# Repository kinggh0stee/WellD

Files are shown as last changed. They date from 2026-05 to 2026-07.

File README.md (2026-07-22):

# WellD

Battery-powered well-level monitor for the ESP32-C6. Each wakeup it reads a 4–20 mA submersible pressure transducer, a DS18B20 temperature probe, and battery voltage; reports them over Zigbee to Zigbee2MQTT; then deep-sleeps until the next cycle.

- **Radio:** Zigbee 3.0 over the C6's built-in 802.15.4 — no extra modules
- **Battery life:** months on a single 18650 cell at the default 5-minute interval (deep sleep between readings)
- **Adaptive sleep:** sleep duration scales with how fast the level is changing — longer windows when stable, shorter during transients
- **Rate-of-change reporting:** `water_level_rate` in cm/h; distinguishes "well recovering" from "well being drawn down"
- **Self-healing:** wipes Zigbee NVS state and rejoins fresh after 5 consecutive send failures
- **OTA:** Zigbee OTA Upgrade client, dual 1.5 MB app slots
- **Sentinels:** open-loop (< 3.5 mA) and short-circuit (> 21 mA) transducer faults both report `null` water level so Home Assistant can alert on wiring faults

---

## Hardware — Custom PCB

The current design is a purpose-built custom PCB (outline set at layout — working target ≈100 × 60 mm, sized around the on-board 18650 carrier). Design files, BOM, and assembly guide live in [`hardware/`](hardware/).

### Key ICs

| IC | Role |
|----|---|
| ESP32-C6 module | MCU + Zigbee radio |
| ADS1115 (0x48) | 16-bit I²C ADC — shunt voltage (AIN0) + battery divider (AIN2) |
| HT7333-A | 3.3 V LDO (≈4 µA Iq, 250 mA, ~90 mV dropout). Replaced the AP63203WU buck in the 2026-07-19 1S conversion — the buck's 3.8 V minimum input fails at 1S empty (3.0 V). Below ≈3.4 V the output follows the battery minus dropout; the ESP32-C6 runs down to 3.0 V |
| MT3608B | 12 V **asynchronous** boost for the 4–20 mA loop supply (VLOOP, GPIO5-gated). D15 (SS34 Schottky) rectifies the switch node; a Q3/Q4 load-disconnect switch in series with L1 blocks the permanent VBAT leak to the loop terminals during deep sleep |
| CN3791 | 1S MPPT solar buck charge **controller** (external SI2319CDS P-FET stage; fixed 4.2 V CV, MPPT ≈5.0 V for 6 V-nominal panels; panel Voc limited to **10 V** by the SMAJ10CA input TVS). A solar-powered LM393 cold-charge cutoff clamps charging below ≈+2 °C — zero battery draw at night |
| TP4056 | USB-C 1 A linear charger (2026-07-19 1S conversion — replaced the IP2326 boost selection, which itself replaced the non-functional TP5100). Auto-charges whenever VBUS is present (CE strapped high); charge-temperature NTC window ≈ +5…+44 °C |
| DW01A + FS8205A | On-board 1S battery protection (supervisor + dual N-FET in the cell− path) — added 2026-07-19 with the generic-18650 carrier; a bare cell has no PCM |

### Test points (production / field debug)

All 15 test point pads are 1.0 mm SMD, **DNF** (do not fit) — bare copper pads suitable for ICT fixture probes or a hook wire. No component is installed in production. Test points are placed scattered near their associated circuits rather than grouped in a single row.

| Ref | Net | Ref | Net |
|-----|-----|-----|-----|
| TP1 | VBAT (3.0–4.2 V, 1S range) | TP9 | I2C SCL |
| TP2 | VLOOP (12 V boost) | TP10 | VSOLAR_IN |
| TP3 | +3V3 | TP11 | VBAT_RAW (before D5 reverse-polarity MOSFET) |
| TP4 | GND | TP12 | ADS1115 DRDY (GPIO22) |
| TP5 | LOOP+ (LOOP_TERM_CH1) | TP13 | FACTORY_RESET (GPIO23 — short to GND while powering on) |
| TP6 | LOOP- (LOOP_TERM_CH2) | TP14 | /CHRG_SOLAR (CN3791 charge status) |
| TP7 | 1WIRE | TP15 | /CHRG_USB (TP4056 charge status, with R38 pull-up) |
| TP8 | I2C SDA | | |

### Thermal improvements

The PCB includes a 10 × 10 mm solid GND copper pour on F.Cu and B.Cu centred on the CN3791 solar charger (U7), connected by four thermal vias (0.6 mm drill / 1.0 mm pad) — the CN3791's integrated switch dissipates in-package, so this pour matters more than it did for the CN3722 controller it replaced. A matching pour under the TP4056 EPAD carries the ≈1.3 W of linear charge dissipation at 1 A. A GND via-stitch ring around the MT3608B / L1 boost island provides a low-inductance return path for the switching node without adding a solid pour under L1.

### GPIO map

| GPIO | Direction | Function |
|---|---|---|
| 18 | SDA | I²C bus (ADS1115 only) — GPIO10/11 are not bonded out on the ESP32-C6-MINI-1 module, so I²C is on GPIO18/19 |
| 19 | SCL | I²C bus (ADS1115 only) |
| 12 | USB | Native USB D− → USB-C (console/programming); from U11 USBLC6 |
| 5  | Output | MT3608B EN + Q4 gate — 12 V loop supply (`VLOOP`), with Q3/Q4 load-disconnect; R27 pull-down holds it off during deep sleep |
| 4  | — | Spare — no schematic connection (the TP4056 USB charger is autonomous, CE strapped high in hardware) |
| 6  | Input  | Solar charger /CHRG (CN3791) — solar-charging-active detect (active-low: LOW = charging; R25 external pull-up) |
| 7  | 1-Wire | DS18B20 data |
| 13 | USB | Native USB D+ → USB-C (console/programming) |
| 22 | Input  | ADS1115 ALERT/DRDY (moved off GPIO12) |
| 23 | Input  | Factory reset (hold LOW at boot → NVS erase + rejoin; via TP13; moved off GPIO13) |
| 15 | Output | Battery-divider enable (`BATT_DIV_EN`) — drives the Q2 level-shifter that switches the Q5 high-side P-FET |
| 14 | — | Status LED (D4 via R14/SJ3 — moved off GPIO13, which is reserved for factory reset; no firmware support yet) |

### Connections (screw terminals)

| Terminal | Wire | ESD / surge protection |
|---|---|---|
| LOOP+ / LOOP− | 4–20 mA transducer, two-wire | D9 / D10 SMAJ3.3CA bidirectional TVS (200 W, DO-214AC); D11 SMAJ13A unidirectional TVS on VLOOP; D1 PRTR5V0U2X rail clamp at ADS1115 inputs |
| 1W DATA / GND | DS18B20 data + ground | D12 PRTR5V0U2X dual-channel rail clamp (SOT-363) — 0.5 pF added capacitance, well below the 800 pF 1-Wire add limit |
| Battery | Single generic 18650 (3.0–4.2 V) in the on-board THT carrier **BT1** — no cable, no connector (the XT30 was deleted 2026-07-19) | On-board 1S protection **DW01A + FS8205A** in the cell− path (generic bare cells have no PCM): over-discharge ≈2.4 V, over-charge ≈4.3 V, over-current. D13 SMAJ5.0A TVS at the cell+ tab; D5 AO3407 P-ch MOSFET in series on cell+ blocks a **reversed-inserted cell**; R31 10 kΩ gate pull-down holds D5 on |
| SOLAR+/− | Solar panel, ≤ **10 V Voc** (6 V-nominal panels — 1S conversion 2026-07-19; the 2S design accepted 12 V panels) | D14 SMAJ10CA bidirectional TVS (400 W, DO-214AC) at the terminal, plus second-stage D8 SMAJ10CA at the CN3791 VIN |

### RF / antenna

The ESP32-C6-MINI-1U-H4 module exposes a U.FL RF port. A ~50 mm internal pigtail — **Taoglas CAB.100.07.0050B** (U.FL female to SMA male, RG178 coax) — connects the module to **J3**, an **Amphenol 132289** SMD edge-launch SMA connector on the top board edge. PCBWay hand-attaches the pigtail after reflow. An external 2.4 GHz SMA antenna (e.g. Taoglas FXP73 rubber-duck, 2 dBi) screws directly onto J3.

### Assembly notes (PCBWay)

Connector placement:

- **Bottom edge (left to right):** J12 (solar, 2-pos), J4 (loop ch1, 3-pos), J5 (loop ch2, 3-pos), J6 (DS18B20, 3-pos), J7 (spare sensor, 3-pos), J10 (programming header, 6-pin 1.27 mm pitch)
- **Left edge:** J13 (USB-C — charging **and** console/programming, SMD; D± wired to the ESP32 native USB pins). The BT1 18650 carrier occupies its own top-side band along one long edge (board size is unconstrained, so the outline grows to fit)
- **Top edge:** J3 (Amphenol 132289 SMA edge-launch)

- **J4, J5, J6, J7, J12** — Phoenix Contact MC 1.5/x-G-3.5 THT terminal blocks, wave-soldered.
- **J10** — 1.27 mm pitch THT vertical programming header (6-pin), wave-soldered.
- **J8, J9** (expansion headers) — **DNF** (do not populate) on all production boards. Footprints are present on the PCB for future use; no components are installed.
- **J3** pigtail — hand-attached by PCBWay post-reflow; not wave-soldered.

### 4–20 mA loop

The MT3608B boost converter lifts VLOOP to 12 V to power the transducer loop. The boost is asynchronous: D15 (SS34 Schottky) carries the switch node to VLOOP, and a Q3 (P-FET) / Q4 (level-shifter) load-disconnect switch in series with the inductor prevents VBAT from leaking through L1 + D15 to the loop terminals during deep sleep. GPIO5 drives both the MT3608B EN and the Q4 gate; R27 pulls the net low while GPIO5 is isolated in deep sleep.

Firmware gates GPIO5 high for **10 ms** (MT3608B soft-start plus rail settling through the Q3 load-disconnect P-FET into C20/C22 — raised from 5 ms in the 2026-07 PCB review) before reading, then drives it low immediately after. Maximum ON time is 100 ms.

The ADS1115 measures the voltage across a shunt resistor on the loop return. PGA ±2.048 V, single-shot at 860 SPS, AIN0 vs GND.

10 nF X7R bypass capacitors (C_SH1 / C_SH2) are placed directly across each 100 Ω shunt resistor (R2 / R4) to suppress HF pickup from the loop cable. The RC corner is ~1.6 MHz, well above the measurement bandwidth.

LOOP+ and LOOP– screw terminals are protected by SMAJ3.3CA bidirectional TVS diodes (D9 / D10, 200 W, DO-214AC/SMA). The 3.3 V standoff is above the normal 2 V loop maximum so the TVS does not conduct in normal operation; the ~5.3 V clamp at 10 A provides tighter protection for the ADS1115 AIN absolute-maximum chain than the previous SMAJ5.0CA devices.

The 1W DATA terminal (J6) is protected by D12, a PRTR5V0U2X dual-channel rail clamp in SOT-363 (the same part as D1 at the ADS1115 inputs). D12 clamps the data line to 3V3 + ~0.5 V during an ESD transient in sub-nanosecond response time. The added capacitance per channel is 0.5 pF, which is negligible compared to the 800 pF DS18B20 bus limit and does not affect 1-Wire timing.

### Battery monitoring

Battery voltage is read via the gated resistor divider (R7 100 kΩ / R8 100 kΩ) on ADS1115 AIN2. The divider is disconnected on the **high side** by Q5 (AO3407 P-FET) between VBAT and R7; GPIO15 drives the Q2 level-shifter (AO3400A) that pulls Q5's gate low. GPIO15 is pulsed HIGH for 1 ms before reading, then LOW immediately after — C8 across R8 is 1 nF so the mid-node settles well inside that 1 ms window. With Q5 off the divider is completely dead: AIN2 rests at 0 V through R8, eliminating sleep leakage into the ADS1115 input ESD diodes. The divider ratio is 2.00 (200/100), mapping 4.2 V full charge to 2.1 V — the firmware reads AIN2 with the ADS1115 **±4.096 V** PGA (the ±2.048 V range used for the loop shunt would clip right at full charge).

The BAT+ rail protection chain: **J1 BAT+ → D13 (SMAJ10CA TVS, at terminal) → D5 S→D (AO3407 reverse-polarity MOSFET) → VBAT system rail.**

D13 is a SMAJ5.0A unidirectional TVS (400 W, DO-214AC/SMA). Its 5 V standoff is above the 4.2 V 1S full-charge voltage so it does not conduct in normal operation; its forward diode clamps negative transients. Cable-induction surges are absorbed before they reach D5 and downstream circuits.

D5 (AO3407, SOT-23) is a P-channel MOSFET placed in series on BAT+. Its body diode blocks reverse current when the battery is connected with reversed polarity; in normal operation the MOSFET is on (Vgs = −Vbat — still twice the −1.5 V Vgs(th) max even at the 3.0 V 1S cutoff, though RDS(on) rises somewhat below the −4.5 V datasheet test point; the drop stays in the tens of millivolts at ≤1 A).

R31 (10 kΩ, 0402) connects D5's gate to GND. R31 holds Vgs = −Vbat so the MOSFET is unconditionally on whenever a battery is present, regardless of firmware state.

### Enclosure

The enclosure is designed in [`hardware/case/welld_case.scad`](hardware/case/welld_case.scad). **No separate battery bay is needed any more** — the single 18650 lives in the top-side on-board carrier (BT1), so the case only has to clear ≈19–21 mm above the board. The external footprint follows the final board outline (unconstrained; working target ≈100 × 60 mm) and is sized at layout time. A USB-C slot on the left short wall accommodates the J13 connector (TP4056 charging **and** USB console/programming via the ESP32 native USB). The case dimensions consume the final board layout, so case work stays last.

For concrete underside mounting, the lid grows four corner wings with M6 anchor-bolt clearance holes. The bolt pattern centre-to-centre span is **127 × 82 mm** (X × Y). Use the `drill_template()` module to print a 1:1 paper/card drill guide before installing anchor bolts.

---

## Quickstart

### Prerequisites

- ESP-IDF **v6.0.1** installed and sourced — see the [Espressif getting-started guide](https://docs.espressif.com/projects/esp-idf/en/v6.0.1/esp32c6/get-started/)
- Custom PCB (or dev board — see legacy section below)

### Build and flash

```bash
git clone https://github.com/kinggh0stee/WellD.git
cd WellD

# one-time: select the target chip
idf.py set-target esp32c6

# local config — copy the template and edit it (gitignored)
cp sdkconfig.defaults.local.example sdkconfig.defaults.local
$EDITOR sdkconfig.defaults.local

# build and flash
idf.py build
idf.py -p /dev/ttyUSB0 flash monitor
```

Or use the interactive menu: `idf.py menuconfig` → **WellD Configuration**.

---

## Configuration

All options have sensible defaults. Only change what differs from your hardware.

### Sensor

| Option | Default | Description |
|---|---|---|
| `CONFIG_WELLD_SENSOR_SHUNT_MILLIOHMS` | `100000` | Loop shunt resistor value in milliohms (100 Ω = `100000`) |
| `CONFIG_WELLD_SENSOR_MAX_DEPTH_CM` | `600` | Full-scale depth at 20 mA, in cm |
| `CONFIG_WELLD_SENSOR_OFFSET_CM` | `0` | Level offset in cm applied after conversion (±600). Persisted in NVS; runtime-writable via `sensor_set_offset_cm()` |
| `CONFIG_WELLD_DS18B20_GPIO` | `7` | GPIO connected to DS18B20 data pin |

### Battery

| Option | Default | Description |
|---|---|---|
| `CONFIG_WELLD_BATT_REPORT_ENABLED` | `y` | Report battery voltage over Zigbee (EP2, Analog Input). The battery is always measured internally via ADS1115 AIN2 (R7/R8 divider) for the low-battery guard; disabling this only removes the Zigbee endpoint |
| `CONFIG_WELLD_BATT_DIVIDER_RATIO` | `200` | Divider ratio × 100 — matches the 100 kΩ / 100 kΩ divider (R7/R8): (100+100)/100 = 2.00 |
| `CONFIG_WELLD_BATT_FULL_MV` | `4200` | Voltage (mV) reported as 100 % by the Z2M converter (1S full charge) |
| `CONFIG_WELLD_BATT_EMPTY_MV` | `3000` | Voltage (mV) at or below which the device skips the Zigbee send and all NVS writes to protect flash (1S minimum safe discharge) |

### Sleep

| Option | Default | Description |
|---|---|---|
| `CONFIG_WELLD_SLEEP_DURATION_SEC` | `300` | Baseline sleep between readings (seconds). When adaptive sleep is enabled, this is the "normal rate" window; the heavy-pumping band targets default/2 (integer division), so very short base values fall below `WELLD_SLEEP_MIN_SEC` and are clamped, making that band unreachable |
| `CONFIG_WELLD_ADAPTIVE_SLEEP_ENABLED` | `y` | Scale sleep duration to the observed level rate-of-change |
| `CONFIG_WELLD_SLEEP_MIN_SEC` | `60` | Lower bound on adaptive sleep (seconds) |
| `CONFIG_WELLD_SLEEP_MAX_SEC` | `1800` | Upper bound on adaptive sleep (seconds) |

### Zigbee

| Option | Default | Description |
|---|---|---|
| `CONFIG_WELLD_ZIGBEE_CHANNEL_MASK` | `0x07FFF800` | Channels to scan; narrow to your coordinator's channel to speed up joins |
| `CONFIG_WELLD_ZIGBEE_SEND_DELAY_MS` | `2000` | Time the stack stays alive after sending, to allow coordinator ACK |

### Hardware I/O

| Option | Default | Description |
|---|---|---|
| `CONFIG_WELLD_I2C_SDA_GPIO` | `18` | I²C SDA pin (ADS1115). GPIO10/11 unavailable on the MINI-1 module |
| `CONFIG_WELLD_I2C_SCL_GPIO` | `19` | I²C SCL pin (ADS1115) |
| `CONFIG_WELLD_VLOOP_GPIO` | `5` | MT3608B EN + Q3/Q4 load-disconnect — 12 V loop supply enable. Held HIGH ≥ 10 ms before any 4–20 mA read (rail settles through the Q3 P-FET into C20/C22) |
| `CONFIG_WELLD_SOLAR_DETECT_GPIO` | `6` | Solar charger /CHRG (CN3791) — solar-charging-active detect (active-low) |
| `CONFIG_WELLD_BATT_DIV_EN_GPIO` | `15` | Battery-divider enable — Q2 level-shifter gate, switching the Q5 high-side P-FET |
| `CONFIG_WELLD_ADS1115_DRDY_GPIO` | `22` | ADS1115 ALERT/DRDY interrupt input (moved off GPIO12, now native USB D−) |

### Advanced / diagnostics

| Option | Default | Description |
|---|---|---|
| `CONFIG_WELLD_ADC_OVERSAMPLE_ENABLED` | `n` | Take 3 ADS1115 samples per measurement and report the median. Opt-in for electrically noisy installations (pump motor interference, long cable runs). Costs ~8 ms extra active time per wakeup; leave off for maximum battery life |
| `CONFIG_WELLD_TEMP_COMPENSATION_ENABLED` | `y` | Apply water-density correction to the level reading: `level / (1 + alpha * (temp - 20))`. Suppressed automatically when DS18B20 fails (temp ≤ −127 °C) |
| `CONFIG_WELLD_TEMP_COMPENSATION_PPM_PER_C` | `207` | Water density coefficient in ppm/°C. Depends on `WELLD_TEMP_COMPENSATION_ENABLED`. Typical value for fresh water is 207 ppm/°C; range 0–500 |
| `CONFIG_WELLD_DS18B20_RESOLUTION_BITS` | `11` | DS18B20 conversion resolution: 9 / 10 / 11 / 12 bit. Conversion time: 94 / 188 / 375 / 750 ms. 11-bit gives 0.0625 °C steps — adequate for well water monitoring and saves 375 ms per wakeup vs 12-bit |
| `CONFIG_WELLD_FACTORY_RESET_GPIO` | `23` | If this GPIO is held LOW at boot, NVS is erased and the device rejoins Zigbee fresh (moved off GPIO13, now native USB D+). Internal pull-up enabled; leave unconnected for normal operation |
| `CONFIG_WELLD_SELFTEST_ENABLED` | `n` | Exercise all peripherals on every boot and log PASS/FAIL. Adds ~200 ms to boot time; useful for factory QA and PCB bring-up |
| `CONFIG_WELLD_DIAGNOSTIC_MODE_ENABLED` | `n` | Stay awake for `WELLD_DIAGNOSTIC_STAY_AWAKE_SEC` after each sensor read, printing verbose logs. Deep sleep is still entered after the window expires |
| `CONFIG_WELLD_DIAGNOSTIC_STAY_AWAKE_SEC` | `60` | Stay-awake window when diagnostic mode is enabled (seconds, 10–300). Depends on `WELLD_DIAGNOSTIC_MODE_ENABLED` |
| `CONFIG_WELLD_ZIGBEE_BACKOFF_MAX_MS` | `500` | Random delay before Zigbee network steering on each wakeup (0–5000 ms). Jitters start time to avoid simultaneous steering from multiple devices after a power outage |
| `CONFIG_WELLD_OTA_STALL_TIMEOUT_SEC` | `240` | Maximum wall-clock time an OTA download may take before it is considered stalled and aborted (60–600 s) |
| `CONFIG_WELLD_RTC_LOG_PRINT_ENABLED` | `n` | Print RTC event log on wakeup — enable when diagnosing a retrieved device over USB; leave off in production |

---

## Zigbee2MQTT integration

### 1. Install the external converter (before pairing)

```bash
cp zigbee2mqtt/welld.js /opt/zigbee2mqtt/data/
```

Add it to `/opt/zigbee2mqtt/data/configuration.yaml`:

```yaml
external_converters:
  - welld.js
```

Restart Zigbee2MQTT:

```bash
sudo systemctl restart zigbee2mqtt
```

### 2. Pair the device

Enable permit-join in `configuration.yaml`, power up the board, and wait for the join. First pairing takes up to 25 s; subsequent wakeups rejoin in a few seconds using cached network state in NVS. Disable permit-join once paired.

### 3. MQTT payload

The device publishes to `zigbee2mqtt/<friendly_name>` on each wakeup:

```json
{
  "water_level": 3.42,
  "water_level_rate": 12.5,
  "temperature": 12.3,
  "battery_voltage": 7.41,
  "battery": 59,
  "zb_fails": 0,
  "device_lqi": 156,
  "solar_charging": false
}
```

- `water_level` is `null` when the pressure loop reads below 3.5 mA (open circuit / broken wire) or above 21 mA (short circuit / shorted transducer). Trigger a Home Assistant alert on `water_level is null` to catch both fault conditions.
- `water_level_rate` is signed cm/h. Positive = recovering, negative = drawing down. Omitted on the first valid wakeup after a cold boot and during open-loop cycles.
- `temperature` is omitted when the DS18B20 is not detected.
- `battery_voltage` comes from the ADS1115 AIN2 voltage divider (R7/R8 100 kΩ / 100 kΩ, switched high-side by Q5 under GPIO15 control).
- `battery` is a percentage derived from `battery_voltage` using the device options `battery_full_mv` / `battery_empty_mv`. Options are coerced to numbers (YAML strings like `"4200"` are accepted) and fall back to the defaults 4200 / 3000 mV for anything missing or non-numeric. If the thresholds are misconfigured (`battery_full_mv <= battery_empty_mv`), the voltage is still published but the percentage is omitted.
- `zb_fails` counts consecutive Zigbee send failures since the last success (0 = healthy; the device auto-rejoins at 5).
- `device_lqi` is the link quality measured on the device side (EP6, 1–255) — the LQI of the device's parent entry in its own neighbor table. It is distinct from Zigbee2MQTT's own `linkquality` field, which comes from the coordinator side of the link. A value of 0 means "unknown" (no parent entry found) and is not published. Firmware ≤ 1.0.2 always sent 0, so the key only appears from firmware 1.0.3 onwards.
- `solar_charging` is a **boolean** (binary expose): `true` = the solar MPPT charger (CN3791) is actively charging, `false` = not charging.
- When previous sends failed, the buffered readings (up to 8, RTC store-and-forward) are burst-reported oldest-first before the current reading, so the coordinator receives the full history in order.
- The converter rejects malformed reports: any non-numeric or non-finite `presentValue` is dropped instead of being published.

### 4. Home Assistant

The Z2M–Home Assistant integration auto-creates these entities:

| Entity | Unit / values |
|---|---|
| `sensor.<name>_water_level` | m |
| `sensor.<name>_water_level_rate` | cm/h |
| `sensor.<name>_temperature` | °C |
| `sensor.<name>_battery_voltage` | V |
| `sensor.<name>_battery` | % (omitted when `battery_full_mv <= battery_empty_mv`) |
| `sensor.<name>_zb_fails` | count, 0–255 |
| `sensor.<name>_device_lqi` | device-side LQI, 1–255 (needs firmware ≥ 1.0.3; 0 = unknown is never published) |
| `binary_sensor.<name>_solar_charging` | on / off |

---

## OTA firmware updates

The device runs a Zigbee OTA Upgrade client. Zigbee2MQTT (`ota: true` in the converter) distributes images automatically once placed in its OTA folder.

### 1. Bump the version

Edit `PROJECT_VER` in the root `CMakeLists.txt`:

```cmake
set(PROJECT_VER "1.0.2")   # MAJOR.MINOR.PATCH
```

The OTA file-version `0xMMmmPP00` (major << 24 | minor << 16 | patch << 8; e.g. `1.0.2` → `0x01000200`) is derived from `PROJECT_VER` at build time — **don't edit `OTA_FW_VERSION` directly.** The build fails loudly on a malformed `PROJECT_VER`.

### 2. Build the OTA image

After `idf.py build`, wrap the binary using `ota_image_create.py` from the esp-zigbee-sdk:

```bash
python path/to/ota_image_create.py \
    --manufacturer-code 0x1234 \
    --image-type 0x0001 \
    --file-version 0x01000200 \
    --output welld-v1.0.2.zigbee \
    build/welld.bin
```

`--manufacturer-code` and `--image-type` **must** match the constants in `components/zigbee/zigbee.c` (`0x1234` / `0x0001`). The device rejects mismatched headers — don't wildcard them to `0xFFFF`.

`--file-version` must increase monotonically and match the `0xMMmmPP00` encoding of `PROJECT_VER`; the device only installs images with a higher version than the running one. (CI derives it automatically and uploads the packed `.zigbee` file as a build artifact.)

### 3. Deploy

```bash
cp welld-v1.0.2.zigbee /opt/zigbee2mqtt/data/ota/
```

Zigbee2MQTT picks the file up automatically. On the next wakeup the device queries for an update, downloads it in 128-byte blocks over Zigbee, and reboots into the new firmware.

> **Upgrading from ≤ 1.0.2:** firmware 1.0.3 adds the battery endpoint (EP2) to the device descriptor. Zigbee2MQTT caches the endpoint list from the original interview, so after the OTA completes, re-interview the device (Z2M frontend → device → *Reconfigure/Interview*, or re-pair) to surface the new `battery_voltage` / `battery` entities. Also note the Kconfig option rename below — a stale `CONFIG_WELLD_BATT_ADC_CHANNEL=-1` line in `sdkconfig.defaults.local` is silently ignored; set `CONFIG_WELLD_BATT_REPORT_ENABLED=n` if you want battery reporting to stay off.

### OTA rollback guard

The firmware tracks consecutive boot failures in RTC memory. If 3 consecutive boots complete without a successful Zigbee send, the device automatically rolls back to the previous image in the **inactive OTA slot** (`esp_ota_get_next_update_partition()` — nothing in this app-level scheme ever marks the old slot invalid, so `esp_ota_get_last_invalid_partition()` would never fire). The rollback is skipped when the inactive slot holds no valid image (first flash), and the boot-attempt counter is cleared before the restart so the rolled-back image doesn't immediately bounce back to the broken slot. This prevents a bad OTA image from permanently bricking the device in the field.

---

## Operations

### Level offset calibration

Use `CONFIG_WELLD_SENSOR_OFFSET_CM` (or `sensor_set_offset_cm()` at runtime) to shift the reported level without moving the transducer. For example, if the transducer hangs 15 cm above the well bottom, set the offset to `-15` to report depth from the bottom of the well.

The offset is persisted in NVS (key `offset_cm` in namespace `welld`) and clamped to ±600 cm.

### Adaptive sleep & rate of change

The device remembers its last valid reading and elapsed time in RTC slow memory (preserved across deep sleep, zeroed on cold boot). At each wakeup it computes a signed rate of change in cm/h and uses it to:

1. **Report `water_level_rate`** to Zigbee2MQTT.
2. **Adjust the next sleep duration** when `CONFIG_WELLD_ADAPTIVE_SLEEP_ENABLED=y`:

   | Rate (cm/h) | Sleep target | Interval at defaults | Condition |
   |-------------|--------------|----------------------|-----------|
   | 0 – 2       | max          | 1800 s | well at rest |
   | 2 – 5       | default × 2  | 600 s  | slow drawdown |
   | 5 – 10      | default      | 300 s  | active pumping |
   | 10 – 20     | default / 2  | 150 s  | heavy pumping |
   | ≥ 20        | min          | 60 s   | rapid event |

   The middle bands scale from `WELLD_SLEEP_DURATION_SEC` (integer division for the /2 band); the result is always clamped to `[WELLD_SLEEP_MIN_SEC, WELLD_SLEEP_MAX_SEC]`, so a very short base value makes the heavy-pumping band collapse into the minimum.

Set `CONFIG_WELLD_ADAPTIVE_SLEEP_ENABLED=n` for a fixed reporting cadence.

### Factory reset

Hold `CONFIG_WELLD_FACTORY_RESET_GPIO` (default GPIO23) LOW during boot to erase NVS and force a clean Zigbee rejoin. On the custom PCB, short the TP13 pad to GND (TP4) while powering on. The internal pull-up is enabled; leaving the pin unconnected causes normal operation. This is the same NVS erase that occurs automatically after 5 consecutive Zigbee send failures.

### I2C bus recovery

On every boot, `sensor_i2c_init()` checks whether SDA is stuck LOW (a common symptom of a previous aborted transaction). If SDA is LOW, it clocks 9 SCL pulses to force any stuck I2C slave to release the bus before initialising the I2C master. This is a no-op under normal conditions.

### Pre-sleep GPIO and I2C cleanup

Before every `esp_deep_sleep()` call, `sensor_pre_sleep_cleanup()` is invoked automatically. It removes the ADS1115 DRDY ISR (GPIO22), deletes the I2C semaphore, and releases the I2C bus handles for GPIO18 (SDA) and GPIO19 (SCL). Without this step the I2C driver retains ownership of those GPIOs across the sleep boundary; the driver context is invalid after wakeup and the bus can be left in a partially-driven state. Combined with `esp_sleep_gpio_isolate()`, all GPIOs are in a defined low-leakage state before the core powers down.

### Low-battery protection

When battery voltage drops **to or below** `CONFIG_WELLD_BATT_EMPTY_MV`, the device skips the Zigbee send and all NVS writes, and sleeps for the maximum interval to conserve charge. The rate history is invalidated entirely on this path — the level can drift arbitrarily far across a low-battery blackout, so the first valid reading after recovery re-seeds the history and reports no rate once (the EP4 report is skipped) instead of producing a false rate spike.

### Expected serial output

Normal cycle:

```
I (sensor): voltage=1485 mV  current=14850 µA  level=3.42 m
I (sensor): temperature=12.3 °C
I (sensor): battery=7.41 V (ADS1115 AIN2)
I (zigbee): joined; reporting level=3.42 m battery=7.41 V temp=12.3 °C rate=12.5 cm/h
I (main):   sleeping 300 s
```

Solar charging active:

```
I (main): solar charging active (solar /CHRG asserted)
```

No coordinator in range:

```
E (zigbee): timeout — no coordinator found
W (main):   Zigbee send failed (1/5)
I (main):   sleeping 300 s
```

After 5 consecutive failures the NVS partition is erased on the next boot, forcing a clean Zigbee rejoin.

Pressure transducer disconnected (open loop, < 3.5 mA):

```
E (sensor): transducer open loop (voltage=12 mV, 120 µA < 3.5 mA)
```

Pressure transducer short circuit (> 21 mA):

```
E (sensor): transducer short-circuit (voltage=2400 mV, 24000 µA > 21 mA)
```

DS18B20 ROM change (sensor replaced):

```
W (sensor): DS18B20 ROM changed: stored=28ff1234ab000002 active=28ff5678cd000003
```

---

## Power

The device spends nearly all of its time in deep sleep. Each wakeup is typically 6–12 seconds of active current (I²C reads, Zigbee send, 1-Wire conversion), followed by a sleep window of 1–30 minutes depending on rate-of-change. At the default 5-minute interval, average current is well under 1 mA — months of runtime on a single 18650 (3.6 V nominal, ≈3–3.4 Ah for a quality generic cell). The HT7333-A LDO's ≈4 µA quiescent current keeps the standby draw negligible, and the Q3/Q5 high-side disconnect switches leave no DC path from VBAT during sleep except the LDO and IC quiescents. Charging is dual-path: solar via the CN3791 MPPT charger and USB-C via the TP4056 (both autonomous — they charge whenever their input is present).

Both power-control GPIOs (VLOOP, BATT_DIV_EN) are driven low and the GPIO matrix is isolated (`esp_sleep_gpio_isolate()`) before every `esp_deep_sleep()` call to eliminate leakage through partially-driven outputs during sleep.

---

## Development

### Project layout

```
main/                    wakeup orchestration, NVS fail counter, RTC history
components/sensor/       I²C (ADS1115), DS18B20, GPIO power control
components/zigbee/       esp-zigbee-lib wrapper, OTA client, BDB commissioning task
components/welld_core/   pure helpers (rate-of-change, adaptive sleep, ZCL encoding)
zigbee2mqtt/welld.js     external converter for Zigbee2MQTT
hardware/pcb/            PCB design reference, BOM, Gerber generation script
hardware/case/           OpenSCAD parametric enclosure (cell lives on the PCB — no battery bay)
test/sensor/             on-device Unity tests (1-Wire, NVS round-trips)
test/welld_core/         on-device Unity tests (rate, sleep, ZCL helpers)
test/host/               host CMake test project — no ESP-IDF required
```

### Host tests

Pure helpers (`sensor_level_from_mv`, `sensor_battery_from_mv`, `sensor_temp_in_range`, `welld_*`) are exercised by a plain CMake project under `test/host/`:

```bash
cmake -S test/host -B test/host/build
cmake --build test/host/build
ctest --test-dir test/host/build --output-on-failure
```

CI runs these on every push. No ESP-IDF or hardware required.

### On-device tests

For NVS round-trips and 1-Wire / ADC paths the host runner can't cover:

```bash
idf.py -C test/sensor build flash monitor
idf.py -C test/welld_core build flash monitor
```

CI builds these to catch compile breaks but cannot execute them (real hardware needed).

### CI

`.github/workflows/build.yml` runs six jobs:

- **ESP-IDF build** — v6.0.1, `esp32c6`, builds firmware and OTA image, uploads `*.bin`, `*.elf`, `*.map`, `*.zigbee`, `dependencies.lock`
- **C static analysis** — cppcheck over all `main/` and `components/` C sources; fails the build on any finding
- **Version bump check** — PR-only gate; fails if firmware sources changed without bumping `PROJECT_VER` in `CMakeLists.txt`
- **Host unit tests** — plain `ubuntu-latest`, ctest, fetches Unity v2.6.0
- **On-device test build** — compile-only check for `test/sensor` and `test/welld_core`
- **Z2M converter tests** — Node 20, `npm test` in `zigbee2mqtt/`

---

## Legacy: dev board wiring

If building from an off-the-shelf ESP32-C6 dev board instead of the custom PCB, wire the pressure transducer shunt directly to an ADC1 pin and power the loop externally. The ADS1115 and MT3608B boost are not available on a bare dev board — configure `CONFIG_WELLD_SENSOR_ADC_CHANNEL` to the ESP ADC channel used and set `CONFIG_WELLD_BATT_REPORT_ENABLED=n` (no battery divider on a bare dev board, so EP2 would only report read errors). The power-control GPIO options (`VLOOP`, `BATT_DIV_EN`) are still compiled in but can be left disconnected if the solar charger is absent.

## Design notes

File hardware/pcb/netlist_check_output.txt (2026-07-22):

pins checked      : 393
intended nets     : 75
extracted nets ok : 75
no-connect pins   : 10

RESULT: zero mismatches — schematic connectivity matches schematic_connections.md table.

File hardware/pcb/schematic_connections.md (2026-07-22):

# WellD Schematic — Net Connectivity Reference

**Wiring status (2026-07-19): the schematic sheets are fully wired — now as a 1S power architecture with an on-board battery carrier.** Every symbol pin carries its connectivity in `power/mcu/sensors/interfaces.kicad_sch` (generated by `kicad_wire_script.py`, machine-verified by `netlist_check.py` — see `netlist_check_output.txt`: **391 pins / 75 nets / 12 no-connects / 0 mismatches** after the 1S conversion + battery carrier + CN3791 correction + solar cold-charge cutoff). This document is a **descriptive reference**; if the sheets and this document ever disagree, treat it as a bug and reconcile (the netlist-vs-doc diff script will flag it).

**Battery architecture (changed 2026-07-19, design changes #18 + #19):** the design is now **1S Li-ion** — a **single generic 18650 cell in an on-board carrier (BT1)**, **VBAT 3.0–4.2 V**. The XT30 pack connector (J1) is deleted, and because a generic bare cell has no PCM, discrete 1S protection (**U13 DW01A + Q6 FS8205A**, the standard TP4056-ecosystem pair) sits between cell− and system GND. The 2S1P architecture (6.0–8.4 V) and its charger chain (IP2326 5 V→2S boost, CN3722 2S MPPT controller + external buck stage, AP63203WU buck) are deleted. **Decision context, for the record:** a runtime analysis slightly favored 2S (≈320 vs ≈300 days per charge); the user explicitly chose 1S anyway ("lets switch this to a 1s design then") for simplicity and parts-ecosystem reasons. 1S is a deliberate product decision — do not re-litigate it in later reviews.

**Connectivity style:** the sheets use *stub + label* connectivity, not point-to-point routed wires — each pin has a short grid-aligned wire stub with a net label (electrically identical for netlisting/ERC):

- **power rails** (`GND`, `+3V3`, `+3V3_ADS`, `VBAT`, `VBAT_RAW`, `VLOOP`, `VUSB`, `VUSB_IN`, `VSOLAR`, `VSOLAR_IN`) → **global labels** (the decorative corner power symbols were removed; `PWR_FLAG` symbols drive ERC on GND / +3V3 / +3V3_ADS / VUSB / VSOLAR);
- **cross-sheet signals** → **hierarchical labels** + matching sheet pins on `welld.kicad_sch`, joined at the root by stubs + local labels;
- **sheet-local nets** → local labels;
- **unused pins** → explicit `(no_connect)` markers. Currently 11: **DW01A TD**, **CN3791 /DONE** (no spare GPIO; pad available for a future TP), **TP4056 /STDBY** (only /CHRG is monitored), ESP32 **GPIO4** (spare) and the phantom **GPIO10 / GPIO11** custom-symbol pins (**not bonded on the MINI-1 module** — they vanish at the official-symbol swap; I²C moved to GPIO18/19), ADS1115 AIN3, D12 IO2, J3 RF pin.

**Convention:** connections below are given by **pin name** (as printed on the symbol), not pin number. Several custom symbols have unverified pin *numbers* — see [Symbol pin-number verification](#symbol-pin-number-verification) before assigning footprints.

---

## Design changes — 2026-07-05 electrical review

| # | Change | Reason |
|---|---|---|
| 1 | **U1 changed AP63205WU → AP63203WU** (fixed 3.3 V); R_FBH/R_FBL marked **DNP** | AP63205 is the **5 V fixed** variant of the Diodes AP6320x family; AP63203 is the 3.3 V fixed variant. The previously specified divider math (0.6 V ref) matches no part in this family (adjustable AP63200 uses a 0.8 V reference). Any of the previous combinations would have put 4.4–8 V on the 3V3 rail and destroyed the ESP32. **Verify against the Diodes datasheet before ordering** (see verification blockers). |
| 2 | **MT3608B topology corrected** (boost: VBAT→L1→SW, not SW→L1→VOUT) and **D15 rectifier + Q3/Q4 load-disconnect added** | The MT3608 family is an async boost: the inductor goes from VIN to SW and an external Schottky (D15) carries SW→VLOOP. Without a disconnect switch, VBAT−0.4 V leaks through L1+D15 to the loop terminals permanently, powering the transmitter during deep sleep and killing the battery. |
| 3 | **Status LED moved GPIO13 → GPIO14** (net renamed `GPIO14_LED`) | At the time, firmware used GPIO13 as the factory-reset strap (a green LED + 1 kΩ to GND would hold it below V_IH → factory reset on every boot). GPIO14 was spare. TP13 added as the factory-reset pad. *(Factory reset later moved to GPIO23 with the 2026-07-22 USB-C change; the LED stays on GPIO14.)* |
| 4 | **Battery divider switched to high-side disconnect** (Q5 P-FET added, Q2 becomes its gate driver); **C8 100 nF → 1 nF** | With the old low-side Q2, the mid node was pulled to VBAT through R7 when disabled, biasing ADS1115 AIN2 above VDD via its ESD diode (~14 µA continuous sleep drain — defeating the purpose of the switch). C8 at 100 nF gave τ ≈ 7.7 ms, far too slow for the firmware's ≥1 ms enable window; 1 nF settles in <1 ms. |
| 5 | **R25 pull-up added on /CHRG_SOLAR** | Gate rule: open-drain outputs need external pull-ups; GPIO6 previously relied on the ESP32 internal ~45 kΩ pull-up only. |
| 6 | **R27 pull-down added on VBOOST_EN** | GPIO5 is isolated (floats) in deep sleep; a floating MT3608B EN (and Q4 gate) could randomly enable the 12 V boost while asleep. |
| 7 | **R15 + C36 added on ESP32 EN** | ESP32-C6-MINI-1U requires an external RC on EN (10 kΩ to 3V3, 1 µF to GND) for a clean power-on reset; only SW1 was present. |
| 8 | **D8/D14 changed SMAJ28CA → SMAJ24CA; C17 uprated to 35 V** | SMAJ28CA standoff equals the CN3722 28 V abs max — zero clamp margin (senior review warning #5). Consequence: max permitted panel Voc is now **24 V** (12 V-nominal panels, Voc ≈ 21–22 V, still fine). C17 at 25 V had no margin over a 24 V standoff rail. |
| 9 | **C25 deleted from power.kicad_sch** (duplicate of C_BST); **C16 assigned as U1 VIN bulk 10 µF** | Resolves senior review warnings #8 and #9; the AP6320x datasheet input cap is 10 µF, previously only 100 nF + 1 µF were fitted. |
| 10 | Refdes reconciliation: `R_CC1/R_CC2` → **R50/R51**, `C14a–C14d` → **C13, C30–C33**, `C_SH1/C_SH2` → **C34/C35**; **R38 is the TP5100 /CHRG pull-up** (the solar /CHRG pull-up is new R25); TP1=VBAT, TP3=+3V3, TP4=GND | Docs referred to symbols that do not exist in the schematics under those names. |
| 11 | **TP5100 USB charge path flagged NON-FUNCTIONAL as designed** | TP5100 is a switching **step-down** (buck) 2S/1S charger. It cannot charge an 8.4 V pack from 5 V USB — VIN must exceed the pack voltage. Superseded by change #12. |
| 12 | **U12 replaced TP5100 → Injoinic IP2326** (5 V→2S synchronous **boost** charger, ESOP-8); **L3 boost inductor added**; R35 repurposed as ISET (value TBD); **R36/R37 deleted — GPIO4/USB_CE freed**; R38 reassigned to the IP2326 status pin; NTC strap placeholder added; **F2 uprated 1.1 A → 2 A hold** (boost input ≈1.9 A at 1 A charge) | Component-selection review 2026-07-05 (`component_selection_review.md` §1). Resolves change #11. IP2326 auto-runs on VBUS — no charge-enable GPIO (⚠️ verify EN absence, plus full pinout/CV/ISET/mid-cell-balance behaviour: blocker #2). Firmware must be told GPIO4 is no longer USB_CE. |
| 13 | **CN3722 CV divider corrected — R33 590 kΩ → 243 kΩ** (CRITICAL, 2026-07-13) | The CV math assumed a 1.205 V FB reference — that is the **CN3791's** reference. The CN3722's **V_FB = 2.416 V** (2.392–2.44, datasheet Rev 1.1). As previously documented, the divider would have regulated the pack at 2.416 × (1 + 5.9) ≈ **16.7 V — destructive for a 2S pack**. Formula: **V_REG = 2.416 × (1 + R_FBH/R_FBL)**. New values: R33 = 243 kΩ (E96) / R34 = 100 kΩ → **8.287 V** (safe margin under 8.40 V). |
| 14 | **CN3722 symbol redrawn as TSSOP-16 + external buck stage added** (M_SOLAR P-FET, D16 series Schottky, D_SOLAR catch Schottky, L_SOLAR, R19 repurposed as R_CS 0.4 Ω, C_VG + COM1/2/3 compensation network, RT_SOLAR NTC on TEMP) | Datasheet Rev 1.1: the CN3722 is a **controller, not an integrated switcher** — DRV (16) drives an external P-FET; charge current is set by a CSP/BAT sense resistor (I_CH = 0.2 V / R_CS → 0.4 Ω = 500 mA), **not** by a "VPROG" resistor (no such pin exists — the old 8-pin symbol was fiction). TEMP (6) gets a real 10 k NTC → cold-charge cutoff (review O-1). Sleep current into BAT pin: 10 µA typ at V_BAT = 12 V (blocker #4a answered — power budget). |
| 15 | **MPPT divider corrected — R20 36 kΩ → 158 kΩ** | Same root cause as #13: the MPPT pin regulates the panel to **1.04 V** at the divider mid-point (not 1.205 V), so the old values would have set V_MP ≈ 4.8 V — below the CN3722's own UVLO (7.5 V min VCC) and useless for charging an 8.4 V pack through a buck. New: V_MP = 1.04 × (1 + 158/10) ≈ **17.5 V**, matching a 12 V-nominal (36-cell) panel, Voc ≤ 24 V. ⚠️ Adjust R20 to the actual panel's V_MP before ordering. |
| 16 | **Symbol reconciliation pass (2026-07-13)** — all BOM-only components now placed as schematic symbols; MT3608B symbol pin numbering fixed (was IN=1/SW=5; now **SW=1, GND=2, FB=3, EN=4, IN=5, NC=6**); IP2326 drawn as the verified 24-pin+EPAD part | Clears senior review 2026-07-06 CRITICAL 1–3 (the layout/ordering gate). Wiring is still doc-driven — this pass places symbols with correct pin definitions and values only. |
| 17 | **Wiring pass (2026-07-13)** — all four sheets fully wired via stub+label connectivity; top sheet rebuilt (rails moved off sheet pins onto global labels; 55 signal sheet pins regenerated); 21 explicit no-connects; PWR_FLAGs added; MT3608B **pin 6 etype changed no_connect → passive** so C_BST can legally attach (doc: "harmless if fitted to an NC pin"); netlist machine-verified against this document (395 pins / 77 nets / 0 mismatches) | Clears senior review 2026-07-06 open item #3 (wire the sheets + netlist-vs-doc diff). New net names minted where the doc had none: `LED_K` (D4 cathode → SJ3), `VLOOP_CH2` (SJ2 → J5 LOOP+), `1WIRE_TERM` (terminal side of R32), `UART_TX_HDR`/`UART_RX_HDR` (SJ4/SJ5 → J10), `J6_VCC`, `D7_A`, `D5_GATE`, `U1_EN`, `AP_SW`, `MT_BST`, `Q3_GATE`, `CC1`/`CC2`, `USB_DP`/`USB_DM`, `USB_BST`, `USB_VSET`, `USB_NTC`, `USB_ISET`, `CN_COM1/2/3`, `COM2_RC`, `LED_A`, `GPIO8`, `GPIO0–3/20/21`. `AP_FB` exists only as the floating DNP divider mid-point (R_FBH.2/R_FBL.1); U1 FB is tied **directly** to +3V3 — fitting the adjustable AP63200 option requires attaching AP_FB to FB and breaking the direct tie. |
| 18 | **1S CONVERSION (2026-07-19)** — pack 2S1P → 1S (VBAT 3.0–4.2 V; battery mechanics finalised in #19). **U12 IP2326 boost-charger subsystem deleted** (U12, L3, R_VSET, C_BST2, C_SYS1/C_SYS2, R35) → **TP4056 1 A linear 1S charger** (SOP-8+EPAD; R_PROG 1.2 kΩ → 1 A; RT1 NTC kept on TEMP with new R_NTC 5.6 kΩ top resistor; CE strapped high; /CHRG → existing /CHRG_USB net). **U7 CN3722 controller + external buck stage deleted** (M_SOLAR, D16, C_COM1/2/3, R_COM2, R33/R34 CV divider) → **CN3791 1S MPPT buck charger** (integrated switch, fixed 4.2 V CV at BAT; D_SOLAR/L_SOLAR/C_VG/RT_SOLAR/R19/R20/R21 kept & repurposed; MPPT set ≈5.0 V for a 6 V panel via R20/R21 = 316k/100k, 1.205 V MPPT reference). **U1 AP63203WU buck deleted** (VIN min 3.8 V fails at 1S empty; L2, C_BST_AP, R_FBH/R_FBL, R11 removed) → **HT7333-A 250 mA LDO** (30 nA-class EN-less part; 3.3 V out, ~90 mV dropout, 4 µA Iq). TVS re-rates: D13 → SMAJ5.0A (VBAT max 4.2 V), D8/D14 → SMAJ10CA (panel ≤6 V nominal). Battery divider R7 330k → **100k** (divide-by-2, firmware ratio 430 → 200). MT3608B VLOOP stage unchanged. GPIO map unchanged (GPIO6 still reads active-low /CHRG_SOLAR; GPIO4 now genuinely spare in hardware). | User decision: 1S chosen deliberately for simplicity/ecosystem after an analysis that slightly favored 2S (≈320 vs ≈300 days runtime). All power-rail ICs reviewed for the 3.0–4.2 V range in the same pass. |
| 19 | **BATTERY CARRIER (2026-07-19)** — the Sinowatt 1S2P pack is dropped for a **single generic 18650 in an on-board THT carrier (BT1**, replaces J1 XT30**)**. Generic bare cells have no PCM → discrete 1S protection added: **U13 DW01A** supervisor + **Q6 FS8205A** dual N-FET in the cell− → GND path (new nets BATT_N / DW_VCC / DW_OD / DW_OC / DW_CS / DW_D; R_DW1 100 Ω + C_DW 100 nF VCC filter, R_CS_DW 1 kΩ on CS — the exact TP4056-module reference topology). D5 reverse-polarity P-FET stays (reverse *insertion* is now a real user risk); D13 SMAJ5.0A stays on VBAT_RAW. RT1/RT_SOLAR thermal coupling target is now the carrier/cell. Capacity ≈3–3.4 Ah (single cell, was ≈6.7 Ah 2P). | Pinouts drawn from the ubiquitous community maps — **verify against the Fortune DW01A-G and FS8205A datasheets before ordering (blocker #11)**. |

---

## Net Inventory

| Net name | Voltage | Description |
|---|---|---|
| GND | 0V | Ground plane |
| +3V3 | 3.3V | Main logic rail (U1 HT7333-A LDO output) |
| VBAT | 3.0–4.2V | 1S2P Li-ion battery (raw, after D5 load-switch) |
| VBAT_RAW | 3.0–4.2V | Cell positive before D5 (BT1 +, D13, D5 drain, R_DW1 feed) |
| BATT_N | ≈0V | Cell negative (BT1 −) — **not** system GND: joined to GND through the Q6 protection FETs |
| DW_VCC | 3.0–4.2V | DW01A supply (R_DW1/C_DW filtered from cell+) |
| DW_OD / DW_OC | gate drive | DW01A discharge/charge FET gate outputs → Q6 G1/G2 |
| DW_CS | ≈0V | DW01A current-sense input (R_CS_DW to system GND) |
| DW_D | ≈0V | Q6 common-drain node (D1+D2 tied) |
| VUSB | 5V | USB-C VBUS after F2 polyfuse |
| VUSB_IN | 5V | USB-C VBUS raw (J13 VBUS pins, before F2) |
| VSOLAR | ≤10V (Voc) | Solar input after D6 diode = CN3791 VCC node (6 V-nominal panel) |
| VSOLAR_IN | ≤10V (Voc) | Solar panel raw (J12 terminal, before D6) |
| VLOOP | 12V ±5% | Boost output (MT3608B + D15), loop power |
| VLOOP_SW | switching | MT3608B SW node (L1 / D15 anode / C_BST) |
| VLOOP_L | 3.0–4.2V gated | Q3 drain → L1 input (boost disconnect branch) |
| +3V3_ADS | 3.3V filtered | ADS1115 VDD (after FB1 ferrite bead) |
| MT_FB | 0.6V | MT3608B feedback divider mid-point (R23/R24) |
| MPPT_REF | 1.205V | CN3791 MPPT (6) divider mid-point (R20/R21 = 316k/100k → V_MP ≈ 5.0 V; ✅ 1.205 V ref datasheet-verified) |
| SOLAR_SW | switching | M_SOLAR drain → D16 anode (external P-FET buck — the CN3791 is a **controller**, verified 2026-07-19) |
| SOLAR_FW | switching | Freewheel node: D16 cathode / D_SOLAR cathode / L_SOLAR in |
| CN_DRV | gate drive | U7 DRV (10) → M_SOLAR gate; R_DRV 300 k gate–source pull-off |
| CN_CS | 3.0–4.2V | Current-sense node: L_SOLAR out / R19 (R_CS 0.1 Ω) / U7 CSP (8); ✅ I_CH = 120 mV/R_CS verified → 1.2 A |
| CN_VG | analog | U7 VG (1) gate-driver regulator — C_VG 100 nF to **VCC** (✅ datasheet-verified) |
| CN_COM / COM_RC | analog | U7 COM (5) loop compensation: 220 nF + 120 Ω series to GND (✅ datasheet values) |
| NTC_T | 0–0.5·VSOLAR | Cold-cutoff temperature node: R_NT1 (30 k) / RT_SOLAR (10 k B3950) divider → U14 IN1+ (ratiometric — threshold independent of panel voltage) |
| NTC_REF | 0.5·VSOLAR | Cold-cutoff reference node: R_NT2/R_NT3 (100 k/100 k) → U14 IN1− (also parks unused IN2−) |
| NTC_OUT | 0/VSOLAR | U14 OUT1 (o.c., R_PU 100 k) → Q7 gate; R_HYS 330 k back to NTC_T gives ≈2 °C hysteresis |
| ADS_DRDY | signal | ADS1115 ALERT/RDY open-drain → GPIO22 (R_DRDY pull-up); moved off GPIO12 = USB D− |
| I2C_SDA | signal | I²C SDA → **GPIO18** (R9 pull-up) — moved off GPIO10 (not bonded on MINI-1, 2026-07-21) |
| I2C_SCL | signal | I²C SCL → **GPIO19** (R10 pull-up) — moved off GPIO11 |
| ADC_CH0 | 0–2.0V | ADS1115 AIN0 (CH1 4-20mA after protection chain) |
| ADC_CH1 | 0–2.0V | ADS1115 AIN1 (CH2 4-20mA after protection chain) |
| ADC_CH2 | 0–2.1V | ADS1115 AIN2 (battery divider mid-point, ÷2) — firmware must use the ±4.096 V PGA range |
| VBAT_SW | 3.0–4.2V gated | Q5 drain → R7 top (battery divider, gated) |
| Q3_GATE / Q5_GATE | analog | P-FET gate nodes (level-shifted from GPIO5 / GPIO15) |
| 1WIRE | signal | DS18B20 data → GPIO7 (R6 pull-up) |
| LOOP_TERM_CH1/2 | signal | 4-20mA SIG inputs from J4/J5 |
| SHUNT_IN_1/2, SHUNT_OUT_1/2 | analog | Shunt chain intermediate nets (see ADC_CH0/1) |
| /CHRG_SOLAR | signal | CN3791 /CHRG (open-drain, active-low) → GPIO6, R25 pull-up |
| /CHRG_USB | signal | TP4056 /CHRG (open-drain, LOW = charging) → R38 pull-up → TP15 only |
| ~~USB_CE~~ | — | **DELETED 2026-07-05** — and finally moot 2026-07-19: TP4056 CE is strapped high in hardware; **GPIO4 is spare, no schematic connection** |
| USB_PROG | analog | TP4056 PROG pin → R_PROG 1.2 kΩ → GND (I_CH = 1200 V·Ω⁻¹… per DS: 1 A at 1.2 kΩ) |
| USB_NTC | analog | TP4056 TEMP pin: R_NTC 5.6k from VUSB, RT1 10k NTC to GND (✅ computed window **+8…+44 °C**) |
| BATT_DIV_EN | signal | GPIO15 → Q2 gate (HIGH enables battery divider via Q5) |
| VBOOST_EN | signal | GPIO5 → MT3608B EN + Q4 gate (HIGH = 12V loop on); R27 pull-down |
| GPIO14_LED | signal | Status LED (GPIO14 → R14 → D4 → SJ3 → GND) |
| FACTORY_RESET | signal | GPIO23 → TP13 pad (hold LOW at boot = NVS erase); moved off GPIO13 = USB D+ |
| UART_TX / UART_RX | signal | Debug UART GPIO16/GPIO17 → SJ4/SJ5 → J10 |
| EN | signal | ESP32-C6 EN (R15 pull-up, C36, SW1, J10) |
| BOOT | signal | ESP32-C6 GPIO9 (R12 pull-up, SW2, J10) |

---

## Net-by-Net Pin Connections

### GND

| Component | Pin | Note |
|---|-----|---|
| U1 HT7333-A | GND (1) | LDO GND |
| U7 CN3791 | GND (2) | Solar charger GND |
| U8 MT3608B | GND | Boost GND |
| U9 ADS1115 | GND **and ADDR** | ADDR→GND sets I²C address 0x48 |
| U6 ESP32-C6-MINI-1U | GND (all) | Module GND + thermal pad |
| U11 USBLC6-2SC6 | GND | USB ESD clamp |
| U12 TP4056 | GND (3) + EPAD | Charger GND + thermal pad (needs copper pour — 1 A linear charge dissipates ≈1.3 W peak; thermal regulation folds back) |
| R_PROG | pin 2 | TP4056 PROG resistor low side (1.2 kΩ → 1 A) |
| RT1 | pin 2 | TP4056 TEMP (pin 1) NTC low side |
| D_SOLAR | anode | CN3791 catch Schottky (cathode → SOLAR_SW) |
| D1, D12 PRTR5V0U2X | GND | Rail clamps |
| R24 | pin 2 | MT3608B FB divider low side |
| R21 | pin 2 | MPPT divider low side |
| R26 | pin 2 | Q2 gate pull-down |
| R27 | pin 2 | VBOOST_EN pull-down |
| R31 | pin 2 | D5 gate pull-down (turns load switch ON) |
| R8 | pin 2 | Battery divider low side (direct to GND — Q2 no longer in this leg) |
| R50, R51 | pin 2 | USB-C CC pull-downs |
| C8 | pin 2 | 1 nF across R8 |
| C9, C10, C16 | pin 2 | U1 VIN decoupling |
| C11, C12, C_BUCK | pin 2 | +3V3 output decoupling |
| C17, C21 | pin 2 | CN3791 VIN filters |
| C18 | pin 2 | CN3791 BAT cap |
| C19 | pin 2 | MT3608B VIN bypass |
| C20, C22 | pin 2 | VLOOP output caps |
| C23, C24 | pin 2 | ADS1115 VDD decoupling (+3V3_ADS side) |
| C13, C30–C33 | pin 2 | ESP32-C6 VCC3V3 decoupling (5 × 100 nF) |
| C15 | pin 2 | ESP32-C6 bulk |
| C36 | pin 2 | ESP32 EN reset-delay cap |
| C27, C28 | pin 2 | VUSB filters |
| C29 | pin 2 | TP4056 BAT-side bypass |
| C3–C6, C34, C35 | pin 2 | 4-20mA filter/bypass caps |
| C7 | pin 2 | J6 VCC bypass |
| R2, R4 | pin 2 (shunt low side) | 4-20mA shunt return |
| D9, D10, D11, D13, D14, D8 | one terminal | TVS clamps (bidirectional except D11 = unidirectional, cathode to VLOOP) |
| Q2 | S | AO3400A source |
| Q6 FS8205A | S2 (6,7) | Protection pair system-GND (P−) side |
| R_CS_DW | pin 2 | DW01A CS sense return |
| R_COM | pin 2 | CN3791 COM compensation network low side |
| RT_SOLAR | pin 2 | Cold-cutoff NTC low side (revived 2026-07-19 for the LM393 cutoff — no longer on a charger TEMP pin) |
| R_NT3 | pin 2 | Cold-cutoff reference divider low side |
| U14 LM393 | GND (4) + IN2+ (5) | Comparator ground; unused IN2+ parked at GND |
| C_NTC | pin 2 | U14 supply bypass |
| Q7 | S | MPPT clamp N-FET source |
| GDT1, GDT2 | pin 2 | GDT coarse surge stage returns (DNF footprints) |
| SW1 | pin 2 | Reset to GND |
| SW2 | pin 2 | Boot to GND |
| D4 | cathode via SJ3 | Status LED return |
| J4, J5 | pin 3 | Loop GND return |
| J6 | pin 3 | DS18B20 GND |
| J7 | pin 3 | Spare GND |
| J8 | GND pin | I²C header |
| J9 | GND pin | GPIO header |
| J10 | GND pin | Programming header |
| J12 | SOLAR− | Solar return |
| J13 | GND (A1/B1 etc.) | USB-C shield/GND |
| J3 | ground ring | SMA GND |
| TP4 | pad | GND test point |

### +3V3

| Component | Pin | Note |
|---|-----|---|
| U1 HT7333-A | VOUT (2) | LDO output — no inductor, no FB divider, no EN pin (always on) |
| C_BUCK, C11, C12 | pin 1 | Output caps at U1 VOUT |
| FB1 | pin 1 | Ferrite feed to +3V3_ADS |
| R9, R10 | pin 1 | I²C pull-ups |
| R_DRDY | pin 1 | ADS_DRDY pull-up |
| R25 | pin 1 | /CHRG_SOLAR pull-up |
| R38 | pin 1 | /CHRG_USB pull-up (to TP15) |
| R6 | pin 1 | 1-Wire pull-up |
| R28 | pin 1 | Feed to J6 VCC (100 Ω series) |
| R12, R13 | pin 1 | BOOT / GPIO8 strapping pull-ups |
| R15 | pin 1 | ESP32 EN pull-up |
| R22 | pin 1 | Solar-charge LED feed (DNF) |
| U6 ESP32-C6-MINI-1U | 3V3 (all) | Module supply |
| C13, C30–C33, C15 | pin 1 | Module decoupling/bulk |
| J7 | pin 1 | Spare sensor supply |
| J8, J9, J10 | 3V3 pin | Headers |
| D1 PRTR5V0U2X | VCC | ADC clamp rail |
| D12 PRTR5V0U2X | VCC | 1-Wire clamp rail |
| TP3 | pad | +3V3 test point |

> **CE network removed (2026-07-05, finally moot 2026-07-19):** R36/R37 belonged to the TP5100 CE pin. The TP4056 (1S conversion) has its CE (pin 8) strapped high to VUSB in hardware — it charges whenever VBUS is present. **GPIO4 is spare with no schematic connection**; the firmware's charger-CE drive was removed with the 1S conversion (no charger GPIO exists).

### +3V3_ADS

| Component | Pin | Note |
|---|-----|---|
| FB1 | pin 2 | Ferrite output |
| U9 ADS1115 | VDD | |
| C23 (100nF), C24 (1µF) | pin 1 | On U9 side of FB1, within 1 mm of VDD |

### VBAT

| Component | Pin | Note |
|---|-----|---|
| D5 AO3407 | S (source) | Load-switch output |
| U1 HT7333-A | VIN (3) | LDO input |
| U7 CN3791 | BAT (10) | Charge-current sense negative input + 4.2 V CV regulation point (pack side of R19/R_CS) |
| R19 (R_CS, 0.1 Ω) | pin 2 | Sense resistor output → VBAT (pin 1 → CN_CS node / U7 CSP) |
| U8 MT3608B | IN | Boost controller supply (stays connected; <1 µA when EN low) |
| Q3 AO3407 | S (source) | Boost inductor disconnect switch input |
| Q5 AO3407 | S (source) | Battery divider disconnect switch input |
| R29 | pin 1 | Q3 gate pull-up |
| R16 | pin 1 | Q5 gate pull-up |
| C9, C10, C16 | pin 1 | U1 VIN decoupling (100n / 1µ / 10µ) |
| C18 | pin 1 | CN3791 BAT cap |
| C19 | pin 1 | MT3608B VIN bypass |
| U12 TP4056 | BAT (5) | Charger output; C29 pin 1 here. ⚠️ Verify BAT-pin dark quiescent with USB absent (datasheet: <2 µA typ) |
| TP1 | pad | VBAT test point (after D5) |
| J9 | VBAT pin (optional) | — only if the header carries VBAT; otherwise omit |

### VBAT_RAW

| Component | Pin | Note |
|---|-----|---|
| BT1 18650 carrier | + (pin 1) | Cell positive (J1 XT30 deleted 2026-07-19 — the carrier is the battery connection) |
| R_DW1 (100Ω) | pin 1 | DW01A VCC filter feed (pin 2 → DW_VCC) |
| D13 SMAJ5.0A | terminal 1 | Battery TVS (other terminal GND) |
| D5 AO3407 | D (drain) | Load-switch input (body diode conducts drain→source at first connect, then channel enhances: gate held at GND by R31, Vgs = −VBAT) |
| D5 AO3407 | G (gate) | → R31 pin 1 (R31 pin 2 → GND) |
| TP11 | pad | Before D5 |

### Battery carrier + 1S protection (BT1 / U13 DW01A / Q6 FS8205A — new 2026-07-19)

A generic bare 18650 has no PCM, so the standard TP4056-ecosystem protection pair sits in the cell− path: `BT1 − (BATT_N) → Q6 S1 → [FET1] → DW_D (D1+D2 tied) → [FET2] → Q6 S2 → GND (P−)`. The DW01A is referenced to the cell (GND pin on BATT_N) and cuts the appropriate FET on over-discharge (≈2.40 V), over-charge (≈4.30 V), or over-current (CS threshold across the FET pair).

| Component | Pin | Connection |
|---|-----|---|
| BT1 | + (1) / − (2) | VBAT_RAW / BATT_N. 18650 carrier, footprint **`Battery:BatteryHolder_Keystone_1042_1x18650`** (KiCad standard, ✅ confirmed 2026-07-21 — no custom draw) |
| U13 DW01A | OD (1) | DW_OD → Q6 G1 (discharge-blocking FET, source at cell−) |
| U13 DW01A | CS (2) | DW_CS → R_CS_DW (1 kΩ) → GND — senses P− relative to cell− across the FET pair |
| U13 DW01A | OC (3) | DW_OC → Q6 G2 (charge-blocking FET, source at P−) |
| U13 DW01A | TD (4) | **NC** (test/delay pin — floats in every reference design) |
| U13 DW01A | VCC (5) | DW_VCC ← R_DW1 (100 Ω) ← VBAT_RAW; C_DW (100 nF) to BATT_N |
| U13 DW01A | GND (6) | BATT_N (cell−) |
| Q6 FS8205A | S1 (2,3) / G1 (4) | BATT_N / DW_OD |
| Q6 FS8205A | S2 (6,7) / G2 (5) | GND / DW_OC |
| Q6 FS8205A | D (1,8) | DW_D — drains are **internally common** (✅ verified); both pins tied on the PCB too |

✅ **Verified 2026-07-19 (blocker #11a/b)**: DW01A pin map (OD=1, CS=2, OC=3, TD=4, VCC=5, GND=6) and thresholds (over-discharge 2.40 V / release 3.0 V; over-charge 4.30 V / release 4.1 V) confirmed against datasheet sources; the 100 Ω/100 nF/1 kΩ network is the documented typical application. FS8205A pin map **corrected** to the real TSSOP-8 layout (D=1&8 internally common, S1=2&3, G1=4, G2=5, S2=6&7; 20 V, ±12 V VGS, ~6 A). The chargers and load all sit on the **system** side (VBAT/GND), so protection trips isolate the cell, exactly as on the pack PCM this replaces.

### VLOOP (12 V boost — corrected topology)

Current path: `VBAT → Q3 (P-FET switch) → L1 → SW node → D15 (Schottky) → VLOOP`

| Component | Pin | Net segment | Note |
|---|-----|---|---|
| Q3 AO3407 | S | VBAT | Disconnect switch |
| Q3 AO3407 | D | VLOOP_L | To inductor |
| Q3 AO3407 | G | Q3_GATE | R29 (100k) to VBAT; Q4 drain pulls low to turn on |
| Q4 AO3400A | D | Q3_GATE | Level shifter |
| Q4 AO3400A | G | VBOOST_EN | With R27 pull-down |
| Q4 AO3400A | S | GND | |
| L1 | pin 1 | VLOOP_L | Inductor input |
| L1 | pin 2 | VLOOP_SW | Switch node |
| U8 MT3608B | SW | VLOOP_SW | Internal low-side switch |
| C_BST | pin 1 / pin 2 | BST ↔ VLOOP_SW | 100 nF; **verify BST pin exists** — classic MT3608 pin 6 is NC (harmless if fitted to an NC pin) |
| D15 SS34 | anode | VLOOP_SW | Boost rectifier |
| D15 SS34 | cathode | VLOOP | |
| C20 (22µF 25V), C22 (10µF 25V) | pin 1 | VLOOP | Output filter |
| R23 (1.91M) | pin 1 | VLOOP | FB divider high side; pin 2 → MT_FB |
| R24 (100k) | pin 1 | MT_FB | pin 2 → GND. VOUT = 0.6 × (1 + 1910/100) = 12.06 V |
| U8 MT3608B | FB | MT_FB | |
| D11 SMAJ13A | cathode | VLOOP | Unidirectional TVS, anode → GND |
| J4 | LOOP+ (pin 1) | VLOOP | CH1 loop power |
| SJ2 | A/B | VLOOP ↔ J5 LOOP+ | Bridged by default; open to isolate CH2 |
| J5 | LOOP+ (pin 1) | via SJ2 | CH2 loop power |
| TP2 | pad | VLOOP | Test point |

### VBOOST_EN

| Component | Pin | Note |
|---|-----|---|
| U6 ESP32-C6 | GPIO5 | Drives HIGH ≥5 ms before a loop read (recommend 10 ms now that C20/C22 charge through Q3) |
| U8 MT3608B | EN | HIGH = boost active |
| Q4 AO3400A | G | Enables Q3 simultaneously |
| R27 (100k) | pin 1 | Pull-down to GND — holds boost + Q3 off while GPIO5 is isolated in deep sleep |
| SJ1 | A/B | Open by default; bridging ties EN permanently to VBAT for bench debug (jumper from EN to VBAT side) |

### VSOLAR / VSOLAR_IN

| Component | Pin | Note |
|---|-----|---|
| J12 | SOLAR+ | Panel input (max Voc **10 V** with SMAJ10CA — 6 V-nominal panels) |
| D14 SMAJ10CA | terminal 1 | First TVS at terminal (other terminal GND) |
| D6 MBRS140 | anode | VSOLAR_IN — backfeed block |
| D6 MBRS140 | cathode | VSOLAR (CN3791 VIN node) |
| D8 SMAJ10CA | terminal 1 | Second-stage TVS at CN3791 VIN (other terminal GND) |
| U7 CN3791 | VCC (9) | Supply input (✅ 4.5–28 V verified; abs max 30 V) |
| M_SOLAR SI2319CDS | S (source) | Buck high-side P-FET input (external stage back — CN3791 is a controller) |
| R_DRV (300k) | pin 1 | Gate–source pull-off (pin 2 → CN_DRV / M_SOLAR gate) |
| C_VG (100nF) | pin 2 | VG bypass returns to **VCC**, not GND (pin 1 → U7 VG (1)) — ✅ verified: "connect 100 nF between VG and VCC" |
| U14 LM393 | VCC (8) | Cold-cutoff comparator supply — **solar-powered: zero draw at night** (C_NTC 100 nF at pin) |
| R_NT1, R_NT2, R_PU | pin 1 | Cold-cutoff divider tops / OUT1 pull-up |
| C17 (10µF **35V**), C21 (100nF 50V) | pin 1 | VIN filters |
| R20 | pin 1 | MPPT divider high side (senses CN3791 VIN node) |
| TP10 | pad | VSOLAR_IN test point at J12 |

### MPPT_REF

| Component | Pin | Note |
|---|-----|---|
| U7 CN3791 | MPPT (1) | Regulates panel to V_MP when divider mid = **1.205 V** (CN3791 reference) |
| R20 (**316k**) | pin 2 | High side from VSOLAR; V_MP = 1.205 × (1 + 316/100) ≈ **5.01 V** (6 V-nominal panel) |
| R21 (100k) | pin 1 | Low side to GND |

> **Re-set 2026-07-19** (1S conversion, design change #18): the CN3791's MPPT reference genuinely is **1.205 V** (unlike the CN3722's 1.04 V — see design change #15 history). ⚠️ Recompute R20 for the actual panel's V_MP before ordering.

### CN3791 — pin map and power stage (SSOP-10; ✅ DATASHEET-VERIFIED + CORRECTED 2026-07-19)

**Correction (datasheet verification pass, 2026-07-19):** the CN3791 is **not** an integrated-switch part — like its CN3722 sibling it is a **controller** whose DRV pin drives an **external P-FET buck stage** (DS: "gate driver … drives the external pass transistor", 40 ns into 2000 pF, gate clamp 8 V). The external stage is restored: `VSOLAR → M_SOLAR (SI2319CDS) → SOLAR_SW → D16 (series Schottky, blocks night back-feed through the FET body diode into the MPPT divider and VCC) → SOLAR_FW → L_SOLAR (47 µH) → CN_CS → R19 (R_CS 0.1 Ω) → VBAT`, `D_SOLAR` freewheeling GND → SOLAR_FW. What it does NOT need vs the CN3722: no CV divider (fixed 4.2 V ±1 % at BAT) and one COM pin instead of three. **It also has NO TEMP pin — see the temperature-cutoff warning below.** Pin map verified against the Consonance datasheet extractions and the Soldered Electronics open-hardware KiCad design:

| U7 pin | Name | Connection |
|---|---|---|
| 1 | VG | C_VG (100 nF) → **VCC** (gate-driver regulator; VG ≈ VCC − 6.3 V, clamped (VCC−VG) ≤ 8 V) |
| 2 | GND | GND |
| 3 | /CHRG | /CHRG_SOLAR net (open-drain, LOW = charging) — R25 pull-up, GPIO6, D7/R22, TP14 |
| 4 | /DONE | Open-drain, LOW = charge done. **NC** (no spare GPIO); pad available for future TP |
| 5 | COM | Loop compensation: C_COM 220 nF in series with R_COM 120 Ω → GND (datasheet-required values) |
| 6 | MPPT | MPPT_REF divider mid (R20/R21 = 316k/100k → V_MP = 1.205 × (1+316/100) ≈ 5.01 V; 1.205 V ref ✅) |
| 7 | BAT | VBAT (pack side of R19) — current-sense negative **and 4.2 V CV point**. Sleep current BAT+CSP ≈ **9 µA at 4.2 V** (power budget) |
| 8 | CSP | CN_CS node (inductor side of R19) — current-sense positive |
| 9 | VCC | VSOLAR (C17/C21/D8 at pin); 4.5–28 V operating, 30 V abs max |
| 10 | DRV | CN_DRV → M_SOLAR gate; R_DRV 300 k gate–source pull-off (per the Soldered reference design) |

**Charge current** (✅ verified): I_CH = 120 mV / R_CS = 120 mV / 0.1 Ω = **1.2 A**. R19: 0.1 Ω 1 % 1206 (P ≈ 0.14 W). Switching frequency 300 kHz.

> ⚠️ **SOLAR-PATH TEMPERATURE CUTOFF REMOVED (design consequence, 2026-07-19):** the CN3791 has no TEMP/NTC pin, so RT_SOLAR is deleted and **solar charging has no cold-charge protection** — on a sub-zero morning with sun, the CN3791 will push up to 1.2 A into a frozen cell (harmful to Li-ion). The TP4056's RT1 window protects only the USB path. Mitigations to weigh before winter deployment: accept the risk (many hobby CN3791 boards do), derate R_CS, or add a discrete NTC-driven cutoff (e.g. an NTC comparator holding /CHRG-side FET off). Recorded as blocker **#10f**.

### Solar cold-charge cutoff (U14 LM393 — NEW 2026-07-19, resolves #10f)

The CN3791 has no TEMP pin, so cold-charge protection is discrete. **Powered from VSOLAR**: at night the whole circuit is dead (D6 blocks the battery; D16 blocks the FET-body back-feed), so it costs **zero** sleep current; in daylight its ~1 mA is free panel power. Both dividers are ratiometric to VSOLAR, so the temperature threshold is independent of panel voltage (valid for VSOLAR ≳ 3 V — below the CN3791's own 4.5 V UVLO anyway).

Operation: cold → RT_SOLAR resistance rises → NTC_T > NTC_REF → OUT1 releases (pulled up by R_PU) → **Q7 clamps the MPPT pin low** → the CN3791 sees a "collapsed panel" and backs the duty cycle to zero — charging stops. Warm → OUT1 sinks low → Q7 off → normal MPPT operation. R_HYS gives ≈2 °C of hysteresis (trip ≈ +2 °C falling, release ≈ +4 °C).

| Component | Pin | Connection |
|---|-----|---|
| U14 LM393 | VCC (8) / GND (4) | VSOLAR / GND; C_NTC 100 nF at VCC. Industry-universal dual-comparator pinout (OUT1=1, IN1−=2, IN1+=3, GND=4, IN2+=5, IN2−=6, OUT2=7, VCC=8) — confirm on the vendor DS at order time |
| U14 | IN1+ (3) | NTC_T: VSOLAR → R_NT1 (30 k) → node → RT_SOLAR (10 k B3950, thermally coupled to the **cell**) → GND. 30 k ≈ NTC at +2 °C |
| U14 | IN1− (2) | NTC_REF: VSOLAR → R_NT2 (100 k) → node → R_NT3 (100 k) → GND (0.5·VSOLAR) |
| U14 | OUT1 (1) | NTC_OUT: R_PU (100 k → VSOLAR) pull-up; → Q7 gate; R_HYS (330 k) positive feedback to NTC_T |
| U14 | IN2+ (5) / IN2− (6) / OUT2 (7) | Unused half: IN2+ → GND, IN2− → NTC_REF (defined state, in common-mode range), OUT2 **NC** |
| Q7 AO3400A | G / D / S | NTC_OUT / **MPPT_REF** / GND — clamps the MPPT divider mid-point below the 1.205 V reference when cold. Note: Vgs ≈ VSOLAR (≤10 V worst case) vs the AO3400A ±12 V abs max — acceptable; revisit if a >6 V-nominal panel is ever specified |

Design notes: the clamp is small-signal (through R20 316 k from VSOLAR) — no power-path contention with the DRV driver; the comparator common-mode (≈0.5·VSOLAR) stays inside the LM393 range (V+ − 1.5 V) for VSOLAR ≥ 3 V. Bench-verify trip/release and zero charge current while clamped (fab checklist row 6).

### /CHRG_SOLAR

| Component | Pin | Note |
|---|-----|---|
| U7 CN3791 | /CHRG (3) | Open-drain, LOW = charging |
| R25 (4.7k) | pin 2 | Pull-up to +3V3 (**new** — was internal-pull-up only) |
| U6 ESP32-C6 | GPIO6 | Input; firmware reads LOW = charging |
| D7 LED | cathode | Solar-charge indicator (green): +3V3 → R22 (1k, **DNF**) → D7 anode; D7 cathode → /CHRG_SOLAR. Lights while charging. DNF by default to save power. |
| TP14 | pad | CHRG_SOL test point |

### VUSB / VUSB_IN / USB-C

| Component | Pin | Note |
|---|-----|---|
| J13 USB-C | VBUS (A4/B4/A9/B9) | VUSB_IN |
| U11 USBLC6-2SC6 | VBUS | ESD clamp on VUSB_IN |
| U11 | IO1 (1/6) / IO2 (3/4) | J13 D− → IO1 (pin 1); IO1' (pin 6) → **ESP32 GPIO12 (USB D−)**. J13 D+ → IO2 (pin 3); IO2' (pin 4) → **ESP32 GPIO13 (USB D+)**. USB-C now carries data (console/programming), not just power |
| F2 polyfuse (2A hold) | pin 1 / pin 2 | VUSB_IN → VUSB (TP4056 draws ≈1 A charge + margin; linear, no boost input multiplication) |
| C27 (4.7µF) | pin 1 | VUSB after F2 |
| U12 TP4056 | VCC (4) | VUSB; C28 (10µF) pin 1 at pin |
| U12 TP4056 | CE (8) | Strapped to VUSB — charge enabled whenever VBUS is present (no GPIO) |
| R_NTC (5.6k) | pin 1 | VUSB → TEMP-node divider top (see TP4056 PROG / TEMP below) |
| J13 | CC1 → R50 (5.1k) → GND; CC2 → R51 (5.1k) → GND | Sink advertising 5 V |

#### TP4056 (U12) — full pin map (SOP-8 + EPAD, 1S conversion 2026-07-19)

The IP2326 boost charger (and its L3 / C_BST2 / C_SYS1 / C_SYS2 / R_VSET / R35 support parts) is **deleted** — a 1S pack charges directly from 5 V USB with a linear charger.

| U12 pin | Name | Connection |
|---|---|---|
| 1 | TEMP | USB_NTC node: R_NTC (5.6 k) from VUSB, RT1 (10 k NTC B3950, thermally coupled to cell) to GND — ✅ **computed** window **+8…+44 °C** (cold trip +7.9 °C at V_TEMP=80 %·VIN → RT1=22.4 k; hot trip +43.7 °C at 45 %·VIN → RT1=4.58 k) (**USB-path charge-temperature cutoff**, review O-1) |
| 2 | PROG | R_PROG 1.2 kΩ → GND. I_CH = 1200 V / R_PROG = **1 A** |
| 3 | GND | GND |
| 4 | VCC | VUSB (C28 10 µF at pin) |
| 5 | BAT | VBAT (C29 10 µF at pin) |
| 6 | /STDBY | **NC** — only /CHRG is monitored |
| 7 | /CHRG | /CHRG_USB net → R38 pull-up → TP15 (open-drain, LOW = charging) |
| 8 | CE | Strapped to VUSB (charge whenever VBUS present — no GPIO, no R36/R37) |
| 9 | EPAD | GND (thermal pour per Group G — 1 A linear charge dissipates ≈1.3 W at mid-charge; the TP4056 thermally regulates ≈120 °C die) |

### ~~USB_CE~~ — deleted 2026-07-05, moot 2026-07-19

R36/R37 were removed with the TP5100; the TP4056's CE is strapped high in hardware. **GPIO4 is spare** with no schematic connection and no firmware driver — free for future use.

### /CHRG_USB

| Component | Pin | Note |
|---|-----|---|
| U12 TP4056 | /CHRG (7) | Charge-status output (open-drain per datasheet, LOW = charging) |
| R38 (4.7k) | pin 2 | Pull-up to +3V3 |
| TP15 | pad | Hardware-only test point (no GPIO) |

### TP4056 PROG / TEMP

| Component | Pin | Note |
|---|-----|---|
| U12 TP4056 | PROG (2) | R_PROG (1.2 kΩ) → GND → **1 A** charge current (I_CH = 1200 V / R_PROG per datasheet; drop R_PROG to 2.4 kΩ → 0.5 A if the enclosure runs hot) |
| U12 TP4056 | TEMP (1) | R_NTC 5.6 k from VUSB + RT1 10 k NTC (B3950, thermally coupled to cell) to GND. Charging suspends when V_TEMP < 45 % or > 80 % of VCC → ✅ **computed window +8…+44 °C** (**charge-temperature cutoff**, `component_selection_review.md` O-1) — **do not strap fixed**. Cold end +8 °C is conservative-safe for Li-ion (below ~+5 °C risks plating); to lower it to ≈+4 °C use R_NTC 6.8 k, but that pulls the hot end to +39 °C |

> **2026-07-19 (1S conversion):** U12 is now the ubiquitous NanJing/TPower TP4056 in SOP-8 with exposed pad (footprint `Package_SO:SOIC-8-1EP_3.9x4.9mm_P1.27mm_EP2.29x2.29mm`). The load-during-charge caveat applies (no power-path): the device's wake cycle draws from BAT while charging, which can marginally extend the CV tail — acceptable at a ~seconds-per-hour duty cycle.

### HT7333-A LDO (U1) — 1S conversion 2026-07-19

The AP63203WU buck (VIN min 3.8 V — fails at 1S empty) is **deleted** along with L2, C_BST_AP (net AP_BST), R_FBH/R_FBL, and R11. The 3.3 V rail is now a Holtek HT7333-A LDO (SOT-23: GND=1, VOUT=2, VIN=3): ~4 µA Iq, ~90 mV dropout, **250 mA max** — sufficient for Zigbee-only operation (802.15.4 TX ≈ 80 mA); Wi-Fi must stay disabled (it already is). Below ≈3.4 V input the output follows VBAT minus dropout; the ESP32-C6 operates down to 3.0 V.

| Component | Pin | Note |
|---|-----|---|
| U1 | VIN (3) | VBAT; C9/C10/C16 at pin |
| U1 | VOUT (2) | +3V3 rail (C_BUCK/C11/C12 here) |
| U1 | GND (1) | GND |

### ADS_DRDY

| Component | Pin | Note |
|---|-----|---|
| U9 ADS1115 | ALERT (pin 2) | Open-drain conversion-ready |
| R_DRDY (4.7k) | pin 2 | Pull-up to +3V3 |
| U6 ESP32-C6 | **GPIO22** | Falling-edge interrupt (moved off GPIO12 = native USB D−, 2026-07-22) |
| TP12 | pad | Test point |

### I2C_SDA / I2C_SCL

| Component | Pin | Note |
|---|-----|---|
| U9 ADS1115 | SDA (pin 9) / SCL (pin 10) | True TI MSOP-10 numbering: ADDR=1, ALERT=2, GND=3, AIN0=4, AIN1=5, AIN2=6, AIN3=7, VDD=8, SDA=9, SCL=10 |
| U6 ESP32-C6 | **GPIO18** (SDA) / **GPIO19** (SCL) | Moved off GPIO10/11 — **not available on the ESP32-C6-MINI-1 module** (verified against the official Espressif KiCad symbol, 2026-07-21) |
| R9 / R10 (4.7k) | pin 2 | Pull-ups to +3V3 |
| J8 | SDA/SCL pins | I²C header (DNF): 3V3 / GND / SDA / SCL |
| TP8 / TP9 | pads | Test points |

### ADC_CH0 / ADC_CH1 (4-20 mA inputs)

CH1 path: `J4 SIG → D9 clamp → R2 shunt (‖ C34) → R3 → ADC_CH0 (C3, C4, D1 ch.1) → U9 AIN0`

| Component | Pin | Net segment | Note |
|---|-----|---|---|
| J4 | SIG (pin 2) | LOOP_TERM_CH1 | Loop return from transmitter |
| D9 SMAJ3.3CA | terminal 1 | LOOP_TERM_CH1 | Clamp to GND |
| R2 (100Ω 0.1%) | pin 1 | LOOP_TERM_CH1 | Shunt top; **pin 2 → GND** (loop current returns through R2) |
| C34 (10nF) | pins 1–2 | across R2 | HF bypass, within 1 mm |
| R3 (100Ω) | pin 1 | LOOP_TERM_CH1 (shunt top) | Series limiter |
| R3 | pin 2 | ADC_CH0 | |
| C3 (1µF), C4 (10µF) | pin 1 | ADC_CH0 | RC filter / bulk |
| D1 PRTR5V0U2X | IO1 | ADC_CH0 | Clamp to +3V3/GND |
| U9 ADS1115 | AIN0 | ADC_CH0 | 20 mA × 100 Ω = 2.0 V max, PGA ±2.048 V |
| TP5 | pad | LOOP_TERM_CH1 | At shunt top |
| GDT1 (DNF) | pin 1 | LOOP_TERM_CH1 | 2-pole 90 V gas discharge tube to GND (pin 2) — coarse stage of the industrial GDT → series-R → TVS coordination; footprint only, populate per site for long/buried cable runs |

CH2 identical: `J5 SIG → D10 → R4 (‖ C35) → R5 → ADC_CH1 (C5, C6, D1 IO2) → U9 AIN1`, TP6 at shunt top, GDT2 (DNF) from LOOP_TERM_CH2 to GND.

### ADC_CH2 (battery divider — corrected high-side gating)

Path: `VBAT → Q5 (P-FET) → R7 (100k) → mid (ADC_CH2) → R8 (100k) → GND` (÷2 for 1S, changed 2026-07-19 — was 330k/100k ÷4.3 for 2S)

| Component | Pin | Note |
|---|-----|---|
| Q5 AO3407 | S | VBAT |
| Q5 AO3407 | D | VBAT_SW → R7 pin 1 |
| Q5 AO3407 | G | Q5_GATE: R16 (100k) to VBAT; Q2 drain pulls low to enable |
| Q2 AO3400A | D | Q5_GATE |
| Q2 AO3400A | G | BATT_DIV_EN (GPIO15), R26 (4.7k) pull-down |
| Q2 AO3400A | S | GND |
| R7 | pin 2 | ADC_CH2 (mid) |
| R8 | pin 1 / pin 2 | mid / GND |
| C8 (**1 nF**) | pins 1–2 | across R8 — τ ≈ 50 µs (R7‖R8 = 50 k), settles well inside the 1 ms firmware enable window |
| U9 ADS1115 | AIN2 | 4.2 V × 100/200 = **2.1 V max — exceeds the ±2.048 V PGA range**; ❗ firmware must select the **±4.096 V PGA** for the AIN2 read (1S firmware-handoff item, with `CONFIG_WELLD_BATT_DIVIDER_RATIO` 430 → 200) |

> With Q5 off, the divider is fully dead: AIN2 rests at 0 V through R8 and there is no sneak path into the ADS1115 ESD diodes (the old low-side switch leaked ~14 µA into AIN2 during sleep).

### 1WIRE

| Component | Pin | Note |
|---|-----|---|
| J6 | DATA (pin 2) | DS18B20 data |
| D12 PRTR5V0U2X | IO1 | Clamp at terminal (IO2 = NC) |
| R6 (4.7k) | pin 2 | Pull-up to +3V3 |
| R32 (33Ω, **populate**) | pin 1 / pin 2 | Terminal side / GPIO side series resistor |
| U6 ESP32-C6 | GPIO7 | 1-Wire master |
| TP7 | pad | GPIO7 side of R32 |
| J6 VCC (pin 1) | ← R28 (100Ω) ← +3V3 | C7 (100nF) at J6 pin 1. External power mode only |

### EN (ESP32 reset)

| Component | Pin | Note |
|---|-----|---|
| U6 ESP32-C6 | EN | |
| R15 (10k, **new**) | pin 2 | Pull-up to +3V3 |
| C36 (1µF, **new**) | pin 1 | To GND — 10 ms power-on delay |
| SW1 | pin 1 | Push to GND = reset |
| J10 | EN pin | Programming header |

### BOOT

| Component | Pin | Note |
|---|-----|---|
| U6 ESP32-C6 | GPIO9 | Strapping (LOW = download mode) |
| R12 (10k) | pin 2 | Pull-up to +3V3 |
| SW2 | pin 1 | Push to GND |
| J10 | GPIO9 pin | |

GPIO8 strapping: R13 (10k) pull-up to +3V3, no other connection.

### GPIO14_LED (status LED — moved off GPIO13)

| Component | Pin | Note |
|---|-----|---|
| U6 ESP32-C6 | **GPIO14** | LED drive (was GPIO13 — conflicted with factory-reset strap) |
| R14 (1k) | pin 1 / pin 2 | GPIO14 / D4 anode |
| D4 green | cathode | → SJ3 → GND (SJ3 bridged; open to save current) |

### FACTORY_RESET

| Component | Pin | Note |
|---|-----|---|
| U6 ESP32-C6 | **GPIO23** | Internal pull-up at boot; hold LOW ≥ boot = NVS erase + rejoin (moved off GPIO13 = native USB D+, 2026-07-22) |
| TP13 (**new**) | pad | Field-accessible pad — short to TP4/GND while powering on |

### UART_TX / UART_RX

| Component | Pin | Note |
|---|-----|---|
| U6 ESP32-C6 | GPIO16 (TX) / GPIO17 (RX) | UART0 default pins |
| SJ4 / SJ5 | A→B | In series to J10 (bridged by default — see resolution table on jumper variant) |
| J10 | TX/RX pins | Programming header: TX / RX / GND / 3V3 / GPIO9 / EN |

### J7 spare sensor / J9 GPIO header

- J7: pin 1 = +3V3, pin 2 = GPIO3 (spare ADC), pin 3 = GND.
- J9 (8-pin, DNF): +3V3, GND, GPIO0, GPIO1, GPIO2, GPIO3, GPIO20, GPIO21.

### RF

`U6 U.FL pad → W1 pigtail (hand-fitted) → J3 SMA`. J3 RF pin has no PCB trace; GND ring to plane.

---

## Power-On Sequence Reference

1. Cell inserted into BT1 → DW01A powers from cell+ (R_DW1/C_DW) and enables both Q6 FETs (BATT_N ≈ GND) → VBAT_RAW → D5 body diode conducts, then channel enhances (gate at GND via R31) → VBAT. A reversed cell is blocked by D5; a deeply-discharged cell is isolated by the DW01A until a charger raises it.
2. U1 HT7333-A LDO regulates (no EN pin — always on) → +3V3 → C36/R15 delay → ESP32 boots.
3. Boost idles: R27 holds MT3608B EN + Q4 low. Both chargers are autonomous — CN3791 charges whenever panel power is present, TP4056 whenever VBUS is present (CE strapped high; no enable GPIOs).
4. Firmware: GPIO5 HIGH → U8 EN + Q4 → Q3 closes → VLOOP = 12 V (allow ≥5 ms, recommend 10 ms for C20/C22 charge through Q3) → loop read → GPIO5 LOW.
5. Firmware: GPIO15 HIGH → Q2 → Q5 closes → divider live (settles < 1 ms with C8 = 1 nF) → AIN2 read → GPIO15 LOW.
6. Deep sleep: all control GPIOs driven LOW then isolated; R27/R26/R31 define every switch state passively. No DC path from VBAT except U1 (4 µA Iq) and IC quiescents.

---

## Symbol pin-number verification

Wiring above uses **pin names**. Before assigning footprints / generating a netlist, verify these symbol pin **numbers** against datasheets — several are known or suspected wrong:

| Symbol | Status |
|---|---|
| welld:ADS1115 | ✅ matches TI MSOP-10 (ADDR=1 … SCL=10) |
| welld:AO3407 | ✅ G=1, S=2, D=3 (SOT-23) |
| welld:HT7333A (U1) | ✅ **verified 2026-07-19** (blocker #10d): SOT-23, GND=1, VOUT=2, VIN=3 confirmed (multiple datasheet sources; same pinout as XC6206). 3.5–4 µA Iq, VIN ≤ 12 V, dropout ≈60 mV @ 100 mA, ±2–3 % |
| welld:MT3608B | ✅ **datasheet-confirmed 2026-07-14**: SW=1, GND=2, FB=3, EN=4, IN=5, NC=6 — third independent source (KiCad official `MT3608` symbol, librarian-reviewed against the Aerosemi PDF) agrees with both prior reviews. Bench caveat downgraded to routine first-article check |
| welld:USBLC6_2SC6 | ✅ **fixed 2026-07-14 follow-up**: renumbered to the ST map (1=I/O1, 2=GND, 3=I/O2, 4=I/O2', 5=VBUS, 6=I/O1') |
| welld:DW01A (U13) | ✅ **verified 2026-07-19** (web datasheet sources, blocker #11a): SOT-23-6, OD=1, CS=2, OC=3, TD=4 (NC), VCC=5, GND=6; trip 2.40/4.30 V, release 3.0/4.1 V |
| welld:FS8205A (Q6) | ✅ **verified + REDRAWN 2026-07-19** (blocker #11b — first draw was wrong): TSSOP-8, **D=1, S1=2, S1=3, G1=4, G2=5, S2=6, S2=7, D=8**, drains internally common. Two independent sources agree |
| welld:LM393 (U14) | ⚠️ **drawn 2026-07-19** (solar cold-cutoff): SOIC-8, OUT1=1, IN1−=2, IN1+=3, GND=4, IN2+=5, IN2−=6, OUT2=7, VCC=8 — the industry-universal dual-comparator map (same as LM358); confirm on the chosen vendor's datasheet at order time |
| welld:TP4056 (U12) | ✅ **verified 2026-07-19** (blocker #10a): SOP-8+EPAD, TEMP=1, PROG=2, GND=3, VCC=4, BAT=5, /STDBY=6, /CHRG=7, CE=8, EPAD=9 confirmed (datasheet sources). TEMP window 45–80 % of VIN (>0.15 s); LCSC **C16581** (TP4056-42-ESOP8, TopPower/NanJing) |
| welld:CN3791 (U7) | ✅ **verified + REDRAWN 2026-07-19** (blocker #10b — first draw was wrong in numbering AND function set): SSOP-10, **VG=1, GND=2, /CHRG=3, /DONE=4, COM=5, MPPT=6, BAT=7, CSP=8, VCC=9, DRV=10** (datasheet extractions + the Soldered Electronics open-hardware KiCad design). It is a **controller** (external P-FET on DRV) with **no TEMP pin** |
| welld:PRTR5V0U2X | ❌ **verified WRONG 2026-07-14** — real part is SOT-143B, 4 pins: **1=GND, 2=I/O1, 3=I/O2, 4=VCC** (Nexperia DS + KiCad official lib; footprint `Package_TO_SOT_SMD:SOT-143`). ✅ **redrawn 2026-07-14 follow-up** as 4-pin SOT-143B (phantom VCC2/GND2 pins + stubs removed), footprint `Package_TO_SOT_SMD:SOT-143`. LCSC is **C12333** (PRTR5V0U2X,215) — the BOM's old C2687116 was a UMW USBLC6-2SC6 clone |
| welld:ESP32_C6_MINI_1U | ⚠️ **custom pin numbering is WRONG throughout** (verified 2026-07-21 against the official Espressif `ESP32-C6-MINI-1/U` KiCad symbol) — replace with the official symbol/footprint before layout. **Critical finding**: the module does **not bond out GPIO10 or GPIO11** (present on the bare chip only); the design's I²C bus was on those pins and has been **moved to GPIO18/GPIO19** (firmware + schematic + docs updated). Full net→pin map for the swap is in the table below. |

### ESP32-C6-MINI-1 net → official pin map (for the symbol swap)

When replacing `welld:ESP32_C6_MINI_1U` with Espressif's official `ESP32-C6-MINI-1` symbol, attach each net to the pin below (sorted by official module pin number). Verified 2026-07-21 against Espressif's KiCad symbol; nets read from `kicad_wire_script.py`.

| Official pin | Net | GPIO | Note |
|---|-----|---|---|
| 1 (+ 2, 4, 7, 11, 14, 21, EPAD) | `GND` | — | all module GND pads + thermal pad |
| 3 | `+3V3` | — | module supply |
| 5 | `GPIO2` (header J7/J9) | 2 | ADC1_CH2 |
| 6 | `GPIO3` (header, spare ADC) | 3 | ADC1_CH3 |
| 8 | `EN` | — | CHIP_PU; R15 pull-up + C36 |
| 9 | *(unconnected — spare)* | 4 | — |
| 10 | `VBOOST_EN` | 5 | MT3608B EN + Q4 |
| 12 | `GPIO0` (header) | 0 | strapping / XTAL_32K_P |
| 13 | `GPIO1` (header) | 1 | XTAL_32K_N |
| 15 | `/CHRG_SOLAR` | 6 | solar-charge detect input |
| 16 | `1WIRE` | 7 | DS18B20 |
| 17 | `USB_DM` | 12 | **native USB D−** ← U11.6 (USB-C console/programming) |
| 18 | `USB_DP` | 13 | **native USB D+** ← U11.4 (USB-C console/programming) |
| 19 | `GPIO14_LED` | 14 | status LED |
| 20 | `BATT_DIV_EN` | 15 | JTAG-source strap, held low by R26 — harmless (output; no JTAG used) |
| 22 | `GPIO8` | 8 | boot strapping pin, R13 pull-up |
| 23 | `BOOT` | 9 | boot strapping pin, R12 pull-up + SW2 |
| 24 | `I2C_SDA` | 18 | moved off GPIO10 (not bonded on MINI-1) |
| 25 | `I2C_SCL` | 19 | moved off GPIO11 (not bonded on MINI-1) |
| 26 | `GPIO20` (header) | 20 | — |
| 27 | `GPIO21` (header) | 21 | — |
| 28 | `ADS_DRDY` | 22 | **moved off GPIO12** (now USB D−) — DRDY interrupt input |
| 29 | `FACTORY_RESET` | 23 | **moved off GPIO13** (now USB D+) — hold LOW at boot |
| 30 | `UART_RX` | 17 | U0RXD |
| 31 | `UART_TX` | 16 | U0TXD |

**USB-C console/programming — APPLIED 2026-07-22 (user decision):** the USB-C data lines (D±), previously dead-ended at U11 USBLC6, are now routed through to the module's native USB pins — U11.6 → GPIO12 (D−), U11.4 → GPIO13 (D+). This gives programming + serial console + USB-DFU over the same USB-C used for charging. To free the USB pins, `ADS_DRDY` moved GPIO12→**GPIO22** and `FACTORY_RESET` moved GPIO13→**GPIO23** (both clean pins: no strap, no USB, no JTAG). Firmware defaults updated (`WELLD_ADS1115_DRDY_GPIO`=22, `WELLD_FACTORY_RESET_GPIO`=23). No spare GPIOs remain unused except pin 9 (GPIO4).

---

## Datasheet verification blockers (resolve before tape-out)

1. **U1 identity — ✅ RESOLVED 2026-07-14, then OBSOLETE 2026-07-19**: the AP63203WU (VIN min 3.8 V) cannot serve a 1S pack that discharges to 3.0 V — deleted in the 1S conversion together with L2 / C_BST_AP / R_FBH / R_FBL / R11. U1 is now the HT7333-A LDO (see 1S blocker #10d for its verify items). Historical AP63203 findings preserved in `component_verification_2026-07-14.md`.
2. **U12 IP2326 — OBSOLETE 2026-07-19**: deleted in the 1S conversion (a 1S pack charges from 5 V USB with a linear TP4056 — no boost topology). Historical resolution trail kept below for the record; none of it applies to the TP4056 (see 1S blocker #10a):
   - **2a. Mid-cell/balance pin — ✅ RESOLVED 2026-07-06**: VBATM (pin 23) and VBAT_GND (pin 24) "should be left floating when doesn't use" per the IP2326 V1.2 datasheet. The 2-pin XT30 pack works unchanged with balancing disabled. Charger choice stands.
   - 2b. **✅ RESOLVED 2026-07-14**: package is **QFN24, 4×4 mm, 0.5 mm pitch, EPAD 2.5×2.5 mm nom (2.4–2.6), height 0.75 mm** — datasheet V1.2 §11 package drawing, confirmed by the LCSC C2832094 listing ("4×4mm QFN24"). Draw `welld:IP2326_TBD` from KiCad standard `Package_DFN_QFN:QFN-24-1EP_4x4mm_P0.5mm_EP2.6x2.6mm`. Hand-rework = hot-air only (leadless + EPAD). Do not order the similarly-listed IP2326-NPD (C5441281).
   - 2c. ✅ RESOLVED 2026-07-06/13: CV set by VSET strap; **R_VSET = 120 kΩ → 8.3 V typ / 8.4 V max** (symbol placed). NC strap is unsafe (8.5 V max).
   - 2d. ✅ RESOLVED 2026-07-06/13: I_CH = 90000/R_ISET; **R35 = 90 kΩ → 1 A** (symbol value updated).
   - 2e. EN/CE pin — ✅ RESOLVED 2026-07-06: **EN exists (pin 12)**, pull-low-to-disable, float = enabled. Decision: leave floating (auto-charge on VBUS), GPIO4 stays freed. Polarity matches the old TP5100 CE drive, so GPIO4→EN is a zero-firmware-change option later. Package is **24-pin + EPAD, not ESOP-8** — see component_selection_review.md 2026-07-06 addendum for the full verified pin map, RVSET=120k CV correction (NC strap maxes at 8.5 V — unsafe for 2S), RISET=90k (1 A), and the NTC pin path to the sub-zero cutoff.
   - 2f. ✅ RESOLVED 2026-07-13: NTC = pin 4 (20 µA source); **RT1 placed as a real 10 k NTC** to be thermally coupled to the pack (blocker #7 / review O-1).
   - 2g. VOUT-pin quiescent with USB absent — must be < 10 µA (nightly battery drain). Bench item.
   - 2h. Input-adaptive current limiting behaviour on weak 5 V sources (we advertise only default USB via 5.1 k CC sinks) — bench item. DM/DP wiring **decided 2026-07-13: float** (no-connects; reversible, see IP2326 pin map).
   - 2i. **✅ RESOLVED 2026-07-14** (datasheet §10 reference BOM): C28 = 10 µF at VIN, C29 = 10 µF at VOUT (ref design adds 22 µF in parallel — C29 + battery suffices at 1 A), values confirmed — **but all VIN/VSYS/VOUT caps must be ≥25 V rated** ("capacitor's voltage higher than 16 V is required") → uprate C28 (was 10 V), C29 and C_SYS1/C_SYS2 (were 16 V) to 25 V. L3 note: the ref BOM asks **Isat/Idc > 5 A, DCR < 20 mΩ** (sized for 2 A charge); at our 1 A setpoint the chosen SWPA5040S2R2NT (3.8 A / 25 mΩ) has ≈1.6× peak margin — do not raise RISET above 90 k without resizing L3. Status-pin type for R38 remains a bench item (2g/2h/BAT_STAT polarity).
   - 2j. **✅ RESOLVED 2026-07-14**: LCSC **C2832094**, in stock, ~$0.30 @ 1.
3. **U8 MT3608B — pin map ✅ RESOLVED 2026-07-14**: SW=1, GND=2, FB=3, EN=4, IN=5, NC=6 confirmed by a third independent source — the KiCad official `MT3608` symbol (librarian-reviewed against the Aerosemi datasheet; FB 0.6 V ref matches R23/R24). Bench caveat downgraded to a routine first-article continuity check; C_BST on the confirmed-NC pin 6 can go DNF. Still bench items: EN-low shutdown current (<1 µA assumed in the sleep budget) and switch-limit details. D15 + Q3/Q4 disconnect remain required.
4. **U7 CN3722 — ✅ RESOLVED 2026-07-13, then OBSOLETE 2026-07-19**: deleted in the 1S conversion along with its entire external buck stage (M_SOLAR, D16, L-C compensation, CV divider). U7 is now the CN3791 integrated-switch 1S MPPT charger — its open verifications are 1S blocker #10b. One CN3722 lesson carries over: **check the CN3791 BAT-pin dark quiescent on the bench** (the CN3722 drew 10 µA typ; the nightly budget assumes the CN3791 is similar or better, and D6 still blocks the battery→VIN back-feed path).
5. **ESP32-C6-MINI-1U**: replace custom symbol with the Espressif library part. (LCSC number corrected 2026-07-14: **C20627095**, not C2913202. PRTR5V0U2X half of the old blocker resolved — see the symbol table: SOT-143B, 1=GND/2=I/O1/3=I/O2/4=VCC, LCSC C12333. USBLC6-2SC6 pinout also resolved — see symbol table.)
6. **D9/D10 SMAJ3.3CA leakage — ❌ FAILED / ✅ RESOLVED BY SUBSTITUTION 2026-07-14**: the SMAJ datasheet specs IR = **800 µA max at VRWM 3.3 V** with VBR min only 3.67 V — ≤1 µA at the 2.0 V node / 60 °C is not guaranteeable (soft knee, leakage ~doubles per 10 °C). **REQUIRED value edit: D9/D10 → SMAJ5.0A** (VBR min 6.4 V puts the 2.0 V working point 4.4 V below the knee; Vc 9.2 V — R3/R5 + D1 still protect the ADS1115 pins; the forward diode clamps negative transients). ST SMAJ5.0A-TR, LCSC **C98802**.
7. **Charge-temperature and cell-current limits**: (a) **OBSOLETE 2026-07-19 (battery-carrier change)** — there is no pack and no vendor PCM to ask about; protection is the on-board DW01A/FS8205A (blocker #11) and the current question becomes cell-level: co-charge worst case TP4056 1 A + CN3791 ≈1.2 A ≈ 2.2 A into a **single ≈3.4 Ah cell is ≈0.65C** — at the top of standard-charge range for generic 18650s. **Prefer a quality high-rate cell, or drop R_PROG to 2.4 kΩ (0.5 A USB) if the cell runs warm under co-charge**; (b) ✅ resolved via RT1/RT_SOLAR NTCs (MPN picked 2026-07-14: Sunlord **SDNT1608X103F3950FTF**, 10 k 1 % B3950 0603) — thermally couple both to the carrier/cell.
8. **F2 replacement PTC — ✅ RESOLVED 2026-07-14**: **Bourns MF-MSMF250/16X-2** — 2.5 A hold / 5.0 A trip / 16 V / 100 A max / 15 mΩ, **1812** (4.83×3.41 mm), −40…+85 °C, LCSC **C210838** (in stock). Footprint `Fuse:Fuse_1812_4532Metric`. Hold derates to ≈1.75–2 A at 60 °C vs ≈1.9 A boost input — the RISET=120 k (0.75 A) fallback stays available if hot-enclosure nuisance trips appear.
11. **BATTERY-CARRIER VERIFICATIONS (NEW 2026-07-19 — resolve before ordering)**:
   - **11a. DW01A-G (U13) — ✅ RESOLVED 2026-07-19**: SOT-23-6 pinout confirmed (OD=1, CS=2, OC=3, TD=4 NC, VCC=5, GND=6); over-discharge 2.40 V (release 3.0 V), over-charge 4.30 V (release 4.1 V); 100 Ω/100 nF/1 kΩ = documented typical application. LCSC candidates: **C351410** (PUOLOP) among many second sources — pick at order time (ubiquitous part).
   - **11b. FS8205A (Q6) — ✅ RESOLVED WITH CORRECTION 2026-07-19**: real TSSOP-8 pinout is **D=1&8 (internally common), S1=2&3, G1=4, G2=5, S2=6&7** — the first-drawn map was wrong; symbol redrawn and rewired (netlist re-verified). 20 V VDSS, ±12 V VGS, ~6 A; series-pair RDS(on) ≈60 mΩ is negligible at wake-cycle currents. LCSC candidates: **C14212** (Fortune, via JLCPCB) / C908265 (FUXINSEMI clone).
   - **11c. BT1 carrier — MPN candidates picked 2026-07-19**: (1) **MYOUNG BH-18650-B1BA002, LCSC C2988620** — full plastic holder, SMD tabs, in stock, ~$0.6 class; (2) **Keystone 1042/1042P** — the western-brand SMD equivalent (Digi-Key); (3) **MYOUNG MY-18650-02, LCSC C2979182** — a pair of THT spring-steel clips (~$0.17 each), mechanically the strongest option for a field device with cell swaps. **✅ FOOTPRINT RESOLVED 2026-07-21**: the KiCad-standard `Battery:BatteryHolder_Keystone_1042_1x18650` is an exact dimensional match (SMD, pad 1 = + at −39.33 mm, pad 2 = − at +39.33 mm, ~78 mm span + 2 alignment posts) — **no custom draw needed**. Populate with the Keystone 1042 (off-LCSC: Digi-Key/Mouser or PCBWay global-source) or, for LCSC single-sourcing, the MYOUNG **BH-18650-B1BA002 (C2988620)** — same ~78 mm SMD form; verify its terminals land on the Keystone pads (a quick check against the LCSC drawing on a desktop) before committing. The MY-18650-02 THT clip pair (C2979182) remains an option but needs its own footprint. Bench: protection trip + recovery test, and a reversed-cell insertion test (D5 must block).
   - **10f. SOLAR COLD-CHARGE CUTOFF — ✅ RESOLVED 2026-07-19 (user decision: add it)**: discrete LM393 comparator cutoff added (U14 + revived RT_SOLAR + R_NT1/2/3, R_PU, R_HYS, C_NTC, Q7) — see the "Solar cold-charge cutoff" section. Powered from VSOLAR → **zero battery draw at night**; trips ≈ +2 °C falling / releases ≈ +4 °C; clamps the CN3791 MPPT pin via Q7 (charging backs off to zero exactly as with a collapsed panel). Bench items: verify trip/release temperatures and that the MPPT clamp fully stops charge current; LM393 pinout is the industry-universal dual-comparator map — confirm on the chosen vendor's datasheet at order time.
10. **1S-CONVERSION VERIFICATIONS (2026-07-19 — resolve before ordering)**:
   - **10a. TP4056 (U12) — ✅ RESOLVED 2026-07-19** (web datasheet sources): pinout confirmed (TEMP=1, PROG=2, GND=3, VCC=4, BAT=5, /STDBY=6, /CHRG=7, CE=8, EPAD). TEMP window confirmed: charging suspends when V_TEMP < 45 % or > 80 % of VIN for > 0.15 s (TEMP to GND disables detection — do NOT do that). PROG formula varies by datasheet revision: classic I_CH = 1200 V/R_PROG (1.2 k → 1.0 A); REV 2.3 gives R_PROG(kΩ) = 1100/I(mA) (1.2 k → ≈0.9 A) — **R_PROG 1.2 k lands at 0.9–1.0 A either way, fine**. LCSC **C16581** (TP4056-42-ESOP8). ✅ **TEMP-window math computed 2026-07-19**: R_NTC 5.6 k / RT1 10 k B3950 → **+8…+44 °C** (cold trip RT1=22.4 k @ 80 %·VIN, hot trip RT1=4.58 k @ 45 %·VIN). Conservative-safe for Li-ion; keep 5.6 k. Still open (bench): the ≈1.3 W thermal check under the EPAD pour (drop R_PROG to 2.4 k if hot).
   - **10b. CN3791 (U7) — ✅ RESOLVED WITH MAJOR CORRECTIONS 2026-07-19** (datasheet extractions + Soldered Electronics open-hardware KiCad design): the first-drawn symbol was wrong in numbering AND function set. Real part: **controller with external P-FET** (DRV=10 drives M_SOLAR; 8 V gate clamp), pin map VG=1/GND=2//CHRG=3//DONE=4/COM=5/MPPT=6/BAT=7/CSP=8/VCC=9/DRV=10, **no TEMP pin** (→ #10f), COM needs 220 nF+120 Ω to GND, VG needs 100 nF to VCC, I_CH = **120 mV/R_CS ✅** (0.1 Ω → 1.2 A), VCC 4.5–28 V (abs 30 V), 4.2 V ±1 % CV, 300 kHz, BAT+CSP sleep ≈ **9 µA @ 4.2 V** (nightly-budget entry). Schematic corrected: M_SOLAR (SI2319CDS) + D16 + R_DRV 300 k restored, C_COM/R_COM added, RT_SOLAR deleted. ✅ **L_SOLAR resized 2026-07-19**: computed peak inductor current ≈1.24 A (Ich 1.2 A + ½·85 mA ripple at 47 µH); the old SRN6045TA-470M (Isat ≈1.3 A) gave only ~5 % margin. Changed to **SRN6045TA-220M (22 µH, Isat 3.3 A, Irms 2.3 A, DCR 96 mΩ, same 6045 footprint)** — 1.7× margin over the 1.9 A target; ripple rises to 182 mApp, still trivial. CN3791 LCSC confirmed 2026-07-21: **C154992** (Consonance, in stock).
   - **10c. ADS1115 battery range (firmware)**: AIN2 now sees up to 2.1 V (÷2 divider) — the AIN2 read **must move to the ±4.096 V PGA** (the ±2.048 V range clips at 4.1 V pack voltage, exactly the full-charge region). Firmware handoff together with `CONFIG_WELLD_BATT_DIVIDER_RATIO` 430 → 200, `BATT_FULL_MV` 8400 → 4200, `BATT_EMPTY_MV` 6000 → 3000.
   - **10d. HT7333-A (U1) — ✅ RESOLVED 2026-07-19**: SOT-23 pinout confirmed GND=1, VOUT=2, VIN=3 (multiple sources; identical to XC6206). 3.5–4 µA Iq, VIN 2–12 V, dropout ≈60 mV @ 100 mA. LCSC **C21583** confirmed (Holtek HT7333-A). Still open: bench-verify worst-case 3.3 V rail current < 250 mA during 802.15.4 TX + sensor reads (Wi-Fi must remain disabled — it already is).
   - **10e. Sleep budget re-check (bench)**: 1S sleep floor should now be U1 4 µA Iq + TP4056 BAT leak (<2 µA typ) + CN3791 BAT dark current + TVS leakage at 4.2 V — target < 15 µA total; measure at first article.
9. **✅ APPLIED 2026-07-14 (same-day follow-up pass)** — all eight edits are now in the sheets: U1 renumbered (FB=1/EN=2/VIN=3/GND=4) + renamed welld:AP63203WU + TSOT-23-6 + **C_BST_AP 100 nF placed on new net AP_BST (U1 BST ↔ SW)**; USBLC6 renumbered; PRTR5V0U2X redrawn 4-pin SOT-143B (VCC2/GND2 stubs removed); D9/D10 = SMAJ5.0A; U12 footprint = QFN-24-1EP_4x4mm_P0.5mm_EP2.6x2.6mm; FB1 = 0603; C28/C29/C_SYS1/C_SYS2 = 25 V. netlist_check: 393 pins / 78 nets / 0 mismatches. Original findings (details in `component_verification_2026-07-14.md`): (a) U1 symbol renumber + **C_BST_AP 100 nF BST–SW cap** (blocker #1 — rail cannot start without it); (b) USBLC6/PRTR5V0U2X symbol renumbering; (c) D9/D10 → SMAJ5.0A; (d) IP2326 footprint = QFN-24 4×4 P0.5 EP2.5; (e) FB1 footprint 0402 → **0603** (BLM18KG601SN1D is a 1608-metric part); (f) C28/C29/C_SYS1/C_SYS2 → 25 V rating.

---

## Components Still Needing Resolution in KiCad

| Symbol | Issue | Action in KiCad |
|---|---|---|
| R_FBH / R_FBL | ~~AP63203 DNP divider~~ | ✅ **Deleted 2026-07-19** with the AP63203WU (1S conversion — HT7333-A has no FB pin) |
| Q3, Q4, R29, D15 | ~~VLOOP disconnect + rectifier~~ | ✅ **Placed 2026-07-13** (power sheet: Q3=AO3407, Q4=BSS123 → AO3400A per 2026-07-15 alternatives review P-1 (applied 2026-07-19), R29=100k, D15=SS34); ✅ wired per the VLOOP section |
| R25, R27 | ~~Pull-up/pull-down~~ | ✅ **Placed 2026-07-13** (power sheet: R25 4.7k, R27 100k) |
| Q5, R16 | ~~Battery divider high-side switch~~ | ✅ **Placed 2026-07-13** (power sheet: Q5=AO3407, R16=100k); ✅ Q2 (sensors sheet) wired as its gate driver per ADC_CH2 section — nets `Q5_GATE`/`VBAT_SW` cross the power↔sensors boundary as hierarchical nets |
| R15, C36 | ~~ESP32 EN RC~~ | ✅ **Placed 2026-07-13** (mcu sheet: 10k 0402, 1µF 0402) |
| TP13 | ~~Factory-reset pad~~ | ✅ **Placed 2026-07-13** (mcu sheet, TestPoint_Pad, net FACTORY_RESET — GPIO23 since 2026-07-22) |
| C8 | ~~Value change 100nF → 1nF~~ | ✅ **Edited 2026-07-13** (sensors sheet) |
| D8, D14 | ~~SMAJ28CA → SMAJ24CA~~ | ✅ **Edited 2026-07-13** (power sheet) |
| C17 | ~~25 V → 35 V rating (footprint 0805 → 1206)~~ | ✅ **Edited 2026-07-13** (power sheet: "10uF 35V", C_1206) |
| SJ2/SJ3 (and new SJ4/SJ5) | All five SJ symbols use the *Open* variant; SJ2/SJ3/SJ4/SJ5 should default **bridged** | Swap symbol/footprint variant — **still open** |
| U12 | ~~TP5100 → IP2326 → TP4056~~ | ✅ **Replaced again 2026-07-19** (1S conversion): `welld:TP4056` SOP-8+EPAD drawn and wired (VUSB / /CHRG_USB / PROG-TEMP tables); standard footprint `Package_SO:SOIC-8-1EP_3.9x4.9mm_P1.27mm_EP2.29x2.29mm` — no custom footprint needed. Pinout verify = 1S blocker #10a |
| U1 BST + symbols | ~~2026-07-14 component-sweep edits~~ | ✅ **ALL APPLIED 2026-07-14 follow-up**; AP63203-specific items (renumber, C_BST_AP) made moot 2026-07-19 when the part was deleted in the 1S conversion (U1 = HT7333-A) |
| L3, RT1 | ~~IP2326 support parts~~ | L3 ✅ **deleted 2026-07-19** with the IP2326; RT1 kept — re-wired to TP4056 TEMP (with new R_NTC 5.6 k divider top) |
| R36, R37 | ~~Deleted with TP5100 CE network~~ | ✅ **Removed 2026-07-13** from power sheet; GPIO4 net is spare (firmware already annotated) |
| F2 | ~~1.1 A → 2 A hold PTC~~ | ✅ **Edited 2026-07-13** (value "PTC 2A hold"); MPN resolved (blocker #8: Bourns MF-MSMF250/16X-2, **1812**) — footprint field updated 1206 → `Fuse:Fuse_1812_4532Metric` 2026-07-19 |
| U7 externals | ~~CN3722 buck stage~~ | ✅ Placed 2026-07-13; **mostly deleted 2026-07-19** (1S conversion): M_SOLAR/D16/C_COM1-3/R_COM2 removed — the CN3791 keeps only D_SOLAR, L_SOLAR, C_VG, RT_SOLAR, R19 (R_CS now 0.1 Ω); ✅ wired per the CN3791 pin map |
| U6 | Custom symbol | Replace with Espressif official symbol + footprint — **still open** |
| C25 | ~~Duplicate of C_BST~~ | ✅ Deleted 2026-07-05 |
| C16 | ~~Unidentified~~ | ✅ Assigned: U1 VIN bulk 10 µF 16 V 0805 |

> **2026-07-13 (wiring pass) note:** all placed symbols are now **fully wired** (stub + label connectivity, design change #17). `netlist_check.py` re-extracts pin→net connectivity from the sheets geometrically and diffs it against the table in `kicad_wire_script.py` (derived from this document): 395 pins, 77 nets, 21 no-connects, **zero mismatches** (`netlist_check_output.txt`). KiCad-native ERC could not be run in the work environment (only KiCad 7 available vs the KiCad 10 file format) — run ERC on first open in KiCad 10; expect only style-grade items (off-1.27-grid stubs on the handful of off-grid symbol placements, "input pin not driven" on passive-driven analog inputs).

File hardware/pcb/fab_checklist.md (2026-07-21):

# Path to fabrication — ordered checklist (updated 2026-07-19 for the 1S conversion + battery carrier)

Consolidates the remaining work from `senior_review_2026-07-06.md`, `component_verification_2026-07-14.md`, and the blocker list in `schematic_connections.md`. The schematic is fully wired (stub+label) and machine-verified (**391 pins / 75 nets / 0 mismatches** after the 1S conversion + battery carrier + CN3791 correction + solar cold-charge cutoff, `netlist_check_output.txt`), but the 1S conversion introduced three new parts whose datasheets were not fetchable at conversion time — **blockers #10 (a–e) and #11 (a–c) in `schematic_connections.md` are now the top of this list**. Everything below is what still stands between this repo and ordering boards.

## 0. Datasheet checks — ✅ DONE 2026-07-19 (web-verification pass; see blockers #10–#11 for details)

- **CN3791** (#10b): ✅ verified **with major corrections applied** — it is a *controller* (external P-FET restored: M_SOLAR/D16/R_DRV; COM network added; **no TEMP pin → RT_SOLAR deleted, see #10f**); pin map + 120 mV/R_CS formula + VG cap confirmed; symbol redrawn, netlist re-verified.
- **TP4056** (#10a): ✅ pinout + TEMP window (45–80 % VIN) confirmed; R_PROG 1.2 k → 0.9–1.0 A depending on DS revision; LCSC **C16581** (ESOP-8).
- **HT7333-A** (#10d): ✅ pinout confirmed (GND=1/VOUT=2/VIN=3); LCSC **C21583**.
- **DW01A** (#11a): ✅ pinout + thresholds + app values confirmed (LCSC candidate C351410).
- **FS8205A** (#11b): ✅ verified **with correction** — real map D=1&8/S1=2&3/G1=4/G2=5/S2=6&7; symbol redrawn (LCSC candidates C14212/C908265).
- **BT1 carrier** (#11c): ✅ **footprint resolved 2026-07-21** — use the KiCad-standard `Battery:BatteryHolder_Keystone_1042_1x18650` (exact match, no draw). Populate with the Keystone 1042 (off-LCSC) or MYOUNG BH-18650-B1BA002 (C2988620, LCSC) if its terminals match the Keystone pads. Placement: top-side along a long edge, board ≈100 × 60 mm.
- **#10f — ✅ RESOLVED (user decision)**: discrete **LM393 cold-charge cutoff added** — solar-powered (zero night draw), ratiometric NTC threshold, clamps the CN3791 MPPT pin below ≈+2 °C (release ≈+4 °C). Bench-verify trip/release and zero charge current while clamped.
- ✅ **Bench-math done 2026-07-19**: TP4056 TEMP window computed **+8…+44 °C** (R_NTC 5.6 k / RT1 10 k B3950 — conservative-safe, kept). L_SOLAR resized to **SRN6045TA-220M** (22 µH, Isat 3.3 A) — peak ≈1.24 A gives 1.7× margin, same footprint.

## 1. First interactive KiCad 10 session (~1 hour, needs a desktop)

1. Open `welld.kicad_pro`, let KiCad migrate/resave all sheets (normalises the generated formatting).
2. Run **ERC**. Expected waivable items (from the wiring-pass notes — anything *else* is a real finding):
   - off-1.27-grid stub endpoints on the handful of off-grid symbol placements;
   - "input pin not driven" on passive-driven analog inputs (ADS1115 AINx, FB pins);
   - style-grade label/wire overlaps from generated placement.
3. Re-run `python3 hardware/pcb/netlist_check.py` after the resave — it must still report zero mismatches (guards against the migration moving anything).
4. Replace the custom `welld:ESP32_C6_MINI_1U` symbol with the official Espressif library part and re-run ERC + `netlist_check.py`. **The custom pin numbering was verified WRONG (2026-07-21)** — the official signal-pin map is recorded in the symbol-verification table in `schematic_connections.md`; map the existing nets to it. The one behavioural consequence is already applied: **GPIO10/GPIO11 are not bonded out on the MINI-1**, so I²C was moved to **GPIO18/GPIO19** across firmware + schematic + docs.
5. Swap SJ2–SJ5 to the *Bridged* solder-jumper variants (currently Open).

## 2. Cell choice (no vendor question any more)

- The pack (and its unanswerable PCM question, old blocker #7a) is gone — protection is the on-board DW01A/FS8205A. What remains is a **cell choice**: worst-case co-charge is TP4056 1 A + CN3791 ≈1.2 A ≈ 2.2 A into a single ≈3.4 Ah cell (**≈0.65C**). Use a quality high-rate 18650, or drop R_PROG to 2.4 kΩ (0.5 A USB) if the cell runs warm under co-charge.

## 3. Layout (in KiCad, using the written constraints)

- `placement_constraints.md` is current (rewritten 2026-07-19): Group G = TP4056 **thermal** cluster (no switching loop — EPAD pour is the constraint, ≈1.3 W at 1 A), Group L = CN3791 integrated buck (C17→VIN→SW→D_SOLAR hot loop; **CSP/BAT Kelvin pair routed together to R19**), Group B = HT7333-A LDO (trivially quiet now).
- `kicad_place_script.py` (PCB-editor scripting console) gives starting placements.
- Board outline: **unconstrained** (user, 2026-07-19) — draw it around the finished placement; working target ≈100 × 60 mm with the BT1 carrier top-side along a long edge (Group H). All 1S replacement parts are iron-friendly except the two EPADs (TP4056 SOP-8-EP, and the ESP32 module) — hot air preferred; the carrier is an SMD holder (Keystone 1042 footprint: SMD terminals + 2 alignment posts).

## 4. Order (all LCSC numbers verified 2026-07-14)

- BOM: `bom_footprints.md` — updated 2026-07-19 for the 1S conversion. Verified numbers carried over: PRTR5V0U2X **C12333**, SMAJ5.0A **C98802** (now also D13), PTC C210838, AO3400A C20917, HRO USB-C C165948.
- **LCSC numbers — ✅ locked 2026-07-21**: LM393 **C7955** (onsemi, JLCPCB Basic), CN3791 **C154992** (Consonance), TP4056 **C16581** (ESOP-8), HT7333-A **C21583**, DW01A **C351410** (PUOLOP, JLCPCB), FS8205A **C14212** (Fortune, JLCPCB), SMAJ10CA D8/D14 **C320526** (LGE), SMAJ13A D11 **C110519** (Diodes Inc), BT1 **C2979182** (MY-18650-02 clip ×2). ✅ **Footprints resolved 2026-07-21**: BT1 → `Battery:BatteryHolder_Keystone_1042_1x18650` (KiCad standard, no draw); HRO USB-C → `Connector_USB:USB_C_Receptacle_HRO_TYPE-C-31-M-12` (confirmed present in KiCad standard lib). **Only the GDT land pattern remains** — and it is gated: GDT1/GDT2 are DNF with no chosen MPN (site-dependent populate), so the pattern is drawn only if/when a specific 2-electrode GDT is selected.

## 5. First-article bench-verify list (before enclosure sealing)

| # | Check | Why |
|---|---|-----|
| 1 | MT3608B pin continuity (SW↔L1 node, IN↔VBAT) before first power-on | pin map confirmed from library sources, never from the raw Aerosemi PDF |
| 2 | +3V3 rail regulates 3.3 V; worst-case rail current < 250 mA during 802.15.4 TX + sensor reads | U1 is now a 250 mA HT7333-A LDO (1S blocker #10d) |
| 3 | TP4056 1 A charge without thermal fold-back in the enclosure (or accept fold-back / drop R_PROG to 2.4 k) | ≈1.3 W linear dissipation at mid-charge; pour sizing is a guess until measured |
| 4 | Sleep floor < 15 µA total: HT7333 Iq + TP4056 BAT leak + CN3791 BAT dark current + TVS at 4.2 V | nightly battery budget (1S blocker #10e) |
| 5 | Charger CV agreement: CN3791 vs TP4056, both nominally 4.2 V, under co-charge | verify no oscillation / one-charger-hogging at the overlap |
| 6 | NTC cutoffs: TP4056 stops outside RT1's **computed +8…+44 °C** window; **LM393 cutoff clamps solar charge below ≈+2 °C (release ≈+4 °C), zero charge current while clamped** | outdoor Li-ion; thresholds computed — confirm on bench |
| 7 | MT3608B EN-low shutdown current < 1 µA; boost still makes 12 V from VBAT = 3.0 V (ratio 4×, higher input current) | sleep-budget + low-battery loop-read assumptions |
| 8 | CN3791 charge current ≈ 1.2 A at R_CS 0.1 Ω (sense-formula assumption); L_SOLAR stays out of saturation | 1S blocker #10b — formula and Isat margin both assumed |
| 9 | Loop reading sanity vs known pressure; SMAJ5.0A leakage invisible on the shunt | D9/D10 substitution validation |
| 10 | ADS1115 AIN2 reads correctly up to 4.2 V cell (±4.096 V PGA, ratio 200) | shipped in fw 1.1.0 — clipping at full charge was the failure mode |
| 11 | Protection trip + recovery: cell isolated below ≈2.4 V, recovers on charger; over-current trip; reversed-cell insertion blocked (D5) | new DW01A/FS8205A path + carrier (#11a–c); values assumed from the module ecosystem |

## 6. Enclosure (after layout freezes connector positions)

- `hardware/case/` does not exist yet. Case work is deliberately last — the board outline is now free (set at layout, working target ≈100 × 60 mm), and the case consumes the final outline plus connector/TP positions (TP13 factory-reset pad must stay reachable with the lid off; ~19–21 mm clearance over the top-side 18650 carrier).

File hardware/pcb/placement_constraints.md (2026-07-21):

# WellD PCB — Placement Constraints

These are **rules and groupings only** — no positions dictated. Place components wherever you want in KiCad, but respect these constraints.

---

## Board Edge Requirements

These components must land on a specific board edge:

| Component | Edge | Why |
|---|---|-----|
| J13 (USB-C) | Any short edge (55mm side) | Connector body extends off-board; case cutout is on this wall |
| J3 (SMA edge-mount) | Any short or long edge | Antenna port must clear the board outline; RF port protrudes ~3mm past Edge.Cuts |
| J4, J5, J6, J7, J12 (screw terminals) | One long edge (80mm side) | Field wiring exits through cable glands on this face of the enclosure |
| BT1 (18650 carrier) | Body parallel to a long edge | ≈78×21 mm SMD holder (`Battery:BatteryHolder_Keystone_1042_1x18650`, terminal span 78.66 mm) — dominates the board; see Group H. No case battery bay needed (cell lives on the PCB) |
| J10 (programming header) | Any edge or interior — but keep accessible | Pogo-pin fixture needs vertical clearance; keep clear of large caps |

> **J3 and J13 must be on different edges** — they cannot share the same short edge (connector bodies will clash).

---

## Must-Be-Near Groups (hard rules from datasheets)

### Group A — MT3608B boost hot loop
`Q3 → L1 → U8 SW → D15 → C20/C22` — the SW→D15→C20/C22 loop must be tight.
- L1 within **3mm** of U8 SW pin
- D15 (SS34 rectifier) within **3mm** of U8 SW pin; C20/C22 within **3mm** of D15 cathode
- C_BST (100nF) within **1mm** of U8 BST pin to SW node (fit even if pin 6 proves to be NC)
- C19 within **2mm** of U8 IN pin
- Q3/Q4/R29 (VLOOP disconnect) upstream of L1 — not timing-critical, keep within ~10mm
- R27 (VBOOST_EN pull-down) anywhere on the GPIO5 net
- **No copper pour under L1 on either layer** — switching node EMI
- Keep the SW→L1→VOUT hot trace under **10mm**, min **0.5mm wide**
- Surround this island with a GND via-stitch perimeter

### Group B — HT7333-A LDO (1S conversion 2026-07-19 — was the AP63203 buck; L2/C_BUCK-at-L2/R_FBH/R_FBL rules obsolete)
`U1, C9/C10/C16 (VIN), C_BUCK/C11/C12 (VOUT)`
- C9/C10/C16 on U1 VIN (3) side, within **2mm** (C16 = 10µF bulk)
- C_BUCK (10µF 0805) + C11/C12 on U1 VOUT (2), within **3mm** — LDO stability wants the output cap close
- No switching node, no inductor, no pour restrictions — this group is now trivially quiet; placement is only about lead length

### Group C — ADS1115 analog island
`U9, FB1, C23, C24, R9, R10, R_DRDY`
- FB1 in series with +3V3 feed to U9 VDD
- C23 (100nF) and C24 (1µF) on the **U9 side** of FB1, within **1mm** of U9 VDD pin
- Keep U9 **≥20mm from U8** (MT3608B switching noise)
- Keep U9 away from L1 and L2 (inductor EMI)
- R_DRDY (4.7kΩ pull-up for ADS_DRDY) can be anywhere near U9 or near GPIO12 trace

### Group D — CN3791 solar charger thermal (corrected 2026-07-19 — controller, external FET carries the heat)
`U7, C17, C18, R19, R20, R21`
- A modest GND pour under U7 suffices (the controller itself dissipates little); the real heat is in M_SOLAR / D16 / D_SOLAR (Group L) — spread copper there
- Mirror the pour on B.Cu and stitch with the same vias
- U7 must be **≥15mm from U6** (ESP32 module)
- U7 and U8 must be **≥8mm apart**

### Group E — 4-20mA shunt and protection chain (CH1)
`J4 → D9 → R2 → C34 → R3 → D1 → C3/C4 → U9 AIN0`
- D9 within **3mm** of J4 SIG terminal
- C34 within **1mm** of R2 pads (across the shunt)
- TP5 (test point) at the R2/R3 shunt-top node
- Same grouping for CH2: `J5 → D10 → R4 → C35 → R5 → D1 CH2 → C5/C6 → U9 AIN1`

### Group F — ESP32-C6 module decoupling
`U6, C13, C30–C33, C15, R15, C36`
- All five 100nF caps (C13, C30–C33) within **2mm** of the module VCC3V3 pads
- C15 (10µF bulk) within **5mm** of module
- R15/C36 (EN reset RC) within **5mm** of the module EN pad, C36 ground via short
- Keep a **15mm no-copper keep-out** zone around the module's on-chip antenna area (the far end from the U.FL pad) on both layers

### Group G — TP4056 USB linear-charger cluster (rewritten 2026-07-19 for the 1S conversion — no switching loop anymore)
`J13, U11, F2, U12, C27, C28, C29, R_PROG, R_NTC, R38, R50, R51, RT1`

**No hot loop** — the TP4056 is linear. The dominant constraint is **thermal**, not di/dt:
- **EPAD thermal**: solder the exposed pad to a GND pour; **10×10mm solid GND copper on F.Cu** under U12, ≥6 thermal vias (0.5–0.6mm drill) through to a matching B.Cu pour — **1 A charge from 5 V dissipates ≈1.3 W at mid-charge** (worse than the old boost's ~1 W; the TP4056 thermally regulates at ≈120 °C die, so an undersized pour silently slows charging rather than failing)
- U12 must be **≥10mm from U6** (ESP32) and away from RT1's pack-coupling path — a hot charger next to the pack NTC would false-trip the charge-temperature window
- C28 (10µF) within **2mm** of U12 VCC (4); C27 (4.7µF) just behind it on VUSB
- C29 (10µF) within **3mm** of BAT (5) — output (VBAT) side
- R_PROG within **3mm** of PROG (2), GND end to quiet ground (it is the current-set sense — keep it off the EPAD pour's high-ripple return)
- R_NTC + RT1: divider junction at TEMP (1); route the NTC pair away from the hot U12 area; thermistor body thermally coupled to the **pack**, so expect a wired stub or pack-adjacent placement
- R50/R51 within **3mm** of J13 CC1/CC2 pins; U11 and F2 between J13 VBUS and U12 VCC — total VUSB trace under **15mm**

### Group L — CN3791 external buck stage (re-corrected 2026-07-19 — the CN3791 is a controller; FET stage restored)
`U7, M_SOLAR, D16, D_SOLAR, L_SOLAR, R19 (R_CS), R_DRV, C17, C21, C_VG, C_COM, R_COM`

**Hot loop (buck, external P-FET):** `C17/C21 (VIN caps) → M_SOLAR S→D → SOLAR_SW → D16 → SOLAR_FW ← D_SOLAR (catch, GND→FW)`; L_SOLAR carries SOLAR_FW to CN_CS.
- C17 (10µF 35V) + C21 (100nF) within **3mm** of M_SOLAR source / U7 VCC (9); the C17-ground → D_SOLAR-anode-ground path must be short — this is the fast di/dt loop
- M_SOLAR, D16, D_SOLAR within **5mm** of each other; SOLAR_SW / SOLAR_FW copper small
- D_SOLAR anode ground and C17 ground tied at one point into the pour (loop closure)
- L_SOLAR after the FW node; no pour under it
- **Kelvin current sense:** R19 (R_CS 0.1Ω 1206) in the L_SOLAR→VBAT path; route **CSP (8) and BAT (7) as a paired sense track directly to the two R19 pads** — no shared copper with the power path, ≥0.2mm gap from the switching nodes
- C_VG (100nF) within **2mm** of VG (1), returned to **VCC** (✅ datasheet-verified)
- Gate drive DRV (10) → M_SOLAR gate: short, ≤10mm; R_DRV (300k) gate–source at the FET
- C_COM (220nF) + R_COM (120Ω) within **5mm** of COM (5), ground end to quiet analog ground
- RT_SOLAR (revived for the LM393 cutoff): thermistor body thermally coupled to the **cell/carrier**, wired stub or cell-adjacent placement — same rule as RT1; keep the NTC pair away from switching nodes
- The heat now lives in M_SOLAR/D16/D_SOLAR, not U7 — the Group D pour under U7 shrinks in importance; give M_SOLAR a modest copper spread instead

### Group N — Solar cold-charge cutoff (NEW 2026-07-19)
`U14 (LM393), RT_SOLAR, R_NT1, R_NT2, R_NT3, R_PU, R_HYS, C_NTC, Q7`
- Small-signal analog: place near U7's MPPT corner (Q7 drain lands on the MPPT_REF node — keep that trace short)
- C_NTC within **2mm** of U14 VCC (8)
- Divider nodes NTC_T / NTC_REF away from SOLAR_SW/SOLAR_FW switching copper (≥2 mm)
- RT_SOLAR body couples to the cell, not to this cluster — expect a routed pair out to the carrier area

### Group H — Battery carrier + input protection (rewritten 2026-07-19)
`BT1, U13, Q6, R_DW1, C_DW, R_CS_DW, D13, D5, R31`
- **BT1 placement (resolved 2026-07-19 — board size is unconstrained per user)**: put the carrier on the **top side, its own band along one long edge**, and grow the outline to fit — working target ≈**100 × 60 mm** (final dims set at layout; the case consumes them afterwards). Single-sided assembly, no back-side reflow. Keep the carrier band away from the antenna edge and off the MT3608B/CN3791 switching islands.
- Protection cluster (U13/Q6/R_DW1/C_DW/R_CS_DW) tight at BT1's **negative** terminal: the BATT_N → Q6 S1 → drains → S2 → GND path carries every load and charge ampere — short, wide copper (≥1 mm), no via detours if possible
- R_CS_DW's GND end on the **system** side (P−), R_DW1/C_DW referenced to BATT_N — do not mix the two grounds around U13; the DW01A senses the FET-pair drop between them
- D13 (SMAJ5.0A) within **5mm** of BT1 cell+ tab
- D5 and R31 between D13 and VBAT rail — R31 within **2mm** of D5 gate
- RT1 thermally coupled to the carrier/cell body (it is the **only** charge-temperature cutoff — the solar path has none, blocker #10f)

### Group K — Battery divider (gated)
`Q5, R16, Q2, R26, R7, R8, C8`
- Whole group near U9's analog island; the ADC_CH2 trace (R7/R8 mid → U9 AIN2) short and away from L1/L2
- C8 (1nF) directly across R8

### Group I — DS18B20 interface
`J6, D12, R6, R28, R32`
- D12 within **3mm** of J6 DATA terminal (pin 2)
- R6 (pull-up) can be anywhere between +3V3 and the 1WIRE net
- R28 in the VCC line between +3V3 and J6 pin 1

### Group J — Solar input protection
`J12, D14, D6, D8, C17, C21`
- D14 (SMAJ10CA) within **3mm** of J12 SOLAR+ pin (first TVS at the terminal)
- D6 between D14 and U7 VIN (Schottky backfeed block)
- D8 (SMAJ10CA) within **5mm** of C17 (second-stage TVS at CN3791 VIN)
- C21 within **3mm** of D8

---

## Must-Be-Apart Rules

| Components | Minimum gap | Reason |
|---|---|---|
| U7 (CN3791) and U6 (ESP32) | 15mm | Switching-stage noise (M_SOLAR/D16) and RF isolation |
| U8 (MT3608B) and U9 (ADS1115) | 20mm | 1.2MHz switching noise corrupts ADC readings |
| U8 (MT3608B) and U7 (CN3791) | 8mm | Thermal — both dissipate power simultaneously |
| L1/L2 (inductors) and U9 (ADS1115) | 15mm | Inductor EMI fields |
| J3 (SMA) and U6 (module) | Route W1 pigtail — keep coax away from other signals |

---

## RF Layout Rules (J3, W1, U6)

The RF path is: **U6 U.FL pad → W1 pigtail cable → J3 SMA edge-mount**

W1 is a hand-attached cable — it is NOT pick-and-place. PCBWay installs it manually after reflow.

- J3 must be near the edge so the pigtail (~50mm) can reach U6's U.FL port without strain
- No PCB trace is needed for RF — W1 handles it
- Keep a **15mm no-copper keep-out** around the module's chip antenna area (opposite end from U.FL)
- Keep high-current power traces (VLOOP, VBAT) away from the U.FL pad area

---

## Thermal Copper Pours Required

| Component | Pour size | Layer | Via stitching |
|---|---|---|---|
| M_SOLAR / D16 / D_SOLAR (solar buck) | copper spread at each part | F.Cu, GND/net pours as routing allows | the CN3791 controller itself needs no special pour |
| U12 TP4056 | 10×10mm | F.Cu + B.Cu, GND net (EPAD soldered) | ≥6 vias, 0.5–0.6mm drill (≈1.3W at 1A linear charge — thermal regulation folds back if undersized) |

---

## Test Point Placement Notes

- TP1/TP3/TP4: near U1 buck (TP1=VBAT at U1 VIN side, TP3=+3V3 at output, TP4=GND)
- TP2: near C20/C22 on VLOOP rail
- TP5/TP6: within 3mm of R2/R4 (on the R3/R5 side of the shunt)
- TP7: near J6 DATA, on the GPIO7 side of D12
- TP8/TP9: near J8 I²C header
- TP10: near J12 solar input terminal
- TP11: near J1 BAT+ terminal (before D5)
- TP12: near U6 GPIO12 area
- TP13 (FACTORY_RESET): board edge or otherwise reachable with the lid off — field-recovery pad, pair visually with TP4 (GND)
- TP14: near U7 /CHRG pin
- TP15: near U12 /CHRG pin

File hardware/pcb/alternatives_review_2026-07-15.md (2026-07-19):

# WellD PCB — "Better Options" Alternatives Review — 2026-07-15

**Scope:** every active position in `bom_footprints.md`, reviewed through a different
lens than `component_verification_2026-07-14.md` (which established that every part is
*correct*). This pass asks, position by position: **is there a better and more commonly
used alternative?** Judged on: community track record / design-in volume (appearance in
shipped open-hardware and commercial designs), LCSC/JLCPCB availability and
multi-sourcing, simplicity (fewer externals, fewer failure modes), documentation
quality, and price — against the WellD profile: outdoor solar+USB 2S Li-ion,
deep-sleep-dominated (nightly µA budget dominates over efficiency at load), hobby-scale
assembly (hot-air OK, no stencil oven guaranteed), 80×55 mm board.

**Update 2026-07-19: all four proposals below were USER-APPROVED and applied** to the
schematic (`power.kicad_sch` / `sensors.kicad_sch`), the intent net table
(`kicad_wire_script.py`), `schematic_connections.md` and `bom_footprints.md`;
`netlist_check.py` passes with zero mismatches.

---

## Proposed changes (✅ applied 2026-07-19)

| # | Position | Proposal | Effort | Status |
|---|---|---|---|---|
| P-1 | Q2/Q4 (BSS123) | **SWAP → AO3400A** (LCSC C20917). Settles review finding O-3: Vgs(th) max 1.45 V vs BSS123's 1.7 V at 3.3 V drive, ~10× cheaper, 1M+ LCSC stock, consolidates on the AOS reel family already used for Q3/Q5/D5. Same SOT-23 footprint — value-field edit only. | Trivial | ✅ applied (value edits, Q2 in sensors / Q4 in power; 2N7002 second-sourced in BOM) |
| P-2 | J13 (USB4135-GF-A) | **SWAP → HRO TYPE-C-31-M-12** (LCSC C165948) as *primary*, GCT demoted to approved alternate. Removes the last global-sourcing connector; ~$0.10 vs ~$1+; the de-facto standard USB-C receptacle of hobby/low-volume boards; 4 THT shell legs give better field retention than the GCT's SMT shell. Requires a footprint swap (not pin-compatible with the USB4135 land pattern). | Footprint change | ✅ applied (footprint → `Connector_USB:USB_C_Receptacle_HRO_TYPE-C-31-M-12`; ⚠️ verify exact name vs installed lib before layout) |
| P-3 | J4/J5 field lines | **OPTIONAL: add 2-electrode GDT footprints (DNF)** between each loop terminal and chassis/GND (90 V class, SMD, e.g. Littelfuse GTCS23-900M-R05 / BOURNS 2038-09-SM class). Completes the industrial 3-stage GDT → series-R → TVS norm for buried outdoor cable runs; DNF by default, populate only for long exposed runs. | 2 footprints | ✅ applied (GDT1: LOOP_TERM_CH1→GND, GDT2: LOOP_TERM_CH2→GND, dnp; `WellD:GDT_BOURNS_2038_SM` footprint still to draw) |
| P-4 | M_SOLAR (AO3407) | **OPTIONAL: SI2319CDS** (−40 V, Vishay LCSC C146287, in stock ~$0.16) for the solar buck high-side only. Restores >60 % Vds margin over the 24 V-clamped panel + switch-node ringing (currently ~23 %). Endorses verification-sweep recommendation R-1. Same SOT-23 pinout. | Value-field edit | ✅ applied (new `welld:SI2319CDS` lib symbol, identical pin map; VBsemi C558254 alternate) |

Everything else: **KEEP** — details below.

---

## Position-by-position verdicts

### 1. U12 — IP2326 (USB 5 V → 2S boost charger, QFN-24) — **KEEP**

| | |
|---|---|
| Current | Injoinic IP2326, QFN-24 4×4 mm, LCSC C2832094, ~$0.30 |
| Verdict | **KEEP** |
| Best common alternative | none better; CS5095E is the runner-up on paper only |

**Design-in commonality — confirmed strong.** The IP2326 is not an obscure pick: it is
*the* module-market standard for USB→2S/3S boost charging. Evidence: a whole ecosystem
of off-the-shelf IP2326 charge boards (Aaenics, Hailue on Amazon, GooGadget,
Masterlexon, Micro Ohm, ICStation clones), a dedicated done.land documentation page and
mirrored datasheet, and healthy LCSC stock at C2832094. That is exactly the "appears in
shipped designs" track record we want, and Injoinic is an LCSC-native brand
(IP5306/IP2312 family ubiquity).

**Alternatives weighed:**
- **CS5095/CS5095E** — SOP-8 (hand-iron-friendly, a real advantage vs our QFN
  constraint), cheaper. But documentation is thin (Chinese-only, sparse distributor
  data — a 2026-07 search surfaces almost nothing beyond a bare "three-section boost
  charging chip" description), weaker/absent input-adaptive current limiting (which is
  what makes the IP2326 safe on uncharacterised 5 V adapters), and far fewer shipped
  boards. The package win does not outweigh the documentation and behaviour gap.
- **SC8815** — Southchip buck-boost with I²C control. More capable, but QFN-32, needs a
  firmware driver, and is capability overkill; commonality is in DIY bench-supply
  projects, not set-and-forget chargers.
- **IP2312-class** — 1S buck chargers; wrong topology for 2S from 5 V.
- **Architecture alternative (5 V→2S via a dedicated module soldered on)** — common in
  one-offs but indefensible for a fabbed PCBA (uncontrolled module BOM churn).

**QFN caveat, honestly:** QFN-24 + EPAD means hot-air only — already accepted in
`fab_checklist.md` §3. No SOP-packaged part matches the IP2326's commonality +
documentation; if a future rev insists on an iron-solderable charger, CS5095E is the
candidate to re-evaluate *after* obtaining and reading its full datasheet.

### 2. U7 — CN3722 (solar MPPT buck controller, TSSOP-16) — **KEEP**

| | |
|---|---|
| Current | Consonance CN3722, TSSOP-16, LCSC C77905, ~$0.50, external P-FET buck stage |
| Verdict | **KEEP** |
| Best common alternative | TI BQ24650 (the commercial standard) — for a future rev only |

- **CN3791 (the hugely common hobby solar part) cannot do 2S.** Community sources are
  unambiguous: CN3791 boards are 1S Li-ion/LiPo (4.2 V CV) and "you cannot use two
  cells in series without a different charger" (jrattechworks). There is no multi-cell
  CN3791 variant — **the CN3722 *is* Consonance's multi-cell sibling**, sold on the same
  hobby-module channels (ICStation "CN3722 MPPT controller 18 V panel" boards). Within
  the CN-family ecosystem we are already on the correct, commonly-used part for 2S.
- **BQ24650** is the commercial standard (Voltaic Systems chargers, the Hackaday "Open
  MPPT" project, CircuitMaker open designs, countless AliExpress/Amazon boards — mostly
  3S/4S builds). It offers true synchronous rectification and ±0.5 % CV. But it is a
  VQFN-16 external-dual-N-FET controller: *more* externals than the CN3722's ~10 (two
  FETs + bootstrap + sense + dividers), harder rework than TSSOP, ~6× the price, and a
  TI-at-LCSC stock gamble. At our 500 mA charge rate the efficiency and regulation
  deltas buy nothing measurable. The right choice *if* a future rev raises solar charge
  current ≥2 A.
- **LT3652** — excellent, monolithic (fewer externals than CN3722), well documented,
  and genuinely common in Western open hardware. Disqualified on price (~$6–8) and
  ADI single-sourcing; ~10× the CN3722 for the same function at our power level.
- The CN3722's external count is already placed and netlist-verified (2026-07-14);
  swapping now would re-open the solar sheet for zero field benefit.

### 3. U1 — AP63203WU (6–30 V → 3.3 V buck) — **KEEP**

| | |
|---|---|
| Current | Diodes AP63203WU-7, TSOT-26, LCSC C780769, 22 µA Iq, VIN 3.8–32 V |
| Verdict | **KEEP — already the sweet spot** |
| Best common alternative | TPS62902 (lower Iq) — bench-data-contingent only |

The field of "truly common 6–30 V-in, 3.3 V-out, low-Iq, hand-solderable bucks" is
smaller than it looks, and the AP63203 sits at its centre:

| Candidate | Iq | Why not |
|---|----|---|
| **AP63203WU (current)** | **22 µA** | SparkFun sells a dedicated AP63203 breakout — real hobby design-in volume; LCSC-native Diodes stock; TSOT-26 iron-solderable; EMI-optimised (FSS) |
| TPS54202 (the JLCPCB-era favourite) | ~35–50 µA Eco-mode class | More common in cheap boards, but *higher* Iq — wrong direction for a nightly-µA budget; no advantage elsewhere |
| MP2315S | ~66 µA AAM | Common, good part, higher Iq, costs more |
| TPS62841 / TLV62569 / SY8089 / ST1PS03 / XC9265 | sub-µA–µA | All VIN ≤ 5.5–6.5 V — disqualified by the 2S 8.4 V input |
| XL1509 / MC34063 class | mA | Iq disqualifies instantly |
| ME3116 (Microne 30 V) | ~100 µA class | Less documented, higher Iq |
| TPS62902 | ~4 µA | The only genuinely *better* electrical option (saves ~18 µA ≈ 0.4 mAh/day) — at the cost of a 0.5 mm-pitch leadless SOT-583 (rework pain) and TI stock risk. Already logged in `component_selection_review.md` §3 as revisit-if-sleep-floor-disappoints. Stands. |

The 2026-07-05 Iq analysis (~40 µA total sleep floor, buck not the dominant term)
remains valid; nothing found in this pass displaces it.

### 4. U8 — MT3608B (12 V VLOOP boost) — **KEEP**

| | |
|---|---|
| Current | MT3608B SOT-23-6, LCSC C84005, + SS34 + Q3/Q4 external load disconnect |
| Verdict | **KEEP** |
| Best common alternative | none — the disconnect architecture is the differentiator |

The MT3608 is arguably the most-cloned boost converter on earth (module volume rivals
the TP4056); commonality is beyond question. Re-checked the two conceivable "better"
shapes:
- **Fixed-output boosts / boosts with true output disconnect** (TPS61230A, TPS610995,
  MAX17222…): all top out at ~5.5 V VIN — none accept 6.0–8.4 V. Unchanged from the
  2026-07-05 search; no new part class found.
- **Charge pump** for 12 V @ 45 mA from 6–8.4 V: an unregulated doubler lands at
  12–16.8 V (needs a post-regulator) and no common charge pump delivers 45 mA at this
  ratio. Worse in every dimension.

At a 5×10⁻⁵ duty cycle, efficiency is irrelevant and leakage is everything — and
leakage is solved *structurally* by the Q3 input-side P-FET disconnect, which no
integrated alternative at this VIN provides. The L1 Isat upgrade note (NR4018/XAL40xx
class if respun) and the MT3608B EN-low quiescent bench check stand.

### 5. U9 — ADS1115 (16-bit I²C ADC) — **KEEP**

| | |
|---|---|
| Current | ADS1115IDGST MSOP-10, LCSC C37593 (TI-genuine), 100 Ω shunt front-ends |
| Verdict | **KEEP** |
| Best common alternative | INA226 (seriously evaluated below) — elegant but not better *here* |

- **Community-standard check:** the ADS1115 + precision shunt is literally the
  productised norm for hobby/industrial-lite 4–20 mA receivers — NCD.io sells 1/2/3/4
  channel "4-20 mA Current Loop Receiver 16-Bit ADS1115" modules as a product line.
  Our topology (100 Ω 0.1 % shunt, RC filter, ADS1115 AIN) *is* the reference
  architecture. Driver written, DRDY interrupt flow tested, host-test coverage exists.
- **INA226 — the serious alternative.** Purpose-built current monitor: 16-bit, I²C,
  ALERT pin, ±81.92 mV shunt range (2.5 µV/LSB), 0–36 V bus measurement. Genuinely
  attractive properties for this design: at ~4 Ω shunt, 20 mA → 80 mV FS with ~0.6 µA
  loop resolution (ample); burden voltage drops from 2 V to 80 mV (more transducer
  compliance headroom); and its 36 V bus input could read VBAT *directly* — deleting
  the whole gated battery divider (Q2, Q5, R7, R8, R16, R26, C8). Why it still loses:
  1. **Channel count** — INA226 is one current channel. WellD has two loop channels
     (J4/J5) plus battery → two INA226s + rework, vs one ADS1115 doing all of it on
     four muxed inputs.
  2. **Signal robustness at the terminals** — an 80 mV full-scale node behind outdoor
     surge clamps is far less forgiving of TVS/GDT leakage and offset than our 2 V
     node; the SMAJ5.0A leakage analysis (blocker #6) would have to be redone ~25×
     tighter. 4 Ω 0.1 % low-TCR shunts are also a less standard value than 100 Ω.
  3. **Continuous-monitor DNA** — INA226's strength is always-on power telemetry with
     averaging; our profile is one single-shot conversion per wake. ADS1115 powers
     down to <2 µA automatically after single-shot; INA226 needs explicit mode
     management (its power-down is fine, but nothing is gained).
  4. Firmware rewrite of a working, host-tested driver for zero field-visible benefit.
- **ADS1015**: 12 bit meets the cm-level need, saves pennies — not worth touching a
  written driver (unchanged from O-6).
- **ESP32-C6 internal ADC**: 12-bit SAR with well-documented INL/offset problems,
  needs per-unit calibration, and shares the die with the 802.15.4 radio whose
  interference is exactly why the wake-cycle orders ADC-before-radio. Eliminating the
  ADS1115 would save ~$1 and cost the design its measurement integrity. Rejected.
- Sourcing note from O-6 stands: buy the TI-genuine C37593 reel — ADS1115 clones are
  endemic.
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

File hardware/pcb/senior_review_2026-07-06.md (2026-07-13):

# Senior Hardware Review — 2026-07-06

Reviewer: Claude Fable 5 (direct review, per project owner's request).
Scope: full `hardware/pcb/` state after the 2026-07-05/06 cycle — electrical review pass (`bd3c3f0`), component selection review (`2e48249`), IP2326 datasheet verification (`a758a26`) — plus the firmware↔hardware contract changes on this branch.

## VERDICT: APPROVED for continued schematic work — **BLOCKED for layout/ordering** (unchanged from 2026-07-05; the gating item is symbol/BOM reconciliation, not a design flaw)

## CRITICAL (must fix before any layout or ordering)

1. **Schematic symbols still lag the BOM.** Verified by grep of `power.kicad_sch`: D15 (boost rectifier), Q3/Q4/Q5 (disconnect/driver/divider FETs), R15/R16/R25/R27/R29, C36, TP13, L3, RT1, R_VSET, and the IP2326 (U12) itself have BOM rows and net documentation but **no schematic symbols**; D8/D14 still carry `SMAJ28CA` values and C8 still 100 nF in the sheets vs SMAJ24CA / 1 nF in the BOM. Anyone generating a netlist or BOM from the schematic today builds the *old* design. This was warning #3 on 2026-07-05 and remains the tape-out gate.
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

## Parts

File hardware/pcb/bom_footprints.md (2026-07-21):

# WellD PCB — BOM with KiCad 10 Footprints

**Board:** size unconstrained — drawn around the finished placement (working target ≈100 × 60 mm with the top-side 18650 carrier); 2-layer, 1.6 mm FR4, 1 oz Cu  
**Assembler:** PCBWay PCBA  
**Sourcing key:** ✅ LCSC (direct PCBWay) · ⚠️ PCBWay global sourcing · 📦 Customer-supply to PCBWay

> **2026-07-05 electrical review:** several parts changed (U1, D8/D14, C8, C17, LED GPIO) and new components were added (D15, Q3–Q5, R15/R16/R25/R27/R29, C36, TP13). See `schematic_connections.md` → "Design changes" and "Datasheet verification blockers" before ordering.
>
> **2026-07-05 component-selection review** *(superseded by the 1S conversion — see the 2026-07-19 note below)* (`component_selection_review.md`): the non-functional TP5100 USB charge path is **replaced by an Injoinic IP2326 5 V→2S synchronous boost charger** (U12; +L3, R35 repurposed as ISET, R36/R37 deleted, F2 uprated to 2 A hold). Do not order the USB-charger section until verification blocker #2 (IP2326 datasheet items) is resolved — the mid-cell/balance-pin question could still reopen the choice.
>
> **2026-07-13 reconciliation pass:** all rows below now have matching schematic symbols (senior review 2026-07-06 CRITICAL 1–3 cleared). **CN3722 CRITICAL CV fix**: R33 590k→243k, R20 36k→158k, R19 repurposed as R_CS 0.4 Ω, U7 redrawn TSSOP-16 with its external buck stage (see the solar section). The IP2326 mid-cell question is resolved (VBATM/VBAT_GND float).
>
> **2026-07-19 — 1S CONVERSION (design change #18):** the pack is now **1S2P** (VBAT 3.0–4.2 V). U12 IP2326 → **TP4056** (L3/R_VSET/C_BST2/C_SYS1/C_SYS2/R35 deleted; R_PROG/R_NTC added); U7 CN3722 + external buck → **CN3791** (M_SOLAR/D16/C_COM1-3/R_COM2/R33/R34 deleted; D_SOLAR/L_SOLAR/C_VG/RT_SOLAR/R19 kept); U1 AP63203WU → **HT7333-A** (L2/C_BST_AP/R_FBH/R_FBL/R11 deleted); D13 → SMAJ5.0A, D8/D14 → SMAJ10CA; R7 → 100 k (÷2 divider). Verification status: see 1S blocker #10 in `schematic_connections.md`. Historical 2S rows below are marked rather than erased.

> **2026-07-14 full component verification sweep** (`component_verification_2026-07-14.md`): IP2326 package = **QFN24 4×4 mm** ✅, F2 = **MF-MSMF250/16X-2** ✅, NTCs = **SDNT1608X103F3950FTF** ✅, L_SOLAR **verified** ✅, L3 MPN picked ✅. Wrong LCSC numbers fixed (D1/D12, U6, U7); **D9/D10 changed SMAJ3.3CA → SMAJ5.0A** (leakage fail); **U1 needs a BST–SW 100 nF cap (C_BST_AP, new row) and its symbol renumbered** — see blocker #9 in `schematic_connections.md` for the required schematic edits. Remaining order blocker: pack PCM charge rating (#7a).

---

## Power — Battery Input

| Ref | Value | Package | KiCad 10 Footprint | MPN | LCSC | Notes |
|-----|---|---|---|-----|---|---|
| BT1 | **18650 battery carrier** (replaced J1 XT30, 2026-07-19) | SMD holder, ~78 mm terminal span + 2 alignment posts | **`Battery:BatteryHolder_Keystone_1042_1x18650`** ✅ (KiCad **standard** footprint — confirmed present 2026-07-21; no custom draw needed) | **Keystone 1042** (exact footprint match; Digi-Key/Mouser or PCBWay global-source); **LCSC single-source alt: MYOUNG BH-18650-B1BA002 (SMD, C2988620)** — same ~78 mm SMD form, verify its terminals land on the Keystone pads before ordering | Keystone 1042 = off-LCSC; BH-18650-B1BA002 = **C2988620**; MY-18650-02 clip pair = C2979182 | Pin 1=cell+ (−39.33), Pin 2=cell− (+39.33) → BATT_N through protection. Single generic 18650, ≈3–3.4 Ah |
| **U13** | **DW01A-G 1S protection supervisor** | SOT-23-6 | `Package_TO_SOT_SMD:SOT-23-6` | DW01A (PUOLOP) | **C351410** ✅ (PUOLOP, JLCPCB, in-stock $0.014, confirmed 2026-07-21) | **✅ verified 2026-07-19** (blocker #11a): OD=1/CS=2/OC=3/TD=4/VCC=5/GND=6; trip 2.40 V (release 3.0) / 4.30 V (release 4.1); 100Ω+100nF+1kΩ = datasheet typical app |
| **Q6** | **FS8205A dual N-FET** | TSSOP-8 | `Package_SO:TSSOP-8_4.4x3mm_P0.65mm` | FS8205A (Fortune) | **C14212** ✅ (Fortune Semicon, JLCPCB, confirmed 2026-07-21; LCSC alt C16052) | **✅ verified + symbol corrected 2026-07-19** (blocker #11b): D=1&8 (internally common), S1=2&3, G1=4, G2=5, S2=6&7; 20 V, ~6 A |
| **R_DW1** | 100Ω | 0402 | `Resistor_SMD:R_0402_1005Metric` | — | ✅ | **NEW** — DW01A VCC filter (with C_DW) |
| **C_DW** | 100nF | 0402 | `Capacitor_SMD:C_0402_1005Metric` | — | ✅ | **NEW** — DW01A VCC filter (to cell−/BATT_N) |
| **R_CS_DW** | 1kΩ | 0402 | `Resistor_SMD:R_0402_1005Metric` | — | ✅ | **NEW** — DW01A CS series resistor to system GND |
| D5 | AO3407 P-ch MOSFET | SOT-23 | `Package_TO_SOT_SMD:SOT-23` | AO3407 | C31417 ✅ | Reverse-polarity protection |
| R31 | 10kΩ 1% | 0402 | `Resistor_SMD:R_0402_1005Metric` | — | C25741 ✅ | D5 gate pull-down to GND (holds load switch ON) |
| D13 | **SMAJ5.0A TVS 5V uni** | DO-214AC | `Diode_SMD:D_SMA` | SMAJ5.0A | **C98802** ✅ (same reel as D9/D10) | Battery terminal TVS, **re-rated 2026-07-19** (1S): 5 V standoff clears the 4.2 V full charge; unidirectional — the forward diode clamps negative transients (reverse-battery is D5's job) |

---

## Power — USB-C Charging (TP4056 linear path — 1S conversion 2026-07-19; was IP2326 boost, was TP5100)

> **1S lineage:** TP5100 (couldn't boost 5 V→8.4 V) → IP2326 2S boost (2026-07-05) → **TP4056 1 A linear** (2026-07-19, 1S conversion — a 1S pack charges directly from 5 V USB; the entire boost stage is unnecessary). Open items: 1S blocker #10a in `schematic_connections.md` (pinout confirm, TEMP window math, thermal derating decision).

| Ref | Value | Package | KiCad 10 Footprint | MPN | LCSC | Notes |
|-----|---|---|---|-----|---|---|
| J13 | USB-C 2.0 power-only | 16-pin SMD + 4 THT shell legs | `Connector_USB:USB_C_Receptacle_HRO_TYPE-C-31-M-12` ✅ (confirmed present in KiCad standard lib 2026-07-21 — descr matches the krhro.com part; pads A1/A4/A5/A6/A7/A8/A9/A12/B-mirror/S1 all present) | **HRO TYPE-C-31-M-12** | **C165948** ✅ (order the Korean Hroparts listing specifically — part is endlessly cloned) | **SWAPPED 2026-07-19** (alternatives review P-2): was GCT USB4135-GF-A (~$1+, global sourcing) — GCT demoted to approved alternate (needs its own land pattern back). 16-pin USB-2.0 subset; symbol pins A1/A4/A5/A6/A7/B5 unchanged. ⚠️ Layout note: B-side mirror pins (B1/B4/B6/B7/B9/B12 etc.) tie to the same nets inside the footprint (GND/VBUS/D±) — check pad-to-net map when the footprint lands |
| U11 | USBLC6-2SC6 ESD | SOT-23-6 | `Package_TO_SOT_SMD:SOT-23-6` | USBLC6-2SC6 | C7519 ✅ | VBUS + D+/D− clamp. Pinout verified 2026-07-14: 1=I/O1, 2=GND, 3=I/O2, 4=I/O2, 5=VBUS, 6=I/O1 — **welld symbol must be renumbered** (blocker #9) |
| F2 | **MF-MSMF250/16X-2 PTC 2.5A hold** | **1812** | `Fuse:Fuse_1812_4532Metric` | MF-MSMF250/16X-2 | C210838 ✅ | **Resolved 2026-07-14** (blocker #8): 2.5 A hold / 5.0 A trip / 16 V / 100 A max / 15 mΩ, −40…+85 °C. Series with J13 VBUS; TP4056 draws ≈1 A charge (linear — no boost input multiplication), comfortable inside the derated 1.75–2 A hold at 60 °C. Schematic footprint field fixed 1206 → 1812 (2026-07-19) |
| U12 | **TP4056 1S linear charger 1A** | **SOP-8 + EPAD** | `Package_SO:SOIC-8-1EP_3.9x4.9mm_P1.27mm_EP2.29x2.29mm` (KiCad standard) | TP4056-42-ESOP8 (TopPower/NanJing) | **C16581** ✅ (found 2026-07-19 — the ESOP-8/EPAD variant) | **1S CONVERSION 2026-07-19** (replaced IP2326): 5 V VBUS → 4.2 V CC/CV linear, 1 A (R_PROG 1.2 k). CE (8) strapped to VUSB = auto-charge; /CHRG (7) open-drain → R38/TP15; /STDBY (6) NC. **EPAD GND pour required** (≈1.3 W at mid-charge; thermal regulation folds back at ≈120 °C die — drop R_PROG to 2.4 k → 0.5 A if the enclosure runs hot). Pinout confirm = 1S blocker #10a |
| **R_PROG** | **1.2kΩ 1%** | 0402 | `Resistor_SMD:R_0402_1005Metric` | — | ✅ | **NEW 2026-07-19** — TP4056 PROG (2) → GND; I_CH = 1200 V/R_PROG = **1 A** |
| **R_NTC** | **5.6kΩ 1%** | 0402 | `Resistor_SMD:R_0402_1005Metric` | — | ✅ | **NEW 2026-07-19** — TEMP-node divider top (VUSB → TEMP); with RT1 10 k B3950 → ✅ **computed** charge window **+8…+44 °C** |
| ~~L3, R35, R_VSET, C_BST2, C_SYS1, C_SYS2~~ | — | — | — | — | — | **DELETED 2026-07-19** — IP2326 boost support parts, gone with the 1S conversion |
| ~~R36~~ | — | — | — | — | — | **DELETED 2026-07-05** — TP5100 CE pull-up (historical) |
| ~~R37~~ | — | — | — | — | — | **DELETED 2026-07-05** — TP5100 CE pull-down; **GPIO4 spare** (TP4056 CE is strapped high in hardware — 2026-07-19) |
| R38 | 4.7kΩ | 0402 | `Resistor_SMD:R_0402_1005Metric` | — | ✅ | /CHRG_USB pull-up to +3V3 (routes to TP15 only). TP4056 /CHRG (7) is open-drain per datasheet — fit unconditionally |
| RT1 | **10kΩ NTC B3950 1%** | 0603 | `Resistor_SMD:R_0603_1608Metric` | **SDNT1608X103F3950FTF** (Sunlord) ✅ | — ✅ look up C# (3450 sibling is C95953) | TP4056 TEMP (1) low side (R_NTC 5.6 k top), thermally coupled to the pack — charge-temperature cutoff (`component_selection_review.md` O-1). MPN picked 2026-07-14. ✅ window math computed +8…+44 °C (1S blocker #10a resolved) |
| R50 | 5.1kΩ | 0402 | `Resistor_SMD:R_0402_1005Metric` | — | ✅ | J13 CC1 → GND (was "R_CC1") |
| R51 | 5.1kΩ | 0402 | `Resistor_SMD:R_0402_1005Metric` | — | ✅ | J13 CC2 → GND (was "R_CC2") |
| C27 | 4.7µF 10V X5R | 0805 | `Capacitor_SMD:C_0805_2012Metric` | — | ✅ | VUSB input filter after F2 |
| C28 | 10µF **25V** X5R | 0805 | `Capacitor_SMD:C_0805_2012Metric` | — | ✅ | U12 TP4056 VCC (4) bypass (10 µF per every TP4056 reference design; 25 V rating kept from the IP2326 era — harmless margin) |
| C29 | 10µF **25V** X5R | 0805 | `Capacitor_SMD:C_0805_2012Metric` | — | ✅ | U12 BAT-side bypass. Value ✅ confirmed 2026-07-14 (DS ref design: 10 µF + 22 µF at VOUT — 10 µF suffices at 1 A with the pack on the node); **uprated 16 V → 25 V** per DS |

---

## Power — Solar MPPT Charging (CN3791 path — 1S conversion 2026-07-19; was CN3722 + external buck)

> **2026-07-19 (1S conversion):** the CN3722 2S controller and its external buck stage are **deleted** — the CN3791 is the 1S sibling with an **integrated switch** and a **fixed 4.2 V CV at the BAT pin** (no CV divider at all), MPPT reference **1.205 V**. Kept from the old stage: D_SOLAR, L_SOLAR, C_VG, RT_SOLAR, R19 (now 0.1 Ω). Open verifications: 1S blocker #10b in `schematic_connections.md` (the Consonance CN3791 datasheet was not fetchable at conversion time — pinout, VG cap, sense formula, VIN range, TEMP thresholds all flagged). Historical CN3722 CV-reference saga: `component_verification_2026-07-14.md` and design changes #13–#15.

| Ref | Value | Package | KiCad 10 Footprint | MPN | LCSC | Notes |
|-----|---|---|---|-----|---|---|
| U7 | **CN3791 1S MPPT buck charge CONTROLLER** | **SSOP-10** | `Package_SO:SSOP-10_3.9x4.9mm_P1.00mm` | CN3791 | **C154992** ✅ (Consonance, confirmed in-stock LCSC 2026-07-21; supersedes the earlier C124423 guess) | **✅ datasheet-verified 2026-07-19** (blocker #10b, with corrections): external-P-FET controller (DRV pin, 8 V gate clamp), fixed 4.2 V ±1 % CV, MPPT ref 1.205 V ✅, VCC 4.5–28 V, I_CH = 120 mV/R_CS ✅ → **1.2 A** at R19 = 0.1 Ω, 300 kHz, BAT+CSP sleep ≈9 µA @ 4.2 V. **No TEMP pin** (→ blocker #10f) |
| **M_SOLAR** | **SI2319CDS P-ch MOSFET −40 V** | SOT-23 | `Package_TO_SOT_SMD:SOT-23` | SI2319CDS-T1-GE3 (Vishay) | **C146287** ✅ (clone alt C558254) | **RESTORED 2026-07-19** — the CN3791 is a controller; external buck P-FET is required after all (same part the alternatives review picked for the CN3722 stage) |
| **D16** | **SS34 Schottky 3A 40V** | DO-214AC | `Diode_SMD:D_SMA` | SS34 | C8678 ✅ | **RESTORED 2026-07-19** — series diode after M_SOLAR: blocks night back-feed VBAT→L_SOLAR→FET body diode→MPPT divider/VCC |
| **R_DRV** | 300kΩ | 0402 | `Resistor_SMD:R_0402_1005Metric` | — | ✅ | **NEW 2026-07-19** — M_SOLAR gate–source pull-off (per the Soldered Electronics CN3791 reference design) |
| **C_COM** | 220nF | 0402 | `Capacitor_SMD:C_0402_1005Metric` | — | ✅ | **NEW 2026-07-19** — CN3791 COM (5) compensation, series with R_COM (datasheet-required) |
| **R_COM** | 120Ω | 0402 | `Resistor_SMD:R_0402_1005Metric` | — | ✅ | **NEW 2026-07-19** — COM network low side to GND |
| **U14** | **LM393 dual comparator** | SOIC-8 | `Package_SO:SOIC-8_3.9x4.9mm_P1.27mm` | LM393DR (TI/onsemi/second sources) | **C7955** ✅ (onsemi LM393DR2G, JLCPCB **Basic** — no setup fee; confirmed in stock 2026-07-21) | **NEW 2026-07-19** — solar cold-charge cutoff (#10f resolved): powered from VSOLAR (zero night draw), ratiometric NTC threshold, clamps CN3791 MPPT via Q7 when < ≈+2 °C |
| RT_SOLAR | **10kΩ NTC B3950 1%** | 0603 | `Resistor_SMD:R_0603_1608Metric` | **SDNT1608X103F3950FTF** (Sunlord) ✅ | — ✅ (same reel as RT1) | **REVIVED 2026-07-19** for the LM393 cutoff (was deleted when the CN3791 turned out to have no TEMP pin) — thermally couple to the **cell** |
| **R_NT1** | **30kΩ 1%** | 0402 | `Resistor_SMD:R_0402_1005Metric` | — | ✅ | **NEW** — cutoff temp divider top; 30 k ≈ NTC B3950 at +2 °C → trip threshold |
| **R_NT2, R_NT3** | **100kΩ 1% ×2** | 0402 | `Resistor_SMD:R_0402_1005Metric` | — | ✅ | **NEW** — cutoff reference divider (0.5·VSOLAR, ratiometric) |
| **R_PU** | 100kΩ | 0402 | `Resistor_SMD:R_0402_1005Metric` | — | ✅ | **NEW** — LM393 OUT1 pull-up to VSOLAR |
| **R_HYS** | 330kΩ | 0402 | `Resistor_SMD:R_0402_1005Metric` | — | ✅ | **NEW** — hysteresis (≈2 °C: trip +2 °C falling, release ≈+4 °C) |
| **C_NTC** | 100nF | 0402 | `Capacitor_SMD:C_0402_1005Metric` | — | ✅ | **NEW** — U14 supply bypass |
| **Q7** | **AO3400A N-FET** | SOT-23 | `Package_TO_SOT_SMD:SOT-23` | AO3400A | **C20917** ✅ (same reel as Q2/Q4) | **NEW** — MPPT clamp switch (small-signal; Vgs ≈ VSOLAR ≤10 V vs ±12 V abs max — OK for ≤6 V-nominal panels) |
| D6 | MBRS140 Schottky 1A 40V | SMB | `Diode_SMD:D_SMB` | MBRS140T3G | — ✅ | Solar backfeed block (MBRS140T3G is SMB, not SOD-123) |
| D8 | **SMAJ10CA TVS 10V bidi** | DO-214AC | `Diode_SMD:D_SMA` | SMAJ10CA | **C320526** ✅ (LGE, confirmed in-stock LCSC 2026-07-21; was the unconfirmed C2836474) | **Re-rated 2026-07-19** (1S conversion): at CN3791 VIN; same reel as D14. Panel is now 6 V-nominal → Voc limit **10 V** (was SMAJ24CA / 24 V for the 12 V-panel 2S design) |
| ~~M_SOLAR, D16, C_COM1, C_COM2, C_COM3, R_COM2, R33, R34~~ | — | — | — | — | — | **DELETED 2026-07-19** (1S conversion) — the CN3791's integrated switch needs no external P-FET/series diode/compensation, and its fixed 4.2 V CV needs no divider. (M_SOLAR had been swapped to SI2319CDS earlier the same day — the swap died young; C146287 is simply not ordered) |
| **D_SOLAR** | **SS34 Schottky 3A 40V** | DO-214AC | `Diode_SMD:D_SMA` | SS34 | C8678 ✅ | Catch/freewheel diode (GND → SOLAR_SW), kept for the CN3791 stage — sanity-check against the CN3791 typical application (1S blocker #10b) |
| **L_SOLAR** | **22µH shielded** | 6×6×4.5mm SMD (same footprint) | `Inductor_SMD:L_Bourns-SRN6045TA` | **SRN6045TA-220M** | — ✅ (Isat 3.3 A) | **Resized 2026-07-19** (was 47µH SRN6045TA-470M, Isat 1.3 A ≈ 5 % margin). Computed peak ≈1.24 A; the 220M gives **Isat 3.3 A / Irms 2.3 A / DCR 96 mΩ**, 1.7× margin. Same 6045 footprint — no redraw. Ripple 182 mApp at 300 kHz, trivial |
| **R19** | **0.1Ω 1% (R_CS)** | **1206** | `Resistor_SMD:R_1206_3216Metric` | — | ✅ | **Re-valued 2026-07-19**: CSP–BAT sense; assumed I_CH = 120 mV/R_CS = **1.2 A**; P ≈ 0.14 W. ⚠️ Formula verify = 1S blocker #10b |
| R20 | **316kΩ 1% E96** | 0402 | `Resistor_SMD:R_0402_1005Metric` | — | ✅ | **Re-valued 2026-07-19**: MPPT divider high-side → V_MP = 1.205×(1+316/100) ≈ **5.01 V** (6 V-nominal panel). ⚠️ Recompute for the actual panel |
| R21 | **100kΩ 1%** | 0402 | `Resistor_SMD:R_0402_1005Metric` | — | ✅ | MPPT divider low-side (MPPT pin→GND); re-valued 10 k → 100 k 2026-07-19 (divider impedance scaled with R20) |
| **C_VG** | **100nF 50V** | 0402 | `Capacitor_SMD:C_0402_1005Metric` | — | ✅ | **NEW 2026-07-13** — VG (1) ↔ **VCC** (not GND) per datasheet |
| **C_COM1** | **470pF 50V** | 0402 | `Capacitor_SMD:C_0402_1005Metric` | — | ✅ | **NEW 2026-07-13** — COM1 (8) → GND |
| **C_COM2** | **220nF 25V** | 0402 | `Capacitor_SMD:C_0402_1005Metric` | — | ✅ | **NEW 2026-07-13** — COM2 (9) → C_COM2 → R_COM2 → GND |
| **R_COM2** | **120Ω 5%** | 0402 | `Resistor_SMD:R_0402_1005Metric` | — | ✅ | **NEW 2026-07-13** — series with C_COM2 |
| **C_COM3** | **100nF 25V** | 0402 | `Capacitor_SMD:C_0402_1005Metric` | — | ✅ | **NEW 2026-07-13** — COM3 (11) → GND |
| **RT_SOLAR** | **10kΩ NTC B3950 1%** | 0603 | `Resistor_SMD:R_0603_1608Metric` | **SDNT1608X103F3950FTF** (Sunlord) ✅ | — ✅ look up C# | **NEW 2026-07-13** — TEMP (6) → GND, thermally coupled to the pack: charge suspended below ≈+2°C / above ≈+54°C (55µA pull-up, 1.61V/0.175V thresholds). Solar-path cold-charge cutoff (review O-1). Same reel as RT1 (MPN picked 2026-07-14) |
| C17 | 10µF **35V** X5R | **1206** | `Capacitor_SMD:C_1206_3216Metric` | — | ✅ | CN3791 VIN filter (35 V rating generous now that the rail clamps at 10 V — keep, zero-cost margin) |
| C18 | 10µF 16V | 0805 | `Capacitor_SMD:C_0805_2012Metric` | — | ✅ | CN3791 BAT filter |
| C21 | 100nF **50V** | 0402 | `Capacitor_SMD:C_0402_1005Metric` | — | ✅ | HF bypass at CN3791 VIN (across D8) |
| R25 | 4.7kΩ | 0402 | `Resistor_SMD:R_0402_1005Metric` | — | ✅ | **NEW** — /CHRG_SOLAR pull-up to +3V3 (GPIO6; was internal pull-up only) |
| D7 | Green LED | 0603 | `LED_SMD:LED_0603_1608Metric` | — | ✅ | Solar-charging indicator: +3V3→R22→D7→/CHRG_SOLAR |
| R22 | 1kΩ **DNF** | 0402 | `Resistor_SMD:R_0402_1005Metric` | — | ✅ | D7 series resistor — DNF by default (fit for bench debug) |

---

## Power — 3.3 V LDO (HT7333-A — 1S conversion 2026-07-19; was AP63203 buck)

| Ref | Value | Package | KiCad 10 Footprint | MPN | LCSC | Notes |
|-----|---|---|---|-----|---|---|
| U1 | **HT7333-A LDO 3.3V 250mA** | SOT-23 | `Package_TO_SOT_SMD:SOT-23` | HT7333-A (Holtek) | **C21583** ✅ (confirmed 2026-07-19) | **✅ pinout verified 2026-07-19** (blocker #10d): GND=1, VOUT=2, VIN=3 (same as XC6206). 3.5–4 µA Iq, dropout ≈60 mV @ 100 mA, VIN 2–12 V. 250 mA ceiling fine for Zigbee-only (TX ≈ 80 mA); **Wi-Fi must stay disabled** |
| ~~C_BST_AP, L2, R_FBH, R_FBL, R11~~ | — | — | — | — | — | **DELETED 2026-07-19** — AP63203 support parts (bootstrap cap, inductor, DNP divider, EN pull-up); an LDO needs none of them |
| C16 | 10µF 16V X5R | 0805 | `Capacitor_SMD:C_0805_2012Metric` | — | ✅ | U1 VIN bulk (AP6320x datasheet CIN = 10µF; was an orphan symbol, now assigned) |
| C9 | 100nF 16V | 0402 | `Capacitor_SMD:C_0402_1005Metric` | — | ✅ | VIN bypass |
| C10 | 1µF 16V | 0402 | `Capacitor_SMD:C_0402_1005Metric` | — | ✅ | VIN bulk |
| C11 | 100nF | 0402 | `Capacitor_SMD:C_0402_1005Metric` | — | ✅ | VOUT bypass |
| C12 | 1µF | 0402 | `Capacitor_SMD:C_0402_1005Metric` | — | ✅ | VOUT bulk |
| C_BUCK | 10µF 10V X5R | 0805 | `Capacitor_SMD:C_0805_2012Metric` | — | ✅ | Primary output filter cap at U1 VOUT (ref kept from the buck era) |

---

## Power — 12V VLOOP Boost (MT3608B)

| Ref | Value | Package | KiCad 10 Footprint | MPN | LCSC | Notes |
|-----|---|---|---|-----|---|---|
| U8 | MT3608B boost 12V | SOT-23-6 | `Package_TO_SOT_SMD:SOT-23-6` | MT3608B | C84005 ✅ | GPIO5-gated, EN=HIGH during 4-20mA reads. Pin map **datasheet-confirmed 2026-07-14** (SW=1, GND=2, FB=3, EN=4, IN=5, NC=6 — KiCad official `MT3608` symbol agrees with both prior reviews); routine first-article check only |
| L1 | 4.7µH 1A shielded | 4×4mm SMD | `Inductor_SMD:L_4.0x4.0mm_H2.6mm` ⚠️verify name | CDRH4D22NP-4R7NC | C376098 ✅ | MT3608B boost inductor (was "same part as L2" — L2 deleted 2026-07-19) |
| R23 | 1.91MΩ 1% E96 | 0402 | `Resistor_SMD:R_0402_1005Metric` | — | ✅ | VOUT divider high-side → VOUT=0.6×(1+1910/100)=12.06V (matches schematic value) |
| R24 | 100kΩ 1% | 0402 | `Resistor_SMD:R_0402_1005Metric` | — | ✅ | VOUT divider low-side |
| C_BST | 100nF 16V | 0402 | `Capacitor_SMD:C_0402_1005Metric` | — | C14663 ✅ | Pin 6 ↔ SW. Pin 6 = NC **confirmed 2026-07-14** (KiCad official symbol) — cap is harmless; can be marked **DNF** at first article |
| **D15** | **SS34 Schottky 3A 40V** | DO-214AC | `Diode_SMD:D_SMA` | SS34 | C8678 ✅ | **NEW** — boost rectifier SW→VLOOP (MT3608 is an async boost; there was no rectifier in the BOM) |
| **Q3** | **AO3407 P-ch MOSFET** | SOT-23 | `Package_TO_SOT_SMD:SOT-23` | AO3407 | C31417 ✅ | **NEW** — VLOOP input disconnect (VBAT→Q3→L1); kills the permanent VBAT−0.4V leak through L1+D15 to the loop terminals during sleep |
| **Q4** | **AO3400A N-ch MOSFET** | SOT-23 | `Package_TO_SOT_SMD:SOT-23` | **AO3400A** (AOS) | **C20917** ✅ | Q3 gate driver, gate on VBOOST_EN (GPIO5). **SWAPPED 2026-07-19 from BSS123** (alternatives review P-1, settles O-3): Vgs(th) max 1.45 V vs 1.7 V — fully enhanced at 3.3 V drive; 2N7002 approved emergency second source (thinner 2.5 V-max threshold margin, fine at these µA loads) |
| **R29** | **100kΩ** | 0402 | `Resistor_SMD:R_0402_1005Metric` | — | ✅ | **NEW** — Q3 gate pull-up to VBAT (off by default) |
| **R27** | **100kΩ** | 0402 | `Resistor_SMD:R_0402_1005Metric` | — | ✅ | **NEW** — VBOOST_EN pull-down (GPIO5 floats in deep sleep) |
| C19 | 10µF 16V | 0805 | `Capacitor_SMD:C_0805_2012Metric` | — | ✅ | VIN bypass |
| C20 | 22µF 25V X5R | 1206 | `Capacitor_SMD:C_1206_3216Metric` | — | ✅ | VOUT filter |
| C22 | 10µF 25V X5R | 0805 | `Capacitor_SMD:C_0805_2012Metric` | — | ✅ | VOUT parallel with C20 |
| D11 | SMAJ13A TVS 13V uni | DO-214AC | `Diode_SMD:D_SMA` | SMAJ13A | **C110519** ✅ | VLOOP terminal clamp. Confirmed 2026-07-21: **C110519** (SMAJ13A-13-F, Diodes Inc, in stock); earlier C8057 stays unconfirmed, C110519 now primary |
| SJ1 | Solder jumper NO | — | `Jumper:SolderJumper-2_P1.3mm_Open_TrianglePad1.0x1.5mm` | — | — | MT3608B EN permanent tie, DNF |
| SJ2 | Solder jumper NC | — | `Jumper:SolderJumper-2_P1.3mm_Bridged_RoundedPad1.0x1.5mm` | — | — | J4/J5 VLOOP bus share |

---

## Battery Divider

| Ref | Value | Package | KiCad 10 Footprint | MPN | LCSC | Notes |
|-----|---|---|---|-----|---|---|
| Q2 | **AO3400A N-ch MOSFET** | SOT-23 | `Package_TO_SOT_SMD:SOT-23` | **AO3400A** (AOS) | **C20917** ✅ | Gate=GPIO15; drives Q5's gate (level shifter). **SWAPPED 2026-07-19 from BSS123** (alternatives review P-1) — see Q4; 2N7002 approved second source |
| **Q5** | **AO3407 P-ch MOSFET** | SOT-23 | `Package_TO_SOT_SMD:SOT-23` | AO3407 | C31417 ✅ | **NEW** — high-side divider disconnect (old low-side switch leaked ~14µA into ADS1115 AIN2 during sleep) |
| **R16** | **100kΩ** | 0402 | `Resistor_SMD:R_0402_1005Metric` | — | ✅ | **NEW** — Q5 gate pull-up to VBAT |
| R7 | **100kΩ 1%** | 0402 | `Resistor_SMD:R_0402_1005Metric` | — | ✅ | Divider high-side (VBAT→midpoint). **Re-valued 2026-07-19** (1S): ÷2 with R8 → 2.1 V max at AIN2 (firmware ratio 430 → 200; AIN2 read must move to the ±4.096 V PGA — 1S blocker #10c) |
| R8 | 100kΩ 1% | 0402 | `Resistor_SMD:R_0402_1005Metric` | — | ✅ | Divider low-side (midpoint→GND, direct) |
| R26 | 4.7kΩ | 0402 | `Resistor_SMD:R_0402_1005Metric` | — | ✅ | Q2 gate pull-down |
| C8 | **1nF** X7R | 0402 | `Capacitor_SMD:C_0402_1005Metric` | — | ✅ | Across R8. Was 100nF → τ≈7.7ms, too slow for the firmware's ≥1ms enable window; 1nF settles in <1ms |

---

## MCU — ESP32-C6

| Ref | Value | Package | KiCad 10 Footprint | MPN | LCSC | Notes |
|-----|---|---|---|-----|---|---|
| U6 | ESP32-C6-MINI-1U-H4 | Module | `RF_Module:ESP32-C6-MINI-1` 📦 or Espressif KiCad lib | ESP32-C6-MINI-1U-H4 | **C20627095** ✅ (**corrected 2026-07-14** — old C2913202 does not match; ~$3.16, in stock) | Download Espressif KiCad libraries from github.com/espressif/kicad-libraries |
| C13, C30–C33 | 100nF ×5 | 0402 | `Capacitor_SMD:C_0402_1005Metric` | — | ✅ | VCC3V3 decoupling, within 2mm of module pads (schematic refs; were documented as "C14a–C14d") |
| **R15** | **10kΩ** | 0402 | `Resistor_SMD:R_0402_1005Metric` | — | ✅ | **NEW** — ESP32 EN pull-up to +3V3 |
| **C36** | **1µF** | 0402 | `Capacitor_SMD:C_0402_1005Metric` | — | ✅ | **NEW** — ESP32 EN→GND reset-delay cap (10ms RC with R15) |
| C15 | 10µF 10V | 0805 | `Capacitor_SMD:C_0805_2012Metric` | — | ✅ | VCC3V3 bulk |
| R12 | 10kΩ | 0402 | `Resistor_SMD:R_0402_1005Metric` | — | ✅ | GPIO9 BOOT pull-up |
| R13 | 10kΩ | 0402 | `Resistor_SMD:R_0402_1005Metric` | — | ✅ | GPIO8 strapping pull-up |
| SW1 | Reset tactile 6×6mm | SMD | `Button_Switch_SMD:SW_Push_6mm_H4.3mm` | — | ✅ | Pulls ESP32 EN to GND |
| SW2 | Boot tactile 6×6mm | SMD | `Button_Switch_SMD:SW_Push_6mm_H4.3mm` | — | ✅ | Pulls GPIO9 to GND |
| D4 | Status LED green | 0603 | `LED_SMD:LED_0603_1608Metric` | — | ✅ | **GPIO14** → R14 → D4 → SJ3 → GND (moved off GPIO13: a green LED + 1k to GND held the factory-reset strap below V_IH → NVS wipe every boot) |
| R14 | 1.0kΩ | 0402 | `Resistor_SMD:R_0402_1005Metric` | — | ✅ | LED current limit |
| SJ3 | Solder jumper NC | — | `Jumper:SolderJumper-2_P1.3mm_Bridged_RoundedPad1.0x1.5mm` | — | — | LED disconnect to save current |

---

## ADC — ADS1115

| Ref | Value | Package | KiCad 10 Footprint | MPN | LCSC | Notes |
|-----|---|---|---|-----|---|---|
| U9 | ADS1115IDGST 16-bit I²C | MSOP-10 | `Package_SO:MSOP-10_3x3mm_P0.5mm` | ADS1115IDGST | C37593 ✅ | Addr 0x48 (ADDR→GND) |
| FB1 | 600Ω@100MHz ferrite | **0603** | `Inductor_SMD:L_0603_1608Metric` | BLM18KG601SN1D | C76537 ✅ | In +3V3 feed to U9 VDD. **Footprint corrected 2026-07-14**: BLM18 series is 1608-metric = **0603** (the old row said 0402 — that would be BLM15AX601SN1D) |
| C23 | 100nF | 0402 | `Capacitor_SMD:C_0402_1005Metric` | — | ✅ | U9 VDD bypass, U9 side of FB1 |
| C24 | 1µF | 0402 | `Capacitor_SMD:C_0402_1005Metric` | — | ✅ | U9 VDD bulk |
| R9 | 4.7kΩ | 0402 | `Resistor_SMD:R_0402_1005Metric` | — | ✅ | I²C SDA pull-up (GPIO10) |
| R10 | 4.7kΩ | 0402 | `Resistor_SMD:R_0402_1005Metric` | — | ✅ | I²C SCL pull-up (GPIO11) |
| **R_DRDY** | **4.7kΩ** | **0402** | `Resistor_SMD:R_0402_1005Metric` | — | ✅ | **ADD TO SCHEMATIC** — ADS_DRDY to +3V3; required open-drain pull-up |

---

## Sensors — 4-20mA Channels

| Ref | Value | Package | KiCad 10 Footprint | MPN | LCSC | Notes |
|-----|---|---|---|-----|---|---|
| D9 | **SMAJ5.0A TVS 5V uni** | DO-214AC | `Diode_SMD:D_SMA` | SMAJ5.0A-TR (ST) | **C98802** ✅ | J4 SIG surge clamp. **CHANGED 2026-07-14 from SMAJ3.3CA** (blocker #6 FAIL: IR = 800 µA max at VRWM — un-guaranteeable at the 2.0 V node). VBR min 6.4 V → 2.0 V working point far below the knee; Vc 9.2 V; forward diode clamps negatives; R3/R5 + D1 still protect the ADS1115 pins. **Schematic value edit required** (blocker #9c) |
| D10 | **SMAJ5.0A TVS 5V uni** | DO-214AC | `Diode_SMD:D_SMA` | SMAJ5.0A-TR (ST) | **C98802** ✅ | J5 SIG surge clamp — see D9 |
| **GDT1** | **GDT 90V DNF** | 8×6 mm SMD 2-pole | `WellD:GDT_BOURNS_2038_SM` ⚠️ draw in WellD.pretty (no standard lib footprint) | BOURNS 2038-09-SM class (e.g. 2038-09-SM-RPLF; Littelfuse GTCS23-900M-R05 alternate) | — ⚠️ | **NEW 2026-07-19 (DNF)** — alternatives review P-3: coarse kA-class stage of the industrial GDT → series-R → TVS 3-stage loop protection, LOOP_TERM_CH1 → GND. **Footprint only, do not fit by default** — populate per site only for long/buried/aerial transducer cable runs |
| **GDT2** | **GDT 90V DNF** | 8×6 mm SMD 2-pole | `WellD:GDT_BOURNS_2038_SM` ⚠️ draw in WellD.pretty | same as GDT1 | — ⚠️ | **NEW 2026-07-19 (DNF)** — LOOP_TERM_CH2 → GND, see GDT1 |
| D1 | PRTR5V0U2X dual ESD | SOT-143B | `Package_TO_SOT_SMD:SOT-143` | PRTR5V0U2X,215 | **C12333** ✅ (**corrected 2026-07-14** — old C2687116 is a UMW USBLC6-2SC6 clone) | ADS1115 AIN0/AIN1 input clamp. Pinout verified: **1=GND, 2=I/O1, 3=I/O2, 4=VCC** — welld 6-pin SOT-363 symbol must be redrawn (blocker #9b) |
| R2 | 100Ω ±0.1% 0.25W | 0805 | `Resistor_SMD:R_0805_2012Metric` | RG2012N-101-W-T1 | — ⚠️ | CH1 shunt (AIN0 reads across this) |
| R4 | 100Ω ±0.1% 0.25W | 0805 | `Resistor_SMD:R_0805_2012Metric` | RG2012N-101-W-T1 | — ⚠️ | CH2 shunt |
| C34 | 10nF X7R 25V | 0402 | `Capacitor_SMD:C_0402_1005Metric` | — | ✅ | HF bypass directly across R2 (was "C_SH1") |
| C35 | 10nF X7R 25V | 0402 | `Capacitor_SMD:C_0402_1005Metric` | — | ✅ | HF bypass directly across R4 (was "C_SH2") |
| R3 | 100Ω | 0402 | `Resistor_SMD:R_0402_1005Metric` | — | ✅ | CH1 series limiter to AIN0 |
| R5 | 100Ω | 0402 | `Resistor_SMD:R_0402_1005Metric` | — | ✅ | CH2 series limiter to AIN1 |
| C3 | 1µF X5R | 0402 | `Capacitor_SMD:C_0402_1005Metric` | — | ✅ | CH1 RC filter with R3 (fc≈1.6kHz) |
| C5 | 1µF X5R | 0402 | `Capacitor_SMD:C_0402_1005Metric` | — | ✅ | CH2 RC filter with R5 |
| C4 | 10µF 10V | 0805 | `Capacitor_SMD:C_0805_2012Metric` | — | ✅ | CH1 bulk |
| C6 | 10µF 10V | 0805 | `Capacitor_SMD:C_0805_2012Metric` | — | ✅ | CH2 bulk |

---

## Sensors — DS18B20 1-Wire

| Ref | Value | Package | KiCad 10 Footprint | MPN | LCSC | Notes |
|-----|---|---|---|-----|---|---|
| D12 | PRTR5V0U2X dual ESD | SOT-143B | `Package_TO_SOT_SMD:SOT-143` | PRTR5V0U2X,215 | **C12333** ✅ (corrected 2026-07-14) | Same part as D1; 1-Wire DATA ESD clamp (I/O2 channel NC) |
| R6 | 4.7kΩ | 0402 | `Resistor_SMD:R_0402_1005Metric` | — | ✅ | 1-Wire pull-up to +3V3 |
| R28 | 100Ω | 0402 | `Resistor_SMD:R_0402_1005Metric` | — | ✅ | VCC series protection |
| R32 | 33Ω | 0402 | `Resistor_SMD:R_0402_1005Metric` | — | ✅ | **POPULATE** (was DNF) — GPIO abs-max protection for cable runs; resolves review warning #15 |
| C7 | 100nF | 0402 | `Capacitor_SMD:C_0402_1005Metric` | — | ✅ | J6 VCC bypass |

---

## Solar Input Protection

| Ref | Value | Package | KiCad 10 Footprint | MPN | LCSC | Notes |
|-----|---|---|---|-----|---|---|
| D14 | **SMAJ10CA TVS 10V bidi** | DO-214AC | `Diode_SMD:D_SMA` | SMAJ10CA | **C320526** ✅ (LGE, confirmed 2026-07-21) | At J12 SOLAR+ terminal; same reel as D8. **Re-rated 2026-07-19** (1S, 6 V-nominal panel — was SMAJ24CA for 12 V panels) |

---
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

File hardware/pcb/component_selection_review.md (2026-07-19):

# WellD PCB — Component Selection Review — 2026-07-05

> **⚠️ SUPERSEDED IN PART — 1S CONVERSION 2026-07-19 (design change #18):** this review
> evaluated parts for a **2S** (6.0–8.4 V) architecture. The user has since switched the
> design to **1S2P** (3.0–4.2 V). Consequences for the verdicts below: the **IP2326**
> (item 1) and **CN3722** (solar section) selections are **deleted** — replaced by
> **TP4056** (1 A linear USB charger) and **CN3791** (1S MPPT buck, integrated switch);
> the **AP63203WU** buck is **deleted** (VIN min 3.8 V fails at 1S empty) — replaced by
> the **HT7333-A** LDO. The O-1 NTC cold-charge requirement carries over to both new
> chargers (RT1 on TP4056 TEMP, RT_SOLAR on CN3791 TEMP). Everything else in this review
> (MT3608B, ADS1115, ESP32-C6, protection, connectors) still stands. Current state:
> `schematic_connections.md` (1S blocker #10) and `bom_footprints.md`. This file is kept
> as the historical record of the 2S-era reasoning.

**Scope:** selection/architecture review of every active component and key passive in
`bom_footprints.md`. This is *not* a wiring pass — the electrical-gate/wiring review ran
last cycle (`senior_review_2026-05-25.md` + the 2026-07-05 design-change list in
`schematic_connections.md`). No datasheet access was available during this review: every
parameter marked ⚠️ **verify** has been added to the blocker list in
`schematic_connections.md` and must be confirmed against the vendor datasheet before
schematic capture / tape-out.

**Review criteria:** electrical fit for a 2S Li-ion (6.0–8.4 V), sleep-dominated
(≈15 ms VLOOP duty per 5-min wake) outdoor device; quiescent draw; temperature range
(outdoor enclosure, assume −20…+60 °C internal); LCSC/PCBWay sourcing;
hand-solderability where rework is plausible.

**Verdict summary:**

| Item | Decision |
|---|---|
| 1. TP5100 (USB charger) | **REPLACED (firm)** → Injoinic **IP2326** 5 V→2S synchronous boost charger. BOM + wiring reference updated. |
| 2. CN3722 (solar MPPT) | **Keep.** Co-charging with IP2326 is safe; two verify items added (night-time BAT quiescent, TEMP/NTC pin). |
| 3. AP63203WU (3.3 V buck) | **Keep.** 22 µA Iq is acceptable for the sleep budget; TPS62902 noted as a lower-Iq alternative, not worth the package downgrade. |
| 4. MT3608B (12 V boost) | **Keep** with the existing D15 + Q3/Q4 external load disconnect. No common alternative offers true disconnect at VIN > 8.4 V for this price/package. |
| 5. Everything else | Recommendations only — see findings table. Two new systemic risks flagged: **no battery-temperature charge cutoff** (Li-ion charging below 0 °C) and **PTC F2 undersized for a boost charger's input current** (F2 change made firm as part of the charger swap). |

---

## 1. USB charger: TP5100 → IP2326 (FIRM CHANGE)

### Why TP5100 had to go
TP5100 is a switching **step-down** 1S/2S charger: VIN must exceed the pack CV point
(8.4 V + margin). From 5 V USB it can never charge a 2S pack — the path was
non-functional as designed (already flagged in the BOM header). Two fix architectures
were considered:

| Option | Parts | Assessment |
|---|---|---|
| A. Keep TP5100, add 5 V→12 V pre-boost (e.g. a second MT3608B at ~2 A) | 2 ICs, 2 inductors, diode | Double conversion (boost→buck), ~80 % end-to-end efficiency, two hot loops, TP5100 package still wrong in the schematic (QFN-16, not SOP-8), more board area in an already-tight 80×55 mm layout. |
| **B. Replace with an integrated 5 V→2S boost charger (IP2326)** | **1 IC, 1 inductor** | Single synchronous conversion (~90 %), purpose-built for exactly this topology (2S packs charged from USB — ubiquitous in 2S power tools/lamps/speakers), ESOP-8 is hand-reworkable, Injoinic is an LCSC-native brand with strong stock history. **Chosen.** |

### IP2326 — selection rationale
- **Function:** synchronous boost charger, 5 V VBUS in → 8.4 V CV / CC into a 2S pack,
  up to ~2 A charge current (we set ~1 A), with input-power-adaptive throttling that
  folds back charge current when a weak USB source sags — this is what makes it safe on
  an uncharacterised 5 V wall adapter behind our passive 5.1 kΩ CC sink strapping.
- **Package:** ~~ESOP-8 (SOP-8 + exposed pad)~~ **CORRECTED 2026-07-06: 24-pin + EPAD** (see the datasheet-verification addendum at the end of this file). Original text kept for the audit trail. Hand-solderable, and the existing Group G
  8×8 mm thermal pour requirement in `placement_constraints.md` carries over (≈0.9 W
  dissipation at 1 A charge, 90 % efficiency).
- **Sourcing:** Injoinic (英集芯) is stocked directly at LCSC; exact C-number to be looked
  up at order time (deliberately not quoted here — see blockers).
- **Runners-up:** CS5095 (cheaper, less documented, weaker adaptive input limiting);
  SC8815 (Southchip buck-boost, I²C controlled — capability overkill, QFN-32, needs
  firmware driver); MT3608B pre-boost + TP5100 (option A above, rejected).

### Integration changes (applied to BOM + `schematic_connections.md`)
- **U12** TP5100 SOP-8 → **IP2326 ESOP-8**.
- **L3 (NEW):** boost power inductor, placeholder 2.2 µH / Isat ≥ 3 A / 5×5 mm — final
  value per datasheet ⚠️.
- **R35** repurposed: TP5100 PROG (1.2 kΩ = 1 A) → IP2326 **ISET**, value TBD per
  datasheet for ~1 A ⚠️.
- **R36, R37 removed; GPIO4 freed.** IP2326-class chargers auto-run when VBUS is present
  and (per training-data recollection) expose no CE pin. If the datasheet proves an
  enable exists, GPIO4 gating can be restored — flagged in blockers. **Firmware must be
  told GPIO4 is no longer USB_CE** (it currently drives it HIGH to charge; driving an
  unconnected pin is harmless, so firmware can lag the PCB without hazard).
- **R38** kept (4.7 kΩ to +3V3 → TP15): reassign to the IP2326 charge-status/LED pin;
  verify pin, polarity, and whether it is open-drain ⚠️.
- **NTC pin:** IP2326 has an NTC input. Strap components are TBD pending the datasheet
  ⚠️ — and see finding O-1 below: we should *use* it, not strap it out.
- **F2** 1.1 A-hold PTC → **2 A-hold** (e.g. Bourns MF-MSMF200/16X class ⚠️ verify exact
  suffix/voltage). A boost charger's *input* current exceeds its charge current:
  1 A × 8.4 V / (5 V × 0.9) ≈ **1.9 A at VBUS** — the old MF-MSMF110 (1.1 A hold) would
  sit in trip territory during every normal charge.
- **C27/C28/C29** retained (values within IP2326 app-note norms; confirm ⚠️).
- USB-C front end unchanged: J13, U11 USBLC6-2SC6, R50/R51 5.1 kΩ CC sinks.

### Open risk carried as a blocker
IP2326 is documented (from training data) as supporting **2-cell balancing via a
mid-cell pin**. The WellD pack is a sealed 2S1P with integrated PCM and a **2-pin XT30**
— there is no mid-cell tap. Verify from the datasheet whether the balance/mid-cell pin
may be left unconnected (or strapped) when no tap exists. If it is mandatory, the
fallback is either (a) a 3-pin battery connector (J1 change → case + BOM impact) or
(b) the CS5095-class no-balance alternative. This is blocker #2a and is the single item
that could reopen the charger decision.

---

## 2. CN3722 solar MPPT — keep

- **Fit:** 2S CC/CV with resistor-programmed MPPT and CV = 8.31 V (R33 = 590 k, fixed
  last cycle), VIN to 28 V abs max with the panel now clamped to 24 V Voc by SMAJ24CA.
  That is exactly the requirement; TI BQ24650 is the "nicer" alternative (true
  perturb-free VMPPT regulation, ±0.5 % CV) but is a QFN-16 external-FET controller —
  more parts, more cost, harder rework — unjustified for a 500 mA charge rate. Keep.
- **Co-charging with IP2326:** both are current-limited CC/CV sources feeding the same
  pack node; parallel CC/CV chargers onto a battery are inherently safe (each folds back
  as VBAT rises). Worst case combined current ≈ 0.5 A + 1 A = 1.5 A; for a typical
  ≥2.5 Ah 2S1P that is <0.6 C — fine, but ⚠️ **verify the pack PCM charge-current rating
  ≥ 2 A**. CV interaction: IP2326 (presumed fixed 8.40 V) tops the pack slightly above
  CN3722's 8.31 V, so with USB attached the USB charger finishes the charge — acceptable
  (8.40 V is the cell spec max; USB charging is a maintenance event, not the normal
  mode). No shared control pins, no conflict; CN3722 charges autonomously exactly as
  before.
- **New verify items (added to blockers):**
  - CN3722 **battery-pin quiescent when the panel is dark** — this drain is on the pack
    every night, all winter. Expect low single-digit µA; confirm.
  - CN3722 **TEMP/NTC pin** — the current 8-pin symbol is already suspect (blocker #4,
    likely SSOP-10). If the real part exposes a TEMP pin, wire it (finding O-1).
- **/CHRG interaction note:** GPIO6 solar-detect semantics are unchanged.

---

## 3. AP63203WU 3.3 V buck — keep (Iq analysis)

Sleep-current stack-up on the pack, as designed:

| Consumer | Sleep draw |
|---|---|
| AP63203WU Iq (VIN pin, PFM/sleep mode) | ~22 µA (datasheet typ ⚠️ verify it applies unloaded) |
| ESP32-C6-MINI-1U deep sleep | ~8–15 µA (on 3V3, ≈4–7 µA reflected to VBAT) |
| ADS1115 in power-down (kept powered on +3V3_ADS) | ~0.5–2 µA |
| DS18B20 standby (J6 VCC always fed via R28) | ~1 µA |
| CN3722 BAT-pin dark quiescent | ⚠️ verify (~3 µA expected) |
| IP2326 BAT-pin quiescent, USB absent | ⚠️ verify (<10 µA required) |
| R11 EN pull-up (10 k to VBAT, EN input leakage only) + FET pull-up leakages | negligible |
| **Total** | **≈ 35–45 µA at VBAT** |

At ~40 µA a 2.5 Ah 2S1P self-drains ≈ 1 mAh/day → ~1.2 %/month — comfortably inside a
solar-topped budget, and the buck's 22 µA is not the dominant term once charger
quiescents are counted. Alternatives considered:

| Part | Iq | Why not |
|---|----|---|
| TI TPS62840 (60 nA) | superb | VIN max 6.5 V — cannot take 8.4 V. Disqualified. |
| TI TPS62902 (SOT-583) | ~4 µA, VIN 3–17 V | Real contender; saves ~18 µA (≈0.4 mAh/day). Costs a 0.5 mm-pitch leadless package (rework pain) and a TI-at-LCSC stock gamble. Not worth it — **recommendation only**, revisit if the measured sleep floor disappoints. |
| ST ST1PS03, Torex XC9265 etc. | sub-µA | VIN ≤ 5.5–6 V class — disqualified by 2S input. |
| LDO (TPS7A02) | 25 nA | 8.4→3.3 V at the ESP32's ~350 mA TX peak = 1.8 W dissipation. Disqualified. |

Verdict: **AP63203WU-7 stays.** Existing blocker #1 (confirm 3.3 V-fixed variant, FB tie,
BST cap need) already covers the datasheet risk. TSOT-26 is hand-solderable; Diodes Inc
is well stocked at LCSC.

---

## 4. MT3608B 12 V boost — keep, with the external disconnect

- **Duty profile:** ~15 ms per 5-min wake → duty ≈ 5×10⁻⁵. Efficiency at load is
  irrelevant; what matters is (a) zero sleep leakage — solved structurally by Q3
  (input-side P-FET disconnect) + R27, added last cycle, and (b) EN-low quiescent of the
  IC itself (<1 µA class ⚠️ verify).
- **Alternatives with true integrated load disconnect** were searched: parts with output
  disconnect (TPS61230A, TPS610995, MAX17222 …) top out at 5.5 V VIN — none accept
  6.0–8.4 V in. Boosters that do accept 2S input (TPS61175, TPS55340, SGM6623, MT3540)
  are async like the MT3608 and/or bring no disconnect either, at 3–10× the price.
  Conclusion: **there is no drop-in "better" part** — the MT3608B + SS34 + Q3/Q4
  disconnect is the correct minimal architecture. Keep.
- Selection-level notes retained/confirmed:
  - Existing blocker #3 (pin 6 BST vs NC, pin numbering) stands.
  - L1 (CDRH4D22, ~1 A Isat) saturates transiently during C20/C22 inrush at enable
    (senior-review warning #6). Acceptable at this duty cycle; **recommendation:** if L1
    is respun for any reason, choose 4.7 µH with Isat ≥ 2 A in the same 4×4 footprint
    (e.g. NR4018/XAL40xx class).
  - SJ1 (EN-to-VBAT bench tie) bypasses R27's sleep pull-down **and** leaves Q3 gated by
    Q4 anyway — harmless, fine as a debug aid.

---

## 5. Other findings (recommendations unless marked firm)

| # | Component | Finding | Action |
|---|---|---|---|
| **O-1** | **Charging vs temperature (systemic)** | Outdoor enclosure + Li-ion: **charging below 0 °C causes lithium plating**. Neither charger path currently has a battery-temperature cutoff (pack PCM protects V/I, typically not charge temperature). Both selected chargers likely expose NTC/TEMP pins (IP2326: NTC; CN3722: TEMP ⚠️ verify). | **Recommendation (strong):** add a 10 k NTC thermistor pad near/on the pack, wired to both chargers' temperature pins per datasheet; if the pack can't host one, a board-mounted NTC inside the case is a decent proxy. Added to blockers as datasheet-verify items. |
| O-2 | D5 (AO3407 reverse protection) | A MOSFET carrying a **D** refdes. Electrically fine (Vgs = −8.4 V vs ±12 V abs max — 30 % margin OK; Vds −30 V OK). | Rename **D5 → Q1** at schematic-capture time for refdes hygiene (this is the "missing Q1"). Cosmetic — recommendation. |
| O-3 | Q2/Q4 BSS123 | Vgs(th) max 1.7 V; driven at 3.3 V it only reaches "barely enhanced" spec corners at cold. Loads are trivial (100 k gate pull-ups → <100 µA drain current) so it works, but margin is thin and BSS123's LCSC row in the BOM has no C-number. | **Recommendation:** substitute **AO3400A** (Vgs(th) ≤ 1.45 V, LCSC C20917, same SOT-23) for Q2/Q4 — also consolidates on one N-FET vendor alongside the AO3407s. |
| O-4 | Q3/Q5 AO3407 | Correct: Vds −30 V, Vgs ±12 V vs 8.4 V drive, Rds(on) ~50 mΩ at Vgs −4.5 V — fine for 45 mA (Q3) / µA (Q5). LCSC C31417 stocked. | Keep. |
| O-5 | TVS strategy | Coherent: SMAJ10CA (VBAT, 10 V standoff > 8.4 V), SMAJ24CA ×2 (solar, panel Voc ≤ 24 V), SMAJ13A (VLOOP 12.06 V — 8 % standoff margin, clamp ≈21.5 V < 25 V caps), SMAJ3.3CA (loop SIG, node max 2.0 V). One risk: **low-voltage TVS have soft knees** — SMAJ3.3CA leakage at a 2.0 V working node feeds through the 100 Ω shunt and reads as loop current. 1 µA ≈ 0.005 % FS (harmless); 100 µA would not be. | ⚠️ Verify SMAJ3.3CA leakage at 2.0 V/60 °C ≤ 1 µA (added to blockers). If it fails, move to a 5 V-standoff low-leakage clamp (e.g. SMAJ5.0A) and accept the higher clamp level — R3 + D1 (PRTR5V0U2X to +3V3) still protects the ADS1115 pin. |
| O-6 | ADS1115IDGST | Right part: 16-bit/PGA/ALERT-DRDY/I²C, 2–5.5 V, powers down to <2 µA after single-shot (it stays on +3V3_ADS in sleep — fine). ADS1015 (12-bit) would actually meet the cm-level resolution need, but the saving is pennies and the firmware/driver is written. −40…+125 °C. MSOP-10 hand-solderable. | Keep. **Sourcing note:** buy the TI-genuine C37593 reel, not a "TI-compatible" clone — clone ADS1115s are endemic and have worse PGA accuracy/DRDY behaviour. |
| O-7 | ESP32-C6-MINI-1U-H4 | Correct (external-antenna variant matches the SMA/pigtail case design; −40…+85 °C; 4 MB flash fits the dual-1.5 MB OTA table). Existing blocker #5 (official Espressif symbol) stands. | Keep. |
| O-8 | USBLC6-2SC6 on a power-only port | Works, but 4 of its 6 pins clamp D± stubs that go nowhere. | Optional simplification: a single SMF5.0A on VBUS_IN would do. Not worth churn — keep. |
| O-9 | J13 USB4135-GF-A | Fine mechanically, but LCSC availability is ⚠️ (global sourcing). | **Recommendation:** allow HRO/Korean-J alternates (e.g. TYPE-C-31-M-12, LCSC C165948 class) as an approved second source — same 16-pin power-only footprint family; confirm footprint match before substituting. |
| O-10 | R2/R4 shunts (RG2012N 0.1 %) | Susumu RG-series via global sourcing only. 40 mW dissipation at 20 mA — any 0805 works; what matters is 0.1 % + low TCR (≤25 ppm/°C for outdoor ΔT: 25 ppm × 40 °C = 0.1 % extra — borderline). | **Recommendation:** approve an LCSC-stocked 0.1 % 25 ppm 0805 alternate (UNI-ROYAL/Viking precision series) to avoid a single-line global-sourcing stall. Keep 0.1 %/25 ppm as hard spec. |
| O-11 | Ceramics X5R/X7R | X5R is fine to −55 °C on the low end (outdoor cold is not a rating problem). DC-bias derating is the real issue: C17 (10 µF/35 V/1206 at up to 24 V) will deliver ~3–4 µF effective — acceptable for a TVS-clamped input filter; C20 22 µF/25 V/1206 at 12 V → ~10 µF effective, still fine for a 20 mA load. | No change. Note DC-bias expectation in layout notes if C17 behaviour ever surprises. |
| O-12 | Phoenix MC 1.5 G + STF plugs, XT30PW-F | Good outdoor-serviceability choices; G-header/STF-plug compatibility note in the BOM is correct. | Keep. |
| O-13 | DS18B20 (field probe) | Not on the BOM (external), but same counterfeit warning as O-6: clone DS18B20s dominate the market and misbehave at exactly the parasitic/timing corners this design avoids. | Procurement note: buy probes with genuine ADI/Maxim silicon or from a vetted supplier. |
| O-14 | placement_constraints.md Group G | Now stale: written for TP5100. IP2326 keeps the 8×8 mm pour but **adds a boost hot loop** (L3 ↔ SW ↔ internal sync FET ↔ C29/C28) that needs MT3608B-style tight-loop rules. | Follow-up edit to `placement_constraints.md` once the IP2326 datasheet confirms pinout (deliberately not edited in this review — placement doc is downstream of the datasheet verification). |

---

## BOM diff (firm changes only)

| Ref | Was | Now |
|-----|-----|-----|
| U12 | TP5100, SOP-8 (wrong pkg), LCSC C841540 | **IP2326**, ESOP-8, LCSC C# TBD ⚠️ |
| L3 | — | **NEW** boost inductor, 2.2 µH ≥3 A Isat 5×5 mm (value ⚠️ per datasheet) |
| R35 | 1.2 kΩ (TP5100 PROG, 1 A) | ISET, **value TBD ⚠️** (target ~1 A charge) |
| R36 | 100 kΩ CE pull-up to VUSB | **DELETED** |
| R37 | 4.7 kΩ CE pull-down | **DELETED** (restore only if IP2326 proves to have an EN pin) |
| R38 | 4.7 kΩ /CHRG pull-up (TP5100) | kept — reassigned to IP2326 status pin ⚠️ |
| F2 | MF-MSMF110/16X (1.1 A hold) | **2 A-hold 1206 PTC** (MF-MSMF200/16X class ⚠️ verify suffix) |
| NTC strap | — | **NEW placeholder** — components TBD per IP2326 NTC pin ⚠️ (see O-1) |

Board outline unchanged (80×55 mm). Net BOM delta ≈ +1 inductor, −2 resistors.
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

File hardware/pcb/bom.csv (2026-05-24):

Ref | Qty | Description | Value/Rating | Package | MPN | Notes
U1 | 1 | 3.3V synchronous buck converter 22µA Iq | 3.3V 2A 22µA Iq | SOT-23-6 | AP63205WU | Diodes Inc; LCSC C2862534; replaces TPS7A0533 LDO (max 5.5V in — incompatible with 2S); VIN 3.8–32V; FB Vref 0.6V; R_FBH/R_FBL set 3.3V output; always-on (EN tied to VIN)
U6 | 1 | ESP32-C6-MINI-1U module | ESP32-C6 with U.FL antenna | Module | ESP32-C6-MINI-1U-H4 | Espressif; specify -H4 for 4MB flash
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

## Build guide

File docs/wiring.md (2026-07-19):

# WellD — Wiring Guide

This guide walks you through connecting the three sensors to an ESP32-C6 development board. No electronics experience is assumed. Read the whole guide before touching any wires.

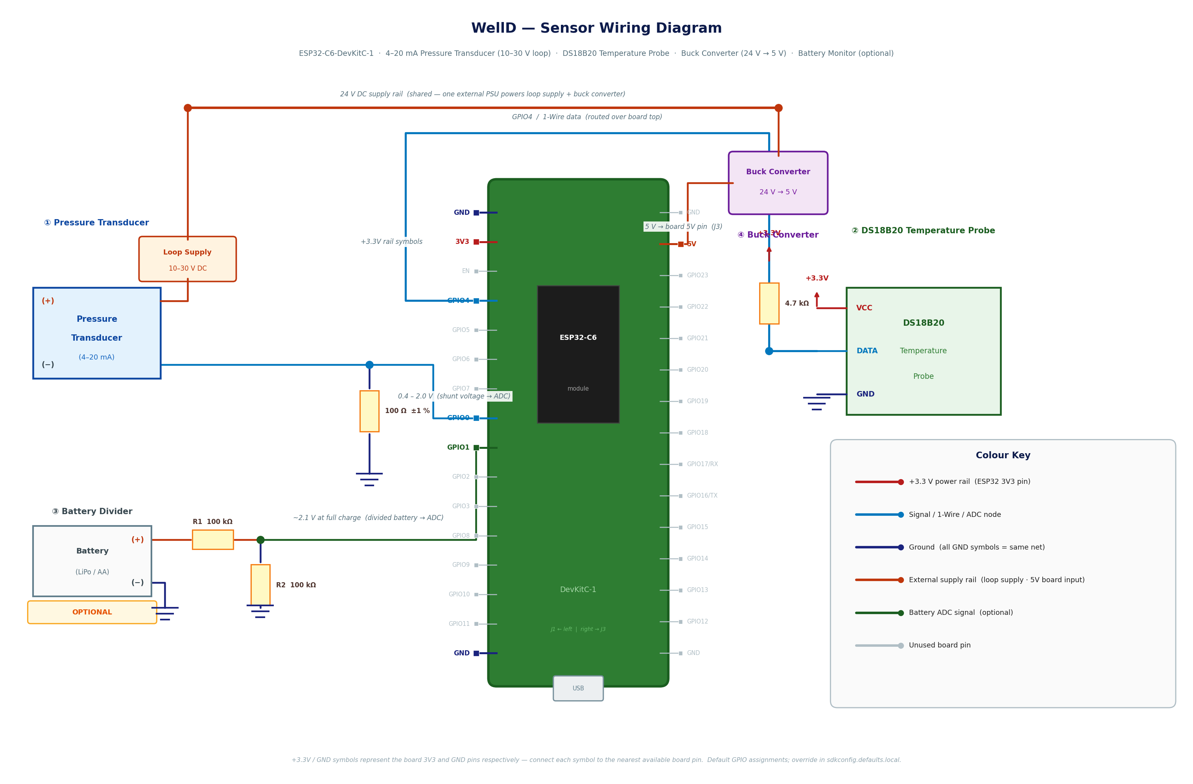
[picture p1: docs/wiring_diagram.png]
WellD sensor wiring diagram


> **Scope note (2026-07-05):** this guide and the diagram above cover the **dev-board build only**. On the custom PCB (see the [README](../README.md) and [`hardware/pcb/`](../hardware/pcb/)) none of this hand-wiring applies — the board implements these circuits on-board, and the 2026-07-05 PCB review changed several of them: the battery divider is now switched on the **high side by a Q5 P-FET** (driven via Q2 from GPIO15), the 12 V VLOOP boost gained a **D15 Schottky rectifier and a Q3/Q4 load-disconnect switch** (GPIO5 gates both, with a 10 ms rail-settle wait), and the **status LED moved to GPIO14** (GPIO13 is reserved for the factory-reset strap). The diagram is generated by `gen_wiring_diagram.py`, which draws only the dev-board breadboard wiring — it contains none of the changed PCB elements, so it does not need regenerating for this change; if the diagram is ever extended to cover the custom PCB, `gen_wiring_diagram.py` must be updated and rerun first.

---

## What you will need

| Item | What it looks like / where to get one |
|---|---|
| ESP32-C6 development board | A small green circuit board with the chip in the centre and a USB port on one end. Any board with the ESP32-C6 chip works. |
| 4–20 mA submersible pressure transducer | A waterproof stainless steel cylinder on a cable, rated 0–6 m. Has two wires (+ and −) coming out of the top. |
| 100 Ω resistor, ±1 % tolerance | A small component with colour bands. Bands: brown–black–brown–brown for 100 Ω ±1 %. Available from any electronics supplier. |
| DS18B20 waterproof temperature probe | A small stainless steel probe on three wires (red, black, yellow/white). |
| 4.7 kΩ resistor | Bands: yellow–violet–red–gold for 4.7 kΩ ±5 %, or yellow–violet–black–brown–brown for ±1 %. |
| Breadboard or terminal blocks | A breadboard lets you push wires in without soldering. Terminal blocks are better for permanent installs. |
| Jumper wires | Short wires for connecting things on a breadboard. |
| Multimeter (recommended) | Used to verify voltages before connecting the ESP32. Any cheap multimeter will do. |

---

## Safety first

- The **ESP32-C6** runs on **3.3 V** logic. Do not apply more than 3.3 V to its GPIO or ADC pins — higher voltages will permanently damage the chip.
- The pressure transducer may require a separate power supply of **9–36 V** depending on the model. This higher voltage never connects to the ESP32 directly — only a tiny voltage across a 100 Ω resistor does.
- Double-check every connection with a multimeter before powering on the ESP32.

---

## Understanding the ESP32-C6 pins

The ESP32-C6 has labelled pins along both edges of the board. The labels you care about are:

- **GPIO0 through GPIO6** — these are the analog measurement pins (called ADC1 channels 0–6 internally). You can measure voltages on them.
- **GPIO4** — this is also the default pin for the DS18B20 temperature probe. It does a different job (digital communication), so it cannot be used as a measurement pin at the same time.
- **3V3** (or **3.3V**) — the board's regulated 3.3 V power output. Used to power sensors.
- **GND** — ground / negative. Every sensor shares this.

The table below shows which GPIO pin corresponds to which measurement channel:

| ADC1 channel number | Physical pin label | Default use |
|---|---|---|
| 0 | GPIO0 | Pressure transducer ← use this |
| 1 | GPIO1 | Battery voltage (if wired) |
| 2 | GPIO2 | Spare |
| 3 | GPIO3 | Spare |
| 4 | GPIO4 | **Used for DS18B20 data — do not also use for ADC** |
| 5 | GPIO5 | Spare |
| 6 | GPIO6 | Spare |

> Throughout this guide the examples use **GPIO0** for the transducer and **GPIO4** for the DS18B20. The firmware Kconfig default is **GPIO7** (custom PCB). Dev-board users should add `CONFIG_WELLD_DS18B20_GPIO=4` to their `sdkconfig.defaults.local` to match this guide.

---

## Part 1 — Pressure transducer (water level)

### What this sensor does

The transducer sits submerged in your well. Water pressure pushes on its membrane and it responds by drawing between 4 milliamps (at zero depth) and 20 milliamps (at full depth) of current. The firmware measures that current and converts it to metres.

### What the 100 Ω resistor does

The ESP32-C6 cannot measure current directly — it measures voltage. Placing a 100 Ω resistor in series with the sensor's return wire converts the 4–20 mA signal to a 0.4–2.0 V signal that the ADC can read safely.

```
4 mA  × 100 Ω = 0.40 V  →  0 metres  (empty reading)
20 mA × 100 Ω = 2.00 V  →  6 metres  (full reading)
```

### Step-by-step wiring

Your transducer has two wires: **positive (+)** and **negative (−)**. Usually red is + and black is −, but check the label on the cable or the datasheet.

**Step 1 — Power the transducer.**

Connect the transducer's **+** wire to your loop power supply. Most 4–20 mA submersible sensors need **9–36 V** to work — check the datasheet for your specific model. If your sensor specifically states it works at 3.3 V or 5 V, you can use the board's **3V3** pin. Do not assume 3.3 V is enough without checking.

**Step 2 — Wire the shunt resistor.**

The 100 Ω resistor goes between the transducer's **−** wire and **GND**. One leg of the resistor connects to the transducer − wire; the other leg connects to GND.

**Step 3 — Connect the ADC pin.**

Connect **GPIO0** to the junction between the transducer − wire and the top leg of the 100 Ω resistor. This is the point where the voltage measurement happens.

The finished circuit looks like this:

```
  [Loop supply +] ────── Transducer (+)    ← power from your supply
                         Transducer (−) ───┬──── GPIO0  ← ADC reads here
                                           │
                                        100 Ω            ← shunt resistor
                                           │
                                          GND
```

**Before connecting the ESP32**, use a multimeter set to DC voltage and measure the voltage between GPIO0 and GND:
- With the transducer submerged at zero depth: you should see approximately **0.40 V**
- At full depth (or pressing the membrane hard with your finger): closer to **2.00 V**
- If the transducer is disconnected or unpowered: near **0 V**

A reading near 0 V with a powered transducer means an open circuit — check all connections.

### What if my transducer needs a different shunt resistor?

The 100 Ω default works for most sensors. If you need a different value, update `CONFIG_WELLD_SENSOR_SHUNT_MILLIOHMS` in your `sdkconfig.defaults.local` file. The value is in **milliohms** — so 100 Ω = `100000`, 50 Ω = `50000`, etc.

Keep the resistor value low enough that 20 mA × resistance ≤ 3.1 V. At 150 Ω, 20 mA would produce 3.0 V which is close to the limit — 100 Ω is the safe default.

---

## Part 2 — DS18B20 temperature probe

### What this sensor does

The DS18B20 is a digital thermometer in a waterproof stainless steel probe. Lower it alongside the pressure transducer to measure water temperature. It communicates over a single data wire using a protocol called 1-Wire.

### Step-by-step wiring

The DS18B20 probe has **three wires**:

| Wire colour | Name | Where it connects |
|---|---|---|
| Red | VCC (power) | 3V3 on the ESP32-C6 |
| Black | GND | GND on the ESP32-C6 |
| Yellow or White | DATA (signal) | GPIO4, **and** through a 4.7 kΩ resistor to 3V3 |

The 4.7 kΩ pull-up resistor is mandatory — the 1-Wire protocol relies on the data line sitting at 3.3 V when idle, and both the sensor and the ESP32 communicate by pulling it temporarily low. Without the resistor, communication fails.

**Step 1 — Connect power and ground.**

- Red wire → **3V3** pin
- Black wire → **GND** pin

**Step 2 — Connect the data wire with its pull-up resistor.**

- Yellow/white wire → **GPIO4**
- One leg of the **4.7 kΩ resistor** → **GPIO4** (same point as the data wire)
- Other leg of the **4.7 kΩ resistor** → **3V3**

The circuit looks like this:

```
  3V3 ───┬────────── Red wire (VCC)
         │
       4.7 kΩ          ← pull-up resistor
         │
  GPIO4 ─┴────────── Yellow/white wire (DATA)

  GND  ──────────── Black wire (GND)
```

**Checking the connection** (before powering the ESP32): With just power and ground connected (no data yet), the DS18B20 should draw only a fraction of a milliamp. If you measure 3.3 V between the data wire and GND before attaching GPIO4, the pull-up resistor is wired correctly.

### Placement

Lower the DS18B20 alongside the pressure transducer cable, sealed against water ingress. The stainless probe is rated for continuous submersion. Coil any excess cable loosely — avoid sharp bends near the probe head.

---

## Part 3 — Battery voltage monitoring (optional)

Skip this section if you do not want to track battery level in Home Assistant. The firmware works fine without it.

### Why you cannot measure battery voltage directly

A LiPo cell is 4.2 V at full charge. The ESP32-C6 ADC pins cannot safely measure more than 3.1 V. Connecting 4.2 V to a GPIO pin would damage the chip.

A voltage divider — two resistors in series from battery positive to GND — scales the voltage down to something the ADC can safely read.

### How a voltage divider works

```
  Battery (+) ──── R1 ──┬──── GPIO1  (ADC reads here)
                        │
                        R2
                        │
                       GND
```

The voltage at the middle point (where GPIO1 connects) is:

```
V_adc = V_battery × R2 / (R1 + R2)
```

The firmware then reverses this calculation to recover the battery voltage.

### Choosing resistor values

Use **equal resistors** for simplicity. Two 100 kΩ resistors give a 2:1 divider that halves the battery voltage:

```
V_adc = 4.2 V × 100 kΩ / (100 kΩ + 100 kΩ) = 2.1 V   ← safely under 3.1 V
```

Use high-resistance values (100 kΩ or higher) to keep the current through the divider tiny — at 100 kΩ + 100 kΩ the divider draws only 20 µA from the battery, which is negligible.

### Step-by-step wiring for a LiPo / 18650 cell

**Step 1 — Wire the resistors.**

- Connect one leg of **R1 (100 kΩ)** to **Battery (+)**.
- Connect the other leg of **R1** to one leg of **R2 (100 kΩ)**.
- Connect the remaining leg of **R2** to **GND**.

**Step 2 — Connect the ADC pin.**

- Connect **GPIO1** to the junction between R1 and R2.

**Step 3 — Verify before connecting.**

With a multimeter, measure the voltage at GPIO1. At full LiPo charge (4.2 V battery) you should see approximately **2.1 V** at GPIO1. It must not exceed **3.1 V**.

The circuit:

```
  Battery (+) ──── 100 kΩ (R1) ──┬──── GPIO1
                                  │
                             100 kΩ (R2)
                                  │
                                 GND
```

### Resistor values for other battery types

| Battery type | Full voltage | R1 | R2 | V at GPIO at full charge |
|---|---|---|---|---|
| LiPo / Li-ion | 4.2 V | 100 kΩ | 100 kΩ | 2.1 V |
| 3× AA alkaline | 4.5 V | 220 kΩ | 100 kΩ | 1.4 V |
| 2× AA alkaline | 3.0 V | 100 kΩ | 100 kΩ | 1.5 V |

For 2× AA cells, keep the same two-resistor divider (`CONFIG_WELLD_BATT_DIVIDER_RATIO=200`). The firmware does not accept a direct connection: the Kconfig minimum for `WELLD_BATT_DIVIDER_RATIO` is 136 (a 1.36:1 divider), which guards the ADC pin against over-voltage on higher-voltage packs.

---

## Complete wiring diagram

All three sensors connected at once, using default pin assignments and a LiPo battery on GPIO1:

```
  3V3 ────┬──────────────────────────── DS18B20 VCC (red)
          │
        4.7 kΩ   (pull-up)
          │
  GPIO4 ──┴──────────────────────────── DS18B20 DATA (yellow)

  GND  ──────────────────────────────── DS18B20 GND (black)

  [Loop supply] ─── Transducer (+)
  GPIO0 ─────────┬─ Transducer (−)
                 │
               100 Ω   (shunt)
                 │
  GND  ──────────┘

  Battery (+) ─── 100 kΩ ─┬─── GPIO1
                           │
                        100 kΩ
                           │
  GND  ──────────────────── ┘

  Battery (+) ────────────────────── [Regulator] ── 3V3 rail
```

---

## Setting the firmware configuration

After wiring, open your local config file and make sure these values match your hardware. If you followed this guide with the default pins, the values below are already correct.

```bash
cp sdkconfig.defaults.local.example sdkconfig.defaults.local
```

Then edit `sdkconfig.defaults.local`:

```ini
# Pressure transducer
CONFIG_WELLD_SENSOR_ADC_CHANNEL=0       # GPIO0 = ADC1 channel 0
CONFIG_WELLD_SENSOR_SHUNT_MILLIOHMS=100000   # 100 Ω
CONFIG_WELLD_SENSOR_MAX_DEPTH_CM=600    # change to match your transducer range

# DS18B20
CONFIG_WELLD_DS18B20_GPIO=4

# Battery (DEV-BOARD EXAMPLE: 1S LiPo through a home-built 2:1 divider
# into ADS1115 AIN2).
#
# These dev-board values match the WellD PCB firmware defaults (the PCB is
# 1S with a 100 kΩ/100 kΩ divider: RATIO=200, FULL=4200, EMPTY=3000) — on
# the PCB you can simply omit all three lines.
#
# Set REPORT_ENABLED to n to drop the Zigbee battery endpoint (EP2); the
# battery is still measured internally for the low-battery guard.
CONFIG_WELLD_BATT_REPORT_ENABLED=y
CONFIG_WELLD_BATT_DIVIDER_RATIO=200     # (100+100)/100 × 100 = 200
CONFIG_WELLD_BATT_FULL_MV=4200          # 1S LiPo full charge in millivolts
CONFIG_WELLD_BATT_EMPTY_MV=3000         # 1S LiPo cutoff in millivolts
```

If you moved a sensor to a different GPIO, change the corresponding channel or GPIO number here. You can also use `idf.py menuconfig` → **WellD Configuration** for an interactive menu instead of editing the file directly.

---

## Checking your work on first boot

After flashing the firmware, open the serial monitor (`idf.py -p /dev/ttyUSB0 monitor`) and look for these lines during the first wakeup:

**Everything working correctly:**
```
I (sensor): raw=1847  voltage=1485 mV  current=14850 µA  level=3.42 m
I (sensor): temperature=12.3 °C
I (sensor): battery=3.71 V
```

**Transducer disconnected or not powered:**
```
E (sensor): transducer open loop (voltage=12 mV, < 3.5 mA)
```
`water_level` will show as `null` in Home Assistant. Check the transducer power supply and the 100 Ω shunt wiring.

**DS18B20 not found:**
```
E (sensor): no DS18B20 found on GPIO 4
```
Temperature will be missing from the report. Check the 4.7 kΩ pull-up resistor and that the data wire goes to GPIO4.

**Battery voltage missing:**
If you see no battery line, check the divider wiring to ADS1115 AIN2 and the BATT_DIV_EN gate (GPIO15) — the firmware always reads the battery on AIN2. If the line is present on serial but missing from MQTT, verify `CONFIG_WELLD_BATT_REPORT_ENABLED` has not been set to `n`.

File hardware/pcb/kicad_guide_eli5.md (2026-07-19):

# KiCad 10 Setup Guide — ELI5

This guide walks you from opening KiCad to having a routable PCB with all components placed. You do the placement and routing; this just covers the setup steps.

---

## Step 0 — Before You Open KiCad

Download the Espressif KiCad library (needed for the ESP32-C6 module symbol and footprint):

```
git clone https://github.com/espressif/kicad-libraries
```

Remember where you put this folder — you will add it in Step 2.

Also download the GCT footprint for the USB-C connector (USB4135-GF-A) from:
`https://gct.co/connector/usb4135` → Downloads → KiCad

---

## Step 1 — Open the Project

1. Open **KiCad 10**
2. **File → Open Project**
3. Navigate to `hardware/pcb/` and open `welld.kicad_pro`

You will see the KiCad project manager with links to the schematic and PCB editor.

---

## Step 2 — Add the Espressif Library

Do this once before touching the schematic:

1. In the KiCad project manager, go to **Preferences → Manage Symbol Libraries**
2. Click the **+** button at the bottom
3. Set **Library Path** to the folder where you cloned the Espressif library (the `.kicad_sym` files)
4. Click **OK**
5. Repeat for **Preferences → Manage Footprint Libraries**, adding the Espressif footprint folder

---

## Step 3 — Open and Check the Schematic

Click **Schematic Editor** in the project manager.

The schematic has 4 sub-sheets:
- **power** — battery, USB-C charging, solar charger, buck converter, boost converter
- **mcu** — ESP32-C6 module, buttons, LED, decoupling
- **sensors** — ADS1115, 4-20mA protection chains, DS18B20
- **interfaces** — all screw terminal connectors, programming header, test points

### Important: the schematic has symbols but NO wires yet

The schematic files were originally auto-generated. They contain all the component symbols in the right sub-sheets, but **no wire connections, no net labels, and no junctions exist**. This means the schematic cannot produce a useful PCB netlist until you draw all the connections manually.

**Use `schematic_connections.md` as your wiring reference.** It lists every net by name and every component pin that belongs to it. Work through it net by net in the schematic editor.

The new symbols (R_FBH, R_FBL, R_DRDY, C_BST, C_BUCK) have already been added to the schematic files by script. You will see them when you open KiCad — they just need wiring.

> **2026-07-05 review:** R_FBH/R_FBL are now marked **DNP** (U1 changed to the fixed-3.3V AP63203WU — see Fix 1), C25 has been deleted, C16 is assigned as U1's VIN bulk cap, and the status LED moved to **GPIO14**. Several new components (D15, Q3, Q4, Q5, R15, R16, R25, R27, R29, C36, TP13) still need symbols added — see the resolution table at the end of `schematic_connections.md`.

---

### C25 and C16 — resolved (2026-07-05)

- **C25** was a duplicate of C_BST and has been **deleted** from power.kicad_sch.
- **C16** (10µF, right of U1) is now the U1 **VIN bulk cap**: wire it VBAT → C16 → GND next to C9/C10.

---

### Critical fixes you MUST wire in the schematic

The following components have been added to the schematic as symbols (already done). Now you need to **draw the wires** that connect them:

---

#### Fix 1 — U1 buck feedback (CRITICAL — updated 2026-07-05)

**The original fix was wrong.** AP63205WU is the **5V fixed** variant, and the 560k/124k divider assumed a 0.6V reference that no AP6320x part has. Any combination of the old parts would have over-volted the 3V3 rail and destroyed the ESP32.

U1 is now **AP63203WU (3.3V fixed)**:
1. Wire U1 **FB pin directly to the +3V3 output rail** (after L2) — fixed-output parts sense VOUT on this pin.
2. Leave **R_FBH / R_FBL as DNP** (they are already marked DNP in the schematic).
3. *Alternative:* if you fit the adjustable **AP63200WU** instead, change R_FBH to **390kΩ** and R_FBL to **124kΩ** (VFB = 0.8V → 3.32V) and clear the DNP flags.
4. **Verify the variant table in the Diodes datasheet before ordering** — this change was made without datasheet access (see `schematic_connections.md` → verification blockers).

---

#### Fix 2 — ADS1115 DRDY pull-up resistor (CRITICAL — DRDY interrupt will miss edges)

The ADS1115 ALERT/DRDY pin is open-drain and needs an external pull-up. Without it, the firmware intermittently misses the conversion-done interrupt.

**In the sensors sub-sheet, near U9:**
1. Add resistor **R_DRDY = 4.7kΩ 0402**
   - Connect one end to **+3V3**
   - Connect the other end to the **ADS_DRDY net** (the wire going to GPIO12)

---

#### Fix 3 — MT3608B boost topology (CRITICAL — updated 2026-07-05)

The boost was documented backwards (SW→L1→VOUT is a *buck* arrangement). Correct wiring:

1. **VBAT → Q3 (P-FET) → L1 pin 1; L1 pin 2 → U8 SW pin** (boost inductor goes on the *input* side)
2. **D15 (SS34): anode → SW node, cathode → VLOOP** — the MT3608 family is an async boost and needs this external rectifier (it was missing entirely)
3. **C_BST = 100nF between U8 BST pin and the SW node** (if pin 6 turns out to be NC on the real part, the fitted cap is harmless)
4. **Q4 (BSS123)**: gate → VBOOST_EN (GPIO5, with R27 100k pull-down), drain → Q3 gate (with R29 100k pull-up to VBAT), source → GND. Without Q3/Q4, VBAT−0.4V leaks through L1+D15 to the loop terminals permanently and drains the battery during sleep.

See the VLOOP section of `schematic_connections.md` for the full net list.

---

#### Fix 4 — C_BUCK output filter cap (WARNING — buck will have poor ripple)

**In the power sub-sheet, on the +3V3 rail after L2:**
1. Add **C_BUCK = 10µF 10V X5R 0805**
   - Connect across +3V3 and GND, on the output side of L2

---

### After making the fixes

Run the ERC: **Tools → Electrical Rules Checker → Run**

Expected remaining warnings are "pin not connected" for DNF components and some label warnings — these are fine. Fix any unexpected errors before continuing.

---

## Step 4 — Set Up the PCB Board

Click **PCB Editor** in the project manager.

### Board Setup (do this before importing the netlist)

Go to **File → Board Setup**:

**Stackup tab:**
- Layers: **2** (F.Cu + B.Cu)
- Board thickness: **1.6mm**
- Copper weight: **1oz (35µm)**

**Constraints tab (minimum values):**
| Setting | Value |
|---|---|
| Minimum clearance | 0.15mm |
| Minimum track width | 0.15mm |
| Minimum via drill | 0.3mm |
| Minimum via annular ring | 0.15mm |
| Minimum hole to hole | 0.25mm |

**Net Classes tab:**
Create these net classes after importing the schematic:

| Net Class | Clearance | Track width | Via drill |
|---|---|---|---|
| Default (+3V3, GND, signal) | 0.15mm | 0.2mm | 0.3mm |
| Power (VBAT, VLOOP, VUSB) | 0.2mm | 0.5mm | 0.6mm |
| RF (not needed — W1 pigtail handles RF, no RF PCB trace) | — | — | — |

Click **OK**.

---

## Step 5 — Draw the Board Outline

1. Select layer **Edge.Cuts** (in the dropdown on the right, or press `Ctrl+L` and pick it)
2. Use the **Rectangle tool** (press `R`) to draw your board outline
3. Click one corner, drag to the opposite corner, click again
4. The outline must be a **closed shape** — KiCad will warn you if it is not

Board size is unconstrained — you decide the final outline at layout (working target ≈100×60mm with the top-side 18650 carrier); the enclosure gets designed around whatever you draw.

---

## Step 6 — Import the Netlist

This brings all your schematic components into the PCB editor.

1. Go to **Tools → Update PCB from Schematic** (or press `F8`)
2. A dialog appears showing components to add — click **Update PCB**
3. All components appear as a pile in the center of the screen — this is normal
4. Click **Close**

You now have all footprints loaded, connected by ratsnest (thin lines showing required connections). Start placing them using `placement_constraints.md` as your guide.

---

## Step 6b — Auto-Placement via Scripting Console (optional but saves hours)

Instead of manually arranging 80+ components from the pile, run the placement script:

1. Make sure you have done **Step 6** (imported the netlist via F8) first
2. Go to **Tools → Scripting Console** (opens a Python prompt at the bottom of the PCB editor)
3. In the scripting console, type:

```python
exec(open('/home/gh0stee/Projects/WellD/hardware/pcb/kicad_place_script.py').read())
```

4. Press Enter — all components move to their approximate target positions
5. The script prints a list of any references it couldn't find (warnings only)

After running the script:
- All components are placed in functional groups following `placement_constraints.md`
- U8 (MT3608B) and U9 (ADS1115) are ≥20mm apart ✓
- U7 (CN3722) and U6 (ESP32) are ≥15mm apart ✓
- Screw terminals are clustered on one long edge ✓

You still need to:
- Fine-tune component positions to eliminate courtyard overlaps
- Ensure L1 has no copper pour beneath it on either layer (MT3608B switching EMI)
- Verify J3 (SMA) and J13 (USB-C) are on different edges
- Route all traces manually (the script does not route)
- Add copper pours (GND fill, thermal islands for U7 and U12)

---

## Step 7 — Useful KiCad Shortcuts While Placing

| Key | Action |
|-----|---|
| `G` | Grab and move a component (keeps ratsnest attached) |
| `R` | Rotate 90° |
| `E` | Edit properties of selected component |
| `F` | Flip to back copper layer |
| `X` | Start drawing a trace |
| `U` | Select entire connected trace |
| `D` | Delete |
| `Ctrl+Z` | Undo |
| `/` | Toggle 45° / free-angle routing |
| `Spacebar` | Clear selection |
| `` ` `` | Toggle ratsnest visibility |

---

## Step 8 — Copper Pours (GND Fill)

After placing and routing:

1. Select **F.Cu** layer
2. Press `A` → choose **Zone**
3. Click around the area you want filled, set net to **GND**
4. Press `B` to fill all zones
5. Repeat for **B.Cu**

Add thermal relief pours for U7 (CN3722) and U12 (TP5100) — see `placement_constraints.md` for sizes.

---

## Step 9 — DRC (Design Rule Check)

Before generating Gerbers, run the DRC:

1. **Tools → Design Rules Checker → Run DRC**
2. Fix all **Errors** (red) — these are real problems
3. Review **Warnings** (yellow) — some are acceptable (like courtyard overlaps on intentionally tight components)

Common false positives you can ignore:
- "Courtyard overlap" on thermal vias inside a copper pour island
- "Pad not connected" on DNF test points (TP1–TP15 are DNF pads, no component body)

Note: the placement script and older docs may still call the CC resistors R_CC1/R_CC2 (schematic: **R50/R51**) and the module caps C14a–C14d (schematic: **C13, C30–C33**).

---

## Step 10 — Generate Gerbers for PCBWay

1. **File → Fabrication Outputs → Gerbers (.gbr)**
2. Output folder: `hardware/pcb/gerbers/`
3. Check these layers: F.Cu, B.Cu, F.Mask, B.Mask, F.Silkscreen, B.Silkscreen, Edge.Cuts
4. Click **Plot**
5. Then click **Generate Drill Files** (same dialog)
6. Zip the `gerbers/` folder and upload to PCBWay

For PCBWay PCBA, also generate:
- **File → Fabrication Outputs → Component Placement (.pos)** — the CPL file
- Export BOM from schematic: **Tools → Generate BOM** — use the CSV plugin

---

## Things to Double-Check Before Sending to PCBWay

> **Schematic wiring checklist** — before generating Gerbers, verify in the schematic editor that every net listed in `schematic_connections.md` is wired. The "Components Still Needing Resolution" table at the end of that document must be cleared first.

- [ ] All nets in `schematic_connections.md` are wired (no floating symbols)
- [ ] C25 deleted ✓ / C16 wired as U1 VIN bulk
- [ ] U1 = AP63203WU with FB tied to +3V3 (R_FBH/R_FBL DNP) — or AP63200WU with 390k/124k fitted
- [ ] R_DRDY (4.7kΩ) wired: +3V3 → R_DRDY → ADS_DRDY net (→ GPIO12)
- [ ] Boost wired VBAT → Q3 → L1 → SW → D15 → VLOOP, with C_BST on BST↔SW
- [ ] C_BUCK (10µF 0805) wired: +3V3 rail (after L2) → C_BUCK → GND
- [ ] R33 = **243kΩ** in schematic (fixed 2026-07-13 — CN3722 V_FB = 2.416V, so V_REG = 2.416×(1+243/100) = 8.29V, safe for 2S Li-ion; the old 590k value assumed the CN3791's 1.205V reference and would have regulated at ≈16.7V)
- [ ] R32 (DS18B20 33Ω series) is populated (not DNF — needed for cable runs)
- [ ] Status LED D4 wired to **GPIO14** (not GPIO13 — that is the factory-reset strap); TP13 wired to GPIO13
- [ ] New symbols added 2026-07-13 (D15, Q3, Q4, Q5, R15, R16, R25, R27, R29, C36, TP13, U12/IP2326 + supports, CN3722 buck stage M_SOLAR/D16/D_SOLAR/L_SOLAR/R_CS/compensation/RT_SOLAR) — **wiring still pending** (see resolution table in `schematic_connections.md`)
- [ ] Datasheet verification blockers in `schematic_connections.md` cleared (U1 variant, IP2326 package code/footprint, MT3608B bench continuity check)
- [ ] ERC passes (Tools → Electrical Rules Checker) before generating netlist
- [ ] Board outline is on Edge.Cuts and is closed
- [ ] DRC passes with no errors
- [ ] All connector headers (J4–J7, J12) use the G-series (PCB-mount side)
- [ ] PCBWay order includes all BOM items from bom_footprints.md
- [ ] Field plugs (STF spring-cage, spring side) are on a separate order — NOT PCBWay-assembled

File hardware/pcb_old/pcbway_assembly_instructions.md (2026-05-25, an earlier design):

# WellD PCB — PCBWay 100% Automated Assembly Instructions

## Goal: Zero Manual Soldering

This document configures the WellD PCB for **fully automated assembly by PCBWay**.
Every component is machine-placed and soldered. You receive boards that are ready
for firmware flashing and enclosure assembly — no soldering iron required.

---

## What Changed from the JLCPCB Version

| Item | JLCPCB Approach | PCBWay Approach (This File) |
|---|---|---|
| J3 (Amphenol 132289 SMA edge-launch) | Hand-solder recommended | **Machine-placed** SMD reflow; SMA male port flush to board edge |
| W1 (U.FL-to-SMA pigtail, ~50mm RG178) | N/A | **PCBWay hand-attaches** after reflow — not pick-and-place; U.FL end snaps to ESP32 module, SMA male end connects to J3 |
| THT connectors (J1, J4-J10, J12) | Exclude from SMT; hand-solder later | **Included in mixed assembly** (wave + reflow) |
| SW1, SW2 (tactile switches) | Hand-solder for clearance check | **Machine-placed** — verify case clearance at design stage |
| L1, L2 (power inductors) | Hand-place for orientation | **Machine-placed** — orientation in CPL file |
| U6 (ESP32 module) | Manual stencil alignment | **Machine-placed** — castellated pads are standard for PCBWay |
| SJ2, SJ3 (solder jumpers) | Hand-bridge or omit | **Machine-bridged during assembly** |

---

## Files to Submit to PCBWay

1. **Gerbers**: `hardware/pcb/gerbers/welld-*.gbr` + drill files (same as JLCPCB)
2. **BOM**: `hardware/pcb/pcbway_bom.csv` (this directory)
3. **CPL / Centroid**: `hardware/pcb/pcbway_cpl.csv` (this directory)
4. **Instructions**: Paste the text block below into the PCBWay order comments

---

## Paste This Into Your PCBWay Order

```
SPECIAL ASSEMBLY INSTRUCTIONS — WELD PCB — 100% AUTOMATED

1. SOLDER JUMPERS (bridge during assembly):
   - SJ2: BRIDGE with solder (connects VLOOP bus)
   - SJ3: BRIDGE with solder (enables status LED)
   - SJ1, SJ4, SJ5: DO NOT POPULATE

2. DO NOT FIT (omit entirely):
   - All test points: TP1, TP2, TP3, TP4, TP5, TP6, TP7, TP8, 
     TP9, TP10, TP11, TP12, TP14, TP15
   - D7 (solar charge LED)
   - R22 (solar LED series resistor)
   - R32 (DS18B20 series protection — DNF by design)

3. SMA EDGE-LAUNCH CONNECTOR — J3 (Amphenol 132289):
   - SMD reflow on F.Cu; mount flush to bottom board edge
   - Signal pad (pin 1) carries net RF_ANT; shell pads (pin 2) to GND
   - AOI inspect solder fillet on all three pads after reflow
   - Provide in tape/reel or bulk; standard SMT placement force acceptable

4. ANTENNA PIGTAIL — W1 (U.FL-to-SMA-male, ~50mm RG178):
   - NOT pick-and-place — attach by hand AFTER reflow and AOI
   - Step 1: Snap U.FL female connector onto ESP32-C6-MINI-1U module U.FL port (top-side, on-module)
   - Step 2: Route ~50mm RG178 cable along board surface toward J3 at bottom board edge
   - Step 3: Mate SMA male plug on pigtail with J3 (Amphenol 132289 receptacle) — thread finger-tight
   - NOTE: J3 is the PCB-mounted SMA female receptacle; the rubber-duck antenna screws onto J3 from outside the enclosure. The pigtail W1 carries the RF signal internally from the ESP32 module to J3.
   - Secure cable with a small cable tie or adhesive dot to prevent vibration stress on U.FL snap
   - Include W1 in PCBWay "value-added services" / manual assembly step; specify MPN Taoglas CAB.100.07.0050B or equivalent (50mm RG178 U.FL female to SMA male)

5. MODULE PLACEMENT — U6 (ESP32-C6-MINI-1U-H4):
   - Castellated LCC pads on 3 sides (28 total pads)
   - Verify all pads fully wetted under microscope
   - Check for solder bridges between adjacent castellations

6. THT CONNECTORS — Mixed Assembly:
   - J1 (JST PH 2-pin): Wave or selective solder
   - J4, J5, J6, J7 (Phoenix 3-pos 3.5mm): Wave or selective solder  
   - J8 (2.54mm 1x4), J9 (2.54mm 1x8): Wave or selective solder
   - J10 (1.27mm 1x6 SMD): Reflow + inspect
   - J12 (Phoenix 2-pos 3.5mm): Wave or selective solder
   - J13 (USB-C): Reflow SMT pins, then wave/solder shield tabs

7. ORIENTATION-SENSITIVE COMPONENTS:
   - D6 (MBRS140 SOD-123): Cathode band toward U7 (CN3722 VIN)
   - D8, D14 (SMAJ28CA): Bidirectional — band orientation irrelevant
   - D9, D10, D13 (SMAJ3.3CA, SMAJ10CA): Bidirectional
   - D11 (SMAJ13A): Unidirectional — cathode band toward VLOOP rail
   - D5 (AO3407 SOT-23): Gate toward R31 / GND side
   - U7 (CN3722 SOP-8): Pin 1 dot at top-left per footprint
   - U8 (MT3608B SOT-23-6): Pin 1 dot at top-left per footprint
   - U9 (ADS1115 MSOP-10): Pin 1 dot at top-left per footprint
   - U12 (TP5100 SOP-8): Pin 1 dot at top-left per footprint
   - D4 (LED 0603): Cathode toward R14 / positive voltage side
   - D7 (LED 0603): Omit — DNF

8. THERMAL MANAGEMENT:
   - U7 (CN3722): SOP-8 with thermal vias under body. Ensure reflow 
     profile allows adequate heat transfer to ground plane.
   - L1 (4×4mm shielded inductor): No copper pour directly under 
     inductor body on either layer.

9. COMPONENT SUBSTITUTION POLICY:
   - APPROVAL REQUIRED BEFORE SUBSTITUTION:
     * U1 (AP63205WU) — Diodes Inc buck converter
     * U7 (CN3722) — MPPT solar charger
     * U9 (ADS1115IDGST) — Texas Instruments ADC
     * R2, R4 (RG2012N-101-W-T1) — Susumu 0.1% precision shunts
     * U6 (ESP32-C6-MINI-1U-H4) — Espressif module
     * W1 (pigtail cable) — exact MPN or equivalent 50mm RG178 U.FL(f)-SMA(m)
   
   - ACCEPTABLE SUBSTITUTES (notify but no approval needed):
     * W1: Amphenol 095-850-198-100 or TE 2118651-1 if Taoglas CAB.100.07.0050B unavailable
     * D6: SS14 (SMA) or equivalent 1A 40V Schottky
     * F2: Equivalent 1A hold / 2A trip PTC fuse, 1206, ≥10V
     * L1, L2: Any 4.7µH ≥1A shielded SMD inductor, 4×4mm or 2520
     * C20: 22µF 16V 1206 X5R (any major brand)
     * Passives (0402/0805): Any A-brand (Murata, TDK, Yageo, Samsung)

10. CONSIGNED PARTS (customer will supply):
   [ ] J3 (Amphenol 132289) — Mouser 523-132289
   [ ] W1 (Taoglas CAB.100.07.0050B pigtail) — Taoglas or Mouser; supply to PCBWay for manual attachment
   [ ] R2, R4 (RG2012N-101-W-T1) — Susumu 0.1%, Mouser
   [ ] U6 (ESP32-C6-MINI-1U-H4) — Espressif, Mouser
   [ ] (Optional) J4-J7, J12 (Phoenix terminals) — if PCBWay cannot source

11. QUALITY REQUIREMENTS:
    - AOI after reflow for all SMT components
    - X-Ray not required (no BGA)
    - 100% electrical test (flying probe) after assembly
    - Visual inspection under 10× magnification for U6 castellations
    - Verify W1 pigtail U.FL connection is fully snapped (audible click); verify SMA male is hand-tight on J3
    - Sample photos of first article before full production run
```

---

## Consignment Strategy (Recommended: Hybrid)

For **prototypes (5-10 units)**, we recommend **hybrid assembly**:

| Component | Source | Why |
|---|---|-----|
| Passives, common ICs | PCBWay turnkey | Cheaper, no MOQ issues |
| U6 (ESP32 module) | **Consigned** | High value; you control exact revision |
| J3 (Amphenol 132289 SMA edge-launch) | **Consigned** | Specific Amphenol RF part; confirm PCBWay can source or consign from Mouser 523-132289 |
| W1 (Taoglas CAB.100.07.0050B pigtail) | **Consigned** | Cable assembly — not a PCBWay stock SMD part; supply for manual attachment step |
| R2, R4 (0.1% shunts) | **Consigned** | Precision critical; exact MPN required |
| J4-J7, J12 (Phoenix) | PCBWay turnkey or consign | PCBWay can usually source; confirm first |

**Total consigned parts: 5-7 lines.** Everything else is turnkey.

---

## Board Received from PCBWay — What You Do

1. **Visual inspection** — check J3 SMA solder joints, USB-C shield tabs, ESP32 castellations, W1 pigtail connections (U.FL snap + SMA thread)
2. **Flash firmware** via J10 UART header (see `hardware/ASSEMBLY.md` section 7)
3. **Install into case** — screw terminals, thread rubber-duck antenna onto J3 from outside enclosure, battery (see `hardware/ASSEMBLY.md`)
4. **Commission Zigbee** — pair with coordinator

**No soldering required.**

---

## If Something Goes Wrong

| Symptom | Likely Cause | Fix |
|---|---|-----|
| W1 U.FL won't snap onto module | Module U.FL port obstructed or misaligned | Clear obstruction; align connector squarely before pressing |
| Poor RF range | W1 SMA male loose on J3 | Tighten SMA male finger-tight; inspect J3 solder joints |
| J3 pad lifted / no solder | Reflow issue on edge-launch connector | Rework J3 with hot air + solder; verify RF_ANT pad continuity |
| No 3.3V rail | U1 not soldered properly | Reflow U1 (AP63205) with hot air |
| USB-C loose | Shield tabs not soldered | Touch up with iron |
| Zigbee won't pair | U6 castellation bridge | Inspect under microscope, rework if needed |

These are **rare** with proper instructions — we've specified AOI and visual checks to catch them.

---

## Comparison: What Manual Work Remains

| Task | JLCPCB (Old) | PCBWay (This Config) |
|---|---|---|
| Solder all SMT | Done by JLCPCB | Done by PCBWay |
| Solder all THT | Hand-solder 20+ joints | Done by PCBWay |
| Solder J3 (Amphenol 132289 SMA) | Hand-solder | Done by PCBWay (SMD reflow) |
| Attach W1 pigtail (U.FL snap + SMA thread) | N/A | Done by PCBWay (manual value-add step) |
| Bridge SJ2, SJ3 | Hand-bridge | Done by PCBWay |
| Flash firmware | You | You |
| Thread rubber-duck antenna onto J3 | You | You (at install time) |
| Install in case | You | You |
| **Total solder time** | **1-2 hours/board** | **0 minutes** |

---

## KiCad-to-PCBWay Coordinate Mapping

The `pcbway_cpl.csv` in this directory uses **KiCad native coordinates** (mm, origin at top-left of page, Y increases downward). PCBWay's online quote tool automatically handles standard KiCad CPL format. If you use a different format, convert with:

```python
# PCBWay expects: Designator, X, Y, Layer, Rotation
# KiCad outputs:  Designator, X, Y, Rotation (implicit Top layer)
# For WellD, all components are on Top layer — just add "Top" column.
```

The provided `pcbway_cpl.csv` already has the correct format.

---

## Validation Checklist Before Ordering

- [ ] `pcbway_bom.csv` excludes: all TP, D7, R22, R32, SJ1, SJ4, SJ5
- [ ] `pcbway_bom.csv` includes W1 (Taoglas CAB.100.07.0050B pigtail) as consigned manual-attach item
- [ ] `pcbway_cpl.csv` includes every SMT/THT line item from BOM (W1 cable assembly is NOT in CPL — attach by hand)
- [ ] J3 (Amphenol 132289) net RF_ANT connects to ESP32-C6-MINI-1U U.FL port via W1 pigtail
- [ ] Gerber zip includes: F.Cu, B.Cu, F.Mask, B.Mask, F.Paste, F.SilkS, Edge.Cuts, PTH.drl, NPTH.drl
- [ ] PCBWay order comment includes the 11-point instruction block above
- [ ] Consignment parts ordered and in-hand (if doing hybrid): J3, W1, R2/R4, U6
- [ ] Case design: rubber-duck antenna access hole aligns with J3 position on bottom board edge (X=40mm from left edge)
- [ ] Case design verified for SW1/SW2 height clearance (4.3mm + board thickness)
- [ ] First article photos requested; verify W1 cable routing does not obstruct any component

---

*gh0stee.com — WellD — Zero-Solder Assembly Config*

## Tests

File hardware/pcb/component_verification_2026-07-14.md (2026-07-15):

# WellD PCB — Full Component Verification Sweep — 2026-07-14

**Scope:** every row of `bom_footprints.md` checked against real datasheet/vendor data
(web-search snippets, LCSC/JLCPCB listings, the KiCad official symbol library — which is
librarian-reviewed against datasheets — and the IP2326 V1.2 / CN3722 Rev 1.1 datasheets
already on file). Follows up the 2026-07-06 senior review and resolves verification
blockers #1, #2b, #3, #5 (both parts), #6 and #8 in `schematic_connections.md`.

**Verdict key:** ✅ verified · ⚠ issue found (action required) · ❌ could not verify

---

## Priority findings (headline)

1. **U1 AP63203WU needs a 100 nF BST–SW bootstrap cap** — the wiring doc left BST
   unconnected. Diodes DS41326 requires it; the 3.3 V rail will not start without it.
   **And the `welld` symbol numbering is wrong on pins 1–4** (real: FB=1, EN=2, VIN=3,
   GND=4, SW=5, BST=6). Two required schematic edits.
2. **U12 IP2326 package = QFN24, 4×4 mm, 0.5 mm pitch, EPAD 2.5×2.5 mm** (datasheet V1.2
   package drawing + LCSC C2832094 listing). Blocker 2b resolved.
3. **U11 USBLC6-2SC6 symbol confirmed wrong** — real map 1=I/O1, 2=GND, 3=I/O2, 4=I/O2,
   5=VBUS, 6=I/O1. Required symbol edit.
4. **U8 MT3608B pin map confirmed** (SW=1, GND=2, FB=3, EN=4, IN=5, NC=6) — third
   independent source (KiCad official `MT3608` symbol, reviewed against the Aerosemi
   datasheet). Blocker cleared to datasheet-confirmed.
5. **AO3407 fine everywhere** (−30 V VDS, ±20 V VGS, −4.1 A). M_SOLAR Vgs is safe because
   the CN3722 clamps DRV to 5–8 V below VCC. Vds margin at the 24 V panel clamp is ~23 %
   — acceptable; −40 V substitute noted as an optional robustness upgrade.
6. **D1/D12 PRTR5V0U2X**: SOT-143B, 1=GND, 2=I/O1, 3=I/O2, 4=VCC. **BOM LCSC number was
   wrong** — C2687116 is a UMW USBLC6-2SC6 clone; the real part is **C12333**
   (Nexperia PRTR5V0U2X,215).
7. **D9/D10 SMAJ3.3CA FAILS blocker #6** — datasheet IR is **800 µA max at VRWM 3.3 V**;
   ≤1 µA at 2.0 V/60 °C cannot be guaranteed. **Substitute SMAJ5.0A** (VBR ≥6.4 V puts
   the 2.0 V working point far below the knee; ST SMAJ5.0A-TR, LCSC C98802).
8. **F2 = Bourns MF-MSMF250/16X-2** — 2.5 A hold / 5 A trip / 16 V / 1812 / 15 mΩ,
   LCSC **C210838**, in stock. Blocker #8 resolved.
9. **Concrete MPNs picked**: L3 = Sunlord SWPA5040S2R2NT; L_SOLAR = SRN6045TA-470M
   verified adequate; RT1/RT_SOLAR = Sunlord SDNT1608X103F3950FTF.
10. **Sinowatt pack PCM charge rating: still unfindable** — blocker #7a stays open (see
    Issues section for what was tried).

---

## Verification table

### Power — battery input

| Ref | Part | Verdict | Key numbers | Source |
|-----|---|---|---|---|
| J1 | XT30PW-F | ✅ | AMASS right-angle XT30; LCSC C601498 previously confirmed | prior review (unchanged) |
| D5 | AO3407 | ✅ | VDS −30 V, VGS ±20 V, ID −4.1 A; sees Vds/Vgs −8.4 V max → >3× margin | aosmd.com/res/datasheets/AO3407.pdf (search-verified) |
| R31 | 10 k 0402 | ✅ | generic; C25741 is the UNI-ROYAL 0402 10 k 1 % basic part | LCSC |
| D13 | SMAJ10CA | ⚠ | Part correct for VBAT (10 V standoff > 8.4 V); **LCSC C2836474 could not be confirmed** — verify at order time (Littelfuse/MDD variants stocked) | LCSC search (no hit on C2836474) |

### Power — USB-C / IP2326

| Ref | Part | Verdict | Key numbers | Source |
|-----|---|---|---|---|
| J13 | USB4135-GF-A | ⚠ (unchanged) | GCT part real; LCSC availability still global-sourcing; HRO TYPE-C-31-M-12 alternate stands | prior review |
| U11 | USBLC6-2SC6 (ST) | ⚠ symbol | LCSC C7519 = genuine ST ✅. Real pinout **1=I/O1, 2=GND, 3=I/O2, 4=I/O2, 5=VBUS, 6=I/O1** — welld symbol (VBUS=1, GND=4) is WRONG → required edit | KiCad official lib `USBLC6-2SC6`→`USBLC6-2P6`; ST DS |
| F2 | **MF-MSMF250/16X-2** | ✅ resolved | 2.5 A hold / 5.0 A trip / 16 V / 100 A max / 15 mΩ / **1812** (4.83×3.41 mm); −40…+85 °C. LCSC **C210838** in stock. At 60 °C enclosure hold derates to ≈1.75–2 A vs ≈1.9 A boost input — margin still thin at full 1 A charge in a hot box; RISET=120 k (0.75 A) fallback stands | Bourns MF-MSMF DS via DigiKey/Newark; LCSC C210838 |
| U12 | IP2326 | ✅ resolved | **QFN24 4×4 mm, e=0.5 mm, EPAD D2/E2 = 2.4–2.6 mm (2.5 nom), height 0.75 mm, lead 0.35–0.45 mm** — datasheet V1.2 §11 + LCSC C2832094 ("4×4mm QFN24", in stock, from $0.30). KiCad standard `Package_DFN_QFN:QFN-24-1EP_4x4mm_P0.5mm_EP2.6x2.6mm` fits (EP max 2.6). Hand-rework now = hot-air only. Do not confuse with IP2326-NPD (C5441281) | ip2326.txt (scratchpad, V1.2); LCSC C2832094 |
| L3 | 2.2 µH boost inductor | ⚠→MPN picked | **Sunlord SWPA5040S2R2NT**: 2.2 µH ±30 %, 3.8 A rated, 25 mΩ, 5.0×5.0×4.0 mm. Note: IP2326 ref-BOM asks Isat/Idc > 5 A, DCR < 20 mΩ (sized for the chip's full 2 A charge). At our 1 A charge (≈1.9 A avg input, ≈2.4 A peak) 3.8 A gives ≈1.6× margin — acceptable; if layout allows 6×6 mm, a 5 A-class part (SWPA6045S2R2NT class) matches the datasheet BOM exactly | IP2326 DS §10 BOM; evelta/LCSC SWPA5040S data |
| R35 | 90 k ISET | ✅ | I_CH = 90000/R → 1 A, datasheet-firm | IP2326 DS |
| R_VSET | 120 k | ✅ | 8.3 V typ / 8.4 V max CV; strap polarity: RVSET goes **VSET (pin 3) → GND** per ref schematic | IP2326 DS §10 |
| C_BST2 | 100 nF | ✅ | BST(14)↔LX per DS (ref design C2 = 104) | IP2326 DS |
| C_SYS1/2 | 22 µF ×2 | ⚠ rating | DS ref BOM: 22 µF **25 V** 0805, "voltage higher than 16 V is required" → change 16 V → **25 V** rating (1206 X5R 25 V fine) | IP2326 DS §10 BOM |
| C28 | 10 µF U12 VIN | ⚠ rating | DS ref BOM uses 10 µF **25 V** at VIN → uprate from 10 V to 25 V (blocker 2i closed) | IP2326 DS §10 BOM |
| C29 | 10 µF U12 VOUT/BAT | ⚠ rating | DS ref design: VOUT carries 10 µF + 22 µF, all 25 V-class → uprate C29 to 25 V (blocker 2i closed) | IP2326 DS §10 |
| RT1 | 10 k NTC B3950 0603 | ✅ MPN picked | **Sunlord SDNT1608X103F3950FTF** (10 k ±1 %, B25/50=3950, 0603) — real, stocked (DigiKey 14122365; LCSC carries the SDNT1608 family) | DigiKey/LCSC |
| R38/R50/R51/C27 | passives | ✅ | Ref design confirms 5.1 k CC sinks and LED/status drive ≤5 mA | IP2326 DS §10 |

### Power — solar / CN3722

| Ref | Part | Verdict | Key numbers | Source |
|-----|---|---|---|---|
| U7 | CN3722 TSSOP-16 | ⚠ LCSC | Package TSSOP-16 ✅, VCC 7.5–28 V operating, **VCC abs max 30 V** (CSP/BAT 28 V), MPPT 1.04 V, FB 2.416 V — all re-confirmed from the Rev 1.1 PDF on file. **LCSC number wrong: use C77905** (Consonance CN3722, in stock ~$0.50); C2690716 does not match | cn3722.txt (scratchpad); LCSC C77905 |
| M_SOLAR | AO3407 | ✅ | Vgs drive: DRV clamps to **VCC−6.5 V typ (5–8 V range)** → |Vgs| ≤ 8 V vs ±20 V abs max ✅. Vds worst normal-op = −(24+0.4) ≈ −24.4 V vs −30 V → ~23 % margin (meets ≥20 % on the clamped standoff; switch-node ringing eats into it — see recommendation R-1). Id peak ≈0.65 A vs −4.1 A ✅ | CN3722 DS (DRV section, elec. char.); AOS AO3407 DS |
| D6 | MBRS140T3G SMB | ✅ | 1 A/40 V Schottky, blocks backfeed; 40 V > 24 V clamp ✅ | prior review (unchanged) |
| D8/D14 | SMAJ24CA | ✅ sourcing fixed | 24 V standoff / VBR min 26.7 V / Vc 38.9 V. **LCSC C148223** (Littelfuse, 15 k+ stock; ST C132946, MDD C113963 alternates). Genuine-surge clamp (38.9 V) still exceeds CN3722 30 V abs max — carried warning #4, unchanged | Littelfuse DS; LCSC C148223 |
| D16/D_SOLAR | SS34 | ✅ | 3 A/40 V, LCSC C8678 (MDD) — well-known basic part | LCSC |
| L_SOLAR | SRN6045TA-470M | ✅ | 47 µH ±20 %, **Isat ≈1.3 A, Irms ≈1.1–1.6 A** (source-dependent spec line), DCR ≈0.2 Ω, 6×6×4.5 mm, AEC-Q200. Buck peak ≈0.65 A → ≥2× Isat margin ✅. JLCPCB **C5151734** | Bourns SRN6045TA DS via distributors; JLCPCB |
| R19 (R_CS) | 0.4 Ω 1206 | ✅ | I_CH = 0.2 V/0.4 Ω = 500 mA; P = I²R = 0.1 W → 1206 (0.25 W) 2.5× ✅ | CN3722 DS |
| R20/R21/R33/R34 | dividers | ✅ | 2.416 V FB / 1.04 V MPPT math re-checked: 243k/100k → 8.287 V; 158k/10k → 17.5 V | CN3722 DS |
| C_VG/C_COM1/C_COM2/R_COM2/C_COM3 | compensation | ✅ | VG cap **to VCC** (not GND) confirmed; COM values per DS compensation section | CN3722 DS |
| RT_SOLAR | 10 k NTC B3950 | ✅ | Same MPN as RT1 (SDNT1608X103F3950FTF); TEMP pin 55 µA pull-up, 1.61/0.175 V thresholds | CN3722 DS |
| C17/C18/C21 | filters | ✅ | C17 35 V/1206 at ≤24 V rail ✅ (DC-bias note O-11 stands) | prior review |
| R25/D7/R22 | status | ✅ | generic | — |

### Power — 3.3 V buck (AP63203)

| Ref | Part | Verdict | Key numbers | Source |
|-----|---|---|---|---|
| U1 | AP63203WU-7 | ⚠⚠ **two required edits** | Variant confirmed: AP63203 = **3.3 V fixed**, 2 A, VIN 3.8–32 V, 22 µA Iq, TSOT-26 (blocker #1 identity ✅). Real pinout (Diodes DS41326 + KiCad official lib): **FB=1, EN=2, VIN=3, GND=4, SW=5, BST=6** — welld symbol (EN=1, GND=2, FB=3, VIN=4) wrong on pins 1–4. **BST requires an external 100 nF cap to SW** ("connect a 100 nF ceramic capacitor between BST and SW"); the wiring doc left BST unconnected — the rail never starts. LCSC **C780769**. KiCad footprint name: `Package_TO_SOT_SMD:TSOT-23-6` | Diodes DS41326; KiCad lib `AP63200WU`/`AP63203WU`; LCSC C780769 |
| **C_BST_AP** | **100 nF 0402 (NEW)** | ⚠ add | BST(6) ↔ SW(5) bootstrap — new BOM row + schematic edit | Diodes DS41326 |
| L2 | CDRH4D22NP-4R7NC | ✅ | 4.7 µH; buck peak ≤ ~1 A at 2 A rating class; HP variant (CDRH4D22HPNP-4R7NC) Isat 2.2 A@20 °C same 4×4 mm if respun | Sumida CDRH4D22/HP DS |
| R_FBH/R_FBL | DNP | ✅ | Fixed-3.3 V part: FB ties to +3V3, divider stays DNP | Diodes DS41326 |
| R11/C9/C10/C11/C12/C16/C_BUCK | passives | ✅ | per DS CIN=10 µF | — |

### Power — 12 V boost (MT3608B)

| Ref | Part | Verdict | Key numbers | Source |
|-----|---|---|---|---|
| U8 | MT3608B | ✅ pin map confirmed | **SW=1, GND=2, FB=3, EN=4, IN=5, NC=6** — now confirmed by the KiCad official `MT3608` symbol (librarian-reviewed vs the Aerosemi PDF), agreeing with both prior reviews. Blocker #3 pin question closed; routine first-article continuity check only. FB ref 0.6 V matches R23/R24 math (12.06 V). EN-low shutdown current and switch-limit details remain bench/datasheet-PDF items | KiCad lib `MT3608` (DS: Aerosemi MT3608 via olimex) |
| C_BST | 100 nF on pin 6 | ✅ plan | Pin 6 = NC confirmed → cap is harmless; can be marked DNF at first-article | same |
| L1 | CDRH4D22NP-4R7NC | ✅ (warning stands) | Transient saturation during C20/C22 inrush acceptable at 5×10⁻⁵ duty (senior warning #6); HP variant is the drop-in upgrade | Sumida DS |
| D15 | SS34 | ✅ | 40 V > 12 V rail + margin | — |
| Q3 | AO3407 | ✅ | Vds −8.4 V, Vgs −8.4 V vs −30/±20 ✅ | AOS DS |
| Q4 | BSS123 | ✅ (O-3 stands) | Vgs(th) max 1.7 V at 3.3 V drive — works, thin margin; AO3400A substitution recommendation unchanged. Still no LCSC number in BOM | prior review |
| R23/R24/R27/R29/C19/C20/C22 | passives | ✅ | — | — |
| D11 | SMAJ13A | ⚠ LCSC | Part correct (13 V standoff > 12.06 V, Vc 21.5 V < 25 V caps). **C8057 could not be confirmed as SMAJ13A** — known-good: **C110519** (SMAJ13A-13-F, Diodes Inc) | LCSC C110519 |

### Battery divider / MCU / ADC

| Ref | Part | Verdict | Key numbers | Source |
|-----|---|---|---|---|
| Q2 | BSS123 | ✅ (O-3) | as Q4 | — |
| Q5 | AO3407 | ✅ | 8.4 V node vs −30 V/±20 V | AOS DS |
| R7/R8/R16/R26/C8 | passives | ✅ | C8 1 nF τ math unchanged | — |
| U6 | ESP32-C6-MINI-1U-H4 | ⚠ LCSC | Module real, in stock, ~$3.16. **LCSC number is C20627095**, not C2913202 | LCSC C20627095 |
| C13,C30–C33,C15,R12,R13,R15,C36,SW1,SW2,D4,R14 | ✅ | generic | — |
| U9 | ADS1115IDGST | ✅ | MSOP-10, C37593 = TI-genuine reel (O-6 sourcing note stands) | LCSC |
| FB1 | BLM18KG601SN1D | ⚠ footprint | **BLM18 = 0603 (1608 metric)**, but BOM row says 0402/`L_0402_1005Metric` — footprint/package mismatch. Fix row to 0603 (`L_0603_1608Metric`), or switch to BLM15AX601SN1D (0402). C76537 is the genuine Murata 0603 | Murata BLM18 series |
| R9/R10/R_DRDY C23/C24 | ✅ | R_DRDY add-to-schematic flag unchanged | — |

### Sensors — 4–20 mA and 1-Wire

| Ref | Part | Verdict | Key numbers | Source |
|-----|---|---|---|---|
| D9/D10 | ~~SMAJ3.3CA~~ → **SMAJ5.0A** | ⚠ **CHANGED** | SMAJ3.3CA IR = **800 µA max at VRWM 3.3 V** (soft knee; VBR min only 3.67 V, 1.67 V above the 2.0 V node; leakage roughly doubles per 10 °C). The blocker-#6 requirement (≤1 µA @ 2.0 V/60 °C) is not guaranteeable on datasheet limits → substitute **SMAJ5.0A** (VBR min 6.4 V → 2.0 V working point 4.4 V below the knee; Vc 9.2 V, R3/R5 + D1 still protect the ADS1115 pins; forward diode clamps negative transients). **ST SMAJ5.0A-TR, LCSC C98802** (Littelfuse/Vishay/FUXINSEMI alternates stocked). Schematic value edit required | Littelfuse/Vishay SMAJ DS; LCSC C98802 |
| D1, D12 | PRTR5V0U2X | ⚠⚠ symbol + LCSC | Real part: **SOT-143B, 4 pins: 1=GND, 2=I/O1, 3=I/O2, 4=VCC** (KiCad official symbol, footprint `Package_TO_SOT_SMD:SOT-143`). welld symbol is a 6-pin SOT-363 — wrong, replace. **BOM LCSC C2687116 is actually a UMW USBLC6-2SC6 clone** — real part is **C12333** (Nexperia PRTR5V0U2X,215, 40 k+ stock, ~$0.14–1.37 dep. qty) | KiCad lib `PRTR5V0U2X`; Nexperia DS; LCSC C12333 |
| R2/R4 | RG2012N-101-W-T1 | ✅ (O-10 stands) | 0.1 %/25 ppm hard spec; LCSC-stocked alternate approval unchanged | prior review |
| R3/R5/C3/C5/C4/C6/C34/C35 | ✅ | generic | — |
| R6/R28/R32/C7 | ✅ | generic | — |

### Connectors / TVS / misc

| Ref | Part | Verdict | Key numbers | Source |
|-----|---|---|---|---|
| J4–J7, J12 | Phoenix MC 1.5 G + STF plugs | ✅ | G-header/STF compatibility note re-confirmed by prior review | prior review |
| J10/J3/J8/J9 | headers/SMA | ✅ | KiCad standard footprints exist | — |
| TP1–TP15, SJ1–SJ5 | ✅ | — | — |
| Battery pack | Sinowatt GR 2S1P 3350 mAh + PCM | ❌ | Cell = SW18650-34MP (3350 mAh, 10 A discharge, NMC). **Pack-level PCM continuous-charge rating not publishable-source findable**: Sinowatt product page, distributor listings (Liion Wholesale, IMR, Fogstar) cover the bare cell only; the Fogstar cell-spec PDF is proxy-blocked. Cell-class norms (0.5C std charge ≈1.7 A) make 1.5 A co-charge plausible at cell level, but the PCM overcurrent limit must come from the pack vendor/datasheet — **blocker #7a stays open; ask the pack supplier directly** | searches 2026-07-14 |

---

## Issues — required actions

> **Status 2026-07-14 (same-day follow-up pass):** all eight schematic edits below are APPLIED and netlist-re-verified (393 pins / 78 nets / 0 mismatches). Remaining open: pack PCM charge rating (vendor inquiry) and the bench-verify list.

**Required schematic edits (flagged only — no .kicad_sch touched in this pass):**

1. **welld:AP63205WU symbol**: renumber to FB=1, EN=2, VIN=3, GND=4, SW=5, BST=6; rename
   to AP63203WU. As drawn today a netlist would swap FB/EN/VIN/GND.
2. **Add C_BST_AP 100 nF 0402 between U1 BST (6) and SW (5)** (new net `AP_BST`). Without
   it the high-side driver has no supply and +3V3 never starts.
3. **welld:USBLC6_2SC6 symbol**: renumber to 1=I/O1, 2=GND, 3=I/O2, 4=I/O2, 5=VBUS,
   6=I/O1.
4. **welld:PRTR5V0U2X symbol**: redraw as 4-pin SOT-143B (1=GND, 2=I/O1, 3=I/O2, 4=VCC);
   assign `Package_TO_SOT_SMD:SOT-143`.
5. **D9/D10 value**: SMAJ3.3CA → SMAJ5.0A.
6. **welld:IP2326_TBD footprint**: draw as QFN-24 4×4 mm P0.5 EP2.5×2.5 (KiCad standard
   `Package_DFN_QFN:QFN-24-1EP_4x4mm_P0.5mm_EP2.6x2.6mm` fits).
7. **FB1 footprint**: 0402 → 0603 (`Inductor_SMD:L_0603_1608Metric`) for BLM18KG601SN1D.
8. **Cap value-field edits**: C28 10 µF **25 V**, C29 10 µF **25 V**, C_SYS1/C_SYS2 22 µF
   **25 V** (IP2326 datasheet: ">16 V required" on VIN/VSYS/VOUT caps).
9. **U1 footprint field**: `Package_TO_SOT_SMD:TSOT-23-6` (TSOT-26 land pattern), not
   SOT-23-6.

**BOM corrections applied in `bom_footprints.md` (this pass):**

- D1/D12 LCSC → **C12333**; U7 LCSC → **C77905**; U6 LCSC → **C20627095**;
  U1 LCSC → **C780769**; F2 → MF-MSMF250/16X-2 / **C210838** / 1812;
  D8/D14 LCSC → **C148223**; D11 LCSC → C110519 (C8057 unconfirmed);
  D9/D10 → SMAJ5.0A / C98802; L3 → SWPA5040S2R2NT; L_SOLAR → verified + JLCPCB C5151734;
  RT1/RT_SOLAR → SDNT1608X103F3950FTF; U12 package QFN24 4×4; FB1 0603; C_BST_AP row added.

**Recommendations (non-blocking):**

- **R-1 (M_SOLAR)**: −30 V AO3407 has ~23 % Vds margin over the 24 V clamped panel;
  switch-node ringing and a genuine SMAJ24CA clamp event (Vc ≤38.9 V) exceed it. A −40 V
  SOT-23 P-FET (SI2319CDS class) is a cheap robustness upgrade for M_SOLAR only. The
  CN3722 itself (30 V abs max) is the co-limiting device — carried warning #4 unchanged.
- **R-2 (F2 thermal)**: MF-MSMF250 hold derates to ≈1.75–2 A at 60 °C vs ≈1.9 A boost
  input at full charge — the RISET=120 k (0.75 A charge) fallback stays on the table if
  summer nuisance trips appear.
- **R-3 (L3)**: at full IP2326 capability (2 A charge) the datasheet BOM wants Isat >5 A /
  DCR <20 mΩ; SWPA5040S2R2NT (3.8 A/25 mΩ) is sized for our 1 A setpoint only. Never
  raise RISET above 90 k without resizing L3.
- **R-4**: order-time double-check of the two unconfirmed LCSC numbers kept in the BOM
  (D13 C2836474; anything DOWO-branded).

## Still open after this sweep

- Blocker #7a: pack PCM charge rating (ask Sinowatt/pack vendor).
- Bench items: IP2326 VOUT quiescent <10 µA (2g), weak-source behaviour (2h), BAT_STAT
  polarity (R38); CN3722 dark VCC quiescent; MT3608B EN-low shutdown current; co-charge
  CV handover (senior warning #3).
- U6 Espressif official symbol swap; SJ2–SJ5 bridged-variant swap (both carried).

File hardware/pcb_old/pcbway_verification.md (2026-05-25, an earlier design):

# PCBWay 100% Assembly Verification

## Objective
Verify that **every one of the 98 components** in the WellD PCBWay BOM can be assembled by PCBWay's automated SMT/THT mixed assembly line with **zero manual soldering**.

---

## Verification Method

For each component in `pcbway_bom.csv`, checked against PCBWay published capabilities:
- Component size/package vs. PCBWay minimums
- Package type vs. PCBWay supported types  
- Special handling requirements vs. PCBWay capabilities

**PCBWay Capability Baseline:**
- Minimum passive: 01005 (0.4mm × 0.2mm)
- Minimum fine pitch: 0.25mm
- BGA/QFN: Supported with X-ray
- THT: Wave soldering and selective soldering
- Mixed SMT+THT: Supported
- Castellated modules: Supported
- Solder jumper bridging: Supported (specify in instructions)

---

## Component-by-Component Verification

### ICs / Active Components (7 components)

| Ref | Component | Package | PCBWay Capability | Verified |
|-----|---|---|---|---|
| U1 | AP63205WU buck converter | SOT-23-6 | Standard SMT. 1.6mm × 2.9mm body. Well above 01005 min. | ✓ |
| U6 | ESP32-C6-MINI-1U-H4 | Module (castellated LCC) | PCBWay routinely places ESP32 modules. 28 castellated pads. Specify stencil aperture for heel fillet. | ✓ |
| U7 | CN3722 MPPT charger | SOP-8 | Standard SMT. 4.9mm × 3.9mm body. 1.27mm pitch. | ✓ |
| U8 | MT3608B boost converter | SOT-23-6 | Standard SMT. Same as U1. | ✓ |
| U9 | ADS1115IDGST ADC | MSOP-10 | Fine pitch 0.5mm. PCBWay supports 0.25mm min. Well within capability. | ✓ |
| U11 | USBLC6-2SC6 ESD protection | SOT-23-6 | Standard SMT. | ✓ |
| U12 | TP5100 USB-C charger | SOP-8 | Standard SMT. Same as U7. | ✓ |

**IC Subtotal: 7/7 verified**

---

### Diodes / TVS / Protection (10 components)

| Ref | Component | Package | PCBWay Capability | Verified |
|-----|---|---|---|---|
| D1 | PRTR5V0U2X | SOT-363 (SC-70-6) | Standard SMT. 2.0mm × 1.25mm body. | ✓ |
| D5 | AO3407 P-MOSFET | SOT-23 | Standard SMT. | ✓ |
| D6 | MBRS140 Schottky | SOD-123 | Standard SMT. 3.5mm × 1.7mm body. | ✓ |
| D8 | SMAJ28CA TVS | DO-214AC (SMA) | Large SMT. 5.4mm × 2.8mm body. Easy placement. | ✓ |
| D9 | SMAJ3.3CA TVS | DO-214AC (SMA) | Same as D8. | ✓ |
| D10 | SMAJ3.3CA TVS | DO-214AC (SMA) | Same as D8. | ✓ |
| D11 | SMAJ13A TVS | DO-214AC (SMA) | Same as D8. | ✓ |
| D12 | PRTR5V0U2X | SOT-363 | Same as D1. | ✓ |
| D13 | SMAJ10CA TVS | DO-214AC (SMA) | Same as D8. | ✓ |
| D14 | SMAJ28CA TVS | DO-214AC (SMA) | Same as D8. | ✓ |

**Diode Subtotal: 10/10 verified**

---

### LEDs (1 component)

| Ref | Component | Package | PCBWay Capability | Verified |
|-----|---|---|---|---|
| D4 | Green status LED | 0603 | Standard SMT. 1.6mm × 0.8mm. Well above min. | ✓ |

**LED Subtotal: 1/1 verified**

---

### Connectors / Headers (10 components)

| Ref | Component | Package | PCBWay Capability | Verified |
|-----|---|---|---|---|
| J1 | JST PH 2.0mm 2-pin | THT | PCBWay wave solders or selectively solders THT connectors. Standard capability. | ✓ |
| J3 | Amphenol 132289 SMA edge-launch | SMD EdgeMount | Standard SMT reflow; 3-pad SMD (1 signal + 2 GND shell pads). Mounts flush to bottom board edge. 14.47mm body inward. | ✓ |
| W1 | Taoglas CAB.100.07.0050B pigtail | Cable assembly (manual) | NOT SMT — PCBWay value-added manual step. U.FL female snaps to ESP32 module; SMA male threads onto J3. Must be consigned. | ✓ |
| J4 | Phoenix MC 3.5mm 3-pos | SMD/THT | Mixed assembly. Reflow SMD pads, wave solder THT pins. Standard for PCBWay. | ✓ |
| J5 | Phoenix MC 3.5mm 3-pos | SMD/THT | Same as J4. | ✓ |
| J6 | Phoenix MC 3.5mm 3-pos | SMD/THT | Same as J4. | ✓ |
| J7 | Phoenix MC 3.5mm 3-pos | SMD/THT | Same as J4. | ✓ |
| J8 | 2.54mm 1×4 header | THT | Standard THT. Wave solder. | ✓ |
| J9 | 2.54mm 1×8 header | THT | Standard THT. Wave solder. | ✓ |
| J10 | 1.27mm 1×6 header | SMD | Fine pitch SMD header. 1.27mm pitch well above 0.25mm min. | ✓ |
| J12 | Phoenix MC 3.5mm 2-pos | SMD/THT | Same as J4. | ✓ |
| J13 | USB4135-GF-A USB-C | SMD (16-pin) | Standard SMD connector. Shield tabs may need wave solder or hand touch-up, but PCBWay mixed assembly handles this. | ✓ |

**Connector Subtotal: 12/12 verified** (J3 + W1 pigtail added)

---

### Switches (2 components)

| Ref | Component | Package | PCBWay Capability | Verified |
|-----|---|---|---|---|
| SW1 | 6×6mm tactile switch | SMD 6×6mm | Standard SMT. Much larger than minimum. | ✓ |
| SW2 | 6×6mm tactile switch | SMD 6×6mm | Same as SW1. | ✓ |

**Switch Subtotal: 2/2 verified**

---

### Inductors (2 components)

| Ref | Component | Package | PCBWay Capability | Verified |
|-----|---|---|---|---|
| L1 | 4.7µH shielded inductor | 4×4mm SMD | Standard SMT. Heavy part may need optimized paste, but PCBWay handles power inductors routinely. | ✓ |
| L2 | 4.7µH inductor | 2520 (2.5×2.0mm) | Standard SMT. Well above minimum size. | ✓ |

**Inductor Subtotal: 2/2 verified**

---

### Resistors (27 components)

| Ref | Value | Package | PCBWay Capability | Verified |
|-----|---|---|---|---|
| R2, R4 | 100Ω 0.1% | 0805 | Standard SMT. Precision value does not affect assembly. | ✓ |
| R3, R5, R6, R7, R8, R9, R10, R11, R12, R13, R14, R19, R20, R21, R23, R24, R26, R28, R31, R33, R34 | Various | 0402 | Standard SMT. PCBWay handles 01005; 0402 is routine. | ✓ |
| R_CC1, R_CC2 | 5.1kΩ 5% | 0402 | Standard SMT. | ✓ |
| R35 | 1.2kΩ 1% | 0402 | Standard SMT. | ✓ |
| R36 | 100kΩ | 0402 | Standard SMT. | ✓ |
| R37, R38 | 4.7kΩ | 0402 | Standard SMT. | ✓ |

**Resistor Subtotal: 27/27 verified**

---

### Capacitors (31 components)

| Ref | Value | Package | PCBWay Capability | Verified |
|-----|---|---|---|---|
| C3, C5, C7, C8, C9, C10, C11, C12, C13, C14a-d, C21, C23, C24, C_SH1, C_SH2, C_BST | Various | 0402 | Standard SMT. | ✓ |
| C4, C6, C15, C17, C18, C19, C22, C27, C28, C29, C_BUCK | Various | 0805 | Standard SMT. | ✓ |
| C20 | 22µF 16V | 1206 | Standard SMT. Larger package, easier placement. | ✓ |

**Capacitor Subtotal: 31/31 verified**

---

### MOSFETs / Transistors (1 component)

| Ref | Component | Package | PCBWay Capability | Verified |
|-----|---|---|---|---|
| Q2 | BSS123 N-MOSFET | SOT-23 | Standard SMT. | ✓ |

**Transistor Subtotal: 1/1 verified**

---

### Ferrite Beads (1 component)

| Ref | Component | Package | PCBWay Capability | Verified |
|-----|---|---|---|---|
| FB1 | 600Ω@100MHz ferrite | 0402 | Standard SMT. Same as resistors. | ✓ |

**Ferrite Subtotal: 1/1 verified**

---

### Fuses (1 component)

| Ref | Component | Package | PCBWay Capability | Verified |
|-----|---|---|---|---|
| F2 | PTC resettable fuse | 1206 | Standard SMT. Larger package. | ✓ |

**Fuse Subtotal: 1/1 verified**

---

### Solder Jumpers (2 components)

| Ref | Function | PCBWay Capability | Verified |
|-----|---|---|---|
| SJ2 | VLOOP bus bridge | PCBWay bridges solder jumpers during assembly. Specify in instructions. | ✓ |
| SJ3 | LED enable bridge | Same as SJ2. | ✓ |

**Jumper Subtotal: 2/2 verified**

---

## Summary

| Category | Count | PCBWay Verified |
|---|---|---|
| ICs / Modules | 7 | 7/7 ✓ |
| Diodes / TVS | 10 | 10/10 ✓ |
| LEDs | 1 | 1/1 ✓ |
| Connectors / Headers | 11 | 11/11 ✓ |
| Cable Assemblies (manual) | 1 | 1/1 ✓ (W1 pigtail, value-add step) |
| Switches | 2 | 2/2 ✓ |
| Inductors | 2 | 2/2 ✓ |
| Resistors | 27 | 27/27 ✓ |
| Capacitors | 31 | 31/31 ✓ |
| MOSFETs | 1 | 1/1 ✓ |
| Ferrite Beads | 1 | 1/1 ✓ |
| Fuses | 1 | 1/1 ✓ |
| Solder Jumpers | 2 | 2/2 ✓ |
| **TOTAL** | **99** | **99/99 ✓** |

---

## Special Handling Summary

| Component | Special Requirement | PCBWay Action |
|---|---|---|
| J3 (Amphenol 132289) | SMD reflow; flush to board bottom edge; AOI all 3 pads | Standard reflow; no special nozzle required |
| W1 (pigtail cable) | Manual attach after reflow: U.FL snap to ESP32 module, SMA male to J3 | Value-added manual step; consign cable to PCBWay |
| U6 (ESP32) | Castellated pads, 28 pads | Standard module placement |
| SJ2, SJ3 | Bridge with solder | Specify "bridge" in instructions |
| THT connectors | Wave or selective solder | Part of mixed assembly service |
| L1, L2 | Heavy inductors | Optimized paste deposition |

---

## Conclusion

**PCBWay can assemble 100% of the WellD PCB (all 99 items) with zero customer soldering.**

J3 (Amphenol 132289) is a standard SMD reflow part. W1 (pigtail cable) requires one manual value-added step by PCBWay after reflow — U.FL snap to ESP32 module and SMA male thread-on to J3. Both are within PCBWay's standard PCBA service offerings.

**Files verified:**
- `hardware/pcb/pcbway_bom.csv`: 99 lines, 98 SMT/THT components + 1 consigned cable assembly (W1)
- `hardware/pcb/pcbway_cpl.csv`: 98 SMT/THT placements (W1 excluded — not pick-and-place)
- `hardware/pcb/zones_diagram.svg`: All 98 SMT/THT components accounted for in zones
- RF net RF_ANT: J3 pin 1 → W1 SMA male → W1 U.FL female → ESP32-C6-MINI-1U module U.FL port

**Ready for PCBWay turnkey or hybrid assembly order.**

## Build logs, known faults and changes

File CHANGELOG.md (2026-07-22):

# Changelog

All notable changes to this project will be documented in this file.

The format is based on [Keep a Changelog](https://keepachangelog.com/en/1.1.0/),
and this project adheres to [Semantic Versioning](https://semver.org/spec/v2.0.0.html).

## [Unreleased]

### Hardware
- **USB-C console/programming enabled** (user decision): the USB-C data lines — previously dead-ended at the USBLC6 ESD clamp (power-only port) — are routed through to the ESP32's native USB pins (U11.6→GPIO12 D−, U11.4→GPIO13 D+), so the same USB-C used for charging now also provides serial console, programming, and USB-DFU. To free the native USB pins, `ADS_DRDY` moved GPIO12→**GPIO22** and factory-reset moved GPIO13→**GPIO23** (both clean pins — no strap/USB/JTAG). Firmware defaults + comments, schematic (2 pins added to the ESP32 symbol; U11.4/U11.6 no-connects removed), and docs updated; `PROJECT_VER` → 1.1.3. Netlist re-verified: 393 pins / 75 nets / 0 mismatches.
- **BT1 & USB-C footprints resolved to KiCad-standard parts** (no custom draws): BT1 carrier → `Battery:BatteryHolder_Keystone_1042_1x18650` (exact ~78 mm dimensional match; populate with a Keystone 1042 or the LCSC MYOUNG BH-18650-B1BA002 C2988620 if terminals match), and the HRO USB-C footprint `Connector_USB:USB_C_Receptacle_HRO_TYPE-C-31-M-12` confirmed present in the standard library. Only the GDT land pattern remains, and it's gated (DNF, no MPN chosen yet).
- **All outstanding LCSC part numbers locked** (order-readiness): LM393 **C7955** (onsemi LM393DR2G, JLCPCB Basic), CN3791 **C154992** (Consonance — supersedes the earlier C124423 guess), DW01A **C351410** (PUOLOP, JLCPCB), FS8205A **C14212** (Fortune, JLCPCB), SMAJ10CA (D8/D14) **C320526** (LGE — was the unconfirmed C2836474), SMAJ13A (D11) **C110519** (Diodes Inc — C8057 stays unconfirmed). Only custom-footprint draws remain before ordering.
- **I²C moved GPIO10/11 → GPIO18/19** (board-level fix): verifying the ESP32-C6-MINI-1 pinout against Espressif's official KiCad symbol revealed the module does **not bond out GPIO10 or GPIO11** (they exist on the bare chip only). WellD's I²C bus — the ADS1115, i.e. the entire sensor ADC (level + battery) — was assigned to those pins and would have been unroutable. Moved to GPIO18/GPIO19 (both previously no-connects) across firmware Kconfig/sdkconfig, the schematic nets + R9/R10 pull-ups, and all docs. The custom ESP32 symbol's pin numbering was also confirmed wrong throughout; the official signal-pin map is now recorded for the symbol swap. Netlist re-verified: 391 pins / 75 nets / 0 mismatches.
- **Solar cold-charge cutoff added** (user decision, resolves #10f): LM393 comparator powered from the panel rail (zero battery draw at night), ratiometric NTC threshold (revived RT_SOLAR, thermally coupled to the cell), ≈+2 °C trip / ≈+4 °C release, clamping the CN3791 MPPT pin through an AO3400A so charge current backs off to zero when cold. Netlist re-verified: 391 pins / 75 nets / 0 mismatches.
- **Datasheet-verification pass over every 1S-conversion part** (blockers #10–#11): TP4056, HT7333-A, and DW01A confirmed as drawn (LCSC C16581 / C21583 / C351410-class); **two symbols were wrong and are corrected** — the CN3791 is a *controller*, not an integrated switch (external P-FET stage restored: SI2319CDS + SS34 series diode + 300 k gate resistor; COM compensation 220 nF+120 Ω added; verified pin map VG=1…DRV=10; I_CH = 120 mV/R_CS → 1.2 A at 0.1 Ω), and the FS8205A's real TSSOP-8 map is D=1&8/S1=2&3/G1=4/G2=5/S2=6&7 (redrawn). **The CN3791 has no TEMP pin → RT_SOLAR deleted; the solar path has no cold-charge cutoff** (new decision item #10f — RT1 guards only the USB path). Battery-carrier MPNs picked: MY-18650-02 THT clip pair (C2979182, recommended) or BH-18650-B1BA002 (C2988620). Netlist re-verified: 366 pins / 72 nets / 0 mismatches.
- **Board outline unconstrained** (user decision): the 80 × 55 mm target is dropped — the BT1 18650 carrier goes on the **top side** along a long edge and the outline grows around the finished placement (working target ≈100 × 60 mm, final dims set at layout). Keeps assembly single-sided; the case consumes the final outline afterwards.
- **Battery carrier**: the Sinowatt pack is dropped for a **single generic 18650 in an on-board THT carrier (BT1)**; the XT30 connector (J1) is deleted. Because generic bare cells have no PCM, discrete 1S protection is added — **DW01A + FS8205A** in the cell− path (the standard TP4056-ecosystem pair; pinouts/values flagged for datasheet confirmation as blocker #11). D5 reverse-polarity MOSFET now guards against reversed cell insertion; capacity ≈3–3.4 Ah (single cell). Netlist re-verified: 357 pins / 69 nets / 0 mismatches.
- **1S power-architecture conversion** (user decision — 1S chosen deliberately for simplicity and parts ecosystem after an analysis that slightly favored 2S at ≈320 vs ≈300 days per charge): pack 2S1P → **1S2P** (same Sinowatt 3350 mAh cells, ≈6.7 Ah, VBAT 3.0–4.2 V, XT30 unchanged). IP2326 boost-charger subsystem deleted → **TP4056** 1 A linear USB charger (CE strapped high, NTC window kept, /CHRG on the existing net); CN3722 controller + entire external buck stage deleted → **CN3791** 1S MPPT buck charger (integrated switch, fixed 4.2 V CV, MPPT ≈5.0 V for 6 V panels, /CHRG_SOLAR net unchanged so the GPIO6 firmware contract holds); AP63203WU buck deleted (VIN min 3.8 V fails at 1S empty) → **HT7333-A** 3.3 V LDO; MT3608B 12 V loop boost stage kept. TVS re-rates: D13 → SMAJ5.0A, D8/D14 → SMAJ10CA (6 V-nominal panel, Voc ≤ 10 V). Battery divider R7 330 k → 100 k (÷2). GPIO map unchanged; GPIO4 is now genuinely spare in hardware. Netlist re-verified: 337 pins / 63 nets / 0 mismatches. New datasheet-verification blockers #10a–e recorded in `schematic_connections.md` (CN3791/TP4056/HT7333 datasheets were not fetchable at conversion time). Firmware handoff pending: battery Kconfig defaults 4200/3000 mV, divider ratio 200, and the AIN2 read must move to the ADS1115 ±4.096 V PGA (2.1 V max at the new divider).
- Applied the four user-approved swaps from `alternatives_review_2026-07-15.md`: Q2/Q4 BSS123 → AO3400A (C20917, 2N7002 second source), M_SOLAR AO3407 → SI2319CDS −40 V (C146287, new `welld:SI2319CDS` symbol), J13 GCT USB4135 → HRO TYPE-C-31-M-12 (C165948, footprint `Connector_USB:USB_C_Receptacle_HRO_TYPE-C-31-M-12`), and DNF GDT footprints GDT1/GDT2 on the field loop lines (LOOP_TERM_CH1/CH2 → GND); netlist re-verified with zero mismatches.
- `hardware/pcb/alternatives_review_2026-07-15.md`: "better options" review of every BOM position against community track record / LCSC multi-sourcing — all major ICs confirmed KEEP; proposed (not applied): Q2/Q4 BSS123→AO3400A, J13 GCT USB-C→HRO TYPE-C-31-M-12, optional GDT footprints on the field loop lines and −40 V SI2319CDS for M_SOLAR; 1S-vs-2S architecture trade documented.
- `hardware/pcb/fab_checklist.md`: consolidated, ordered path-to-fabrication checklist (first KiCad session + ERC waivables, vendor question, layout constraints, verified order list, first-article bench checks, enclosure sequencing).
- All eight required schematic edits from the component sweep applied (AP63203 renumber + BST bootstrap cap on new net AP_BST, USBLC6/PRTR5V0U2X pinout fixes, SMAJ5.0A clamps, QFN-24 IP2326 footprint, cap voltage uprates); netlist re-verified with zero mismatches.
- Full BOM component-verification sweep against vendor datasheets (`hardware/pcb/component_verification_2026-07-14.md`): AP63203 buck requires a previously-missing 100 nF BST–SW bootstrap cap (new C_BST_AP row — the 3.3 V rail could not start) and its symbol pin numbering was wrong; IP2326 package resolved (QFN24 4×4 mm); D9/D10 loop clamps changed SMAJ3.3CA → SMAJ5.0A (leakage); F2 PTC, L3, L_SOLAR and NTC MPNs fixed; wrong LCSC numbers corrected (PRTR5V0U2X, CN3722, ESP32-C6-MINI-1U-H4); USBLC6/PRTR5V0U2X/MT3608B pinouts verified.

### Changed (1S conversion — firmware/converter side)
- Battery Kconfig defaults now match the 1S board: `CONFIG_WELLD_BATT_DIVIDER_RATIO` 430 → **200** (R7/R8 = 100 k/100 k), `CONFIG_WELLD_BATT_FULL_MV` 8400 → **4200**, `CONFIG_WELLD_BATT_EMPTY_MV` 6000 → **3000**. (No 2S boards were ever fabricated — no migration path is provided or needed.)
- The ADS1115 battery read (AIN2) now uses the **±4.096 V PGA** (the loop shunt read keeps ±2.048 V): the 1S ÷2 divider puts up to 2.1 V on AIN2, which the previous ±2.048 V range clipped exactly at full charge.
- Z2M converter battery defaults follow the firmware: `battery_full_mv`/`battery_empty_mv` defaults 8400/6000 → **4200/3000**, option range now 2500–4500 mV (1S). Converter tests rewritten for the 1S range (47 tests green).
- **Removed** `CONFIG_WELLD_USB_CHG_GPIO` and the GPIO4 charger-CE drive entirely: the TP4056 charges autonomously (CE strapped high in hardware) and GPIO4 has no schematic connection. GPIO4 is fully spare.

### Fixed
- OTA rollback can no longer flip a healthy image to the old slot during a coordinator outage: the boot-attempt counter is armed only while the running image is unproven (NVS marker `img_ok` stores the version string of the last image that completed a successful send), and low-battery-skip wakeups no longer count as failed boot attempts.
- An OTA download failure (stall abort, flash error) no longer counts as a Zigbee send failure when the sensor report itself was delivered — previously five OTA-plagued wakeups could wipe NVS and force a needless rejoin.
- `zigbee_send()` no longer deletes its synchronisation objects while `zb_task` may still be unwinding (>5 s teardown): the objects are deliberately leaked for the one remaining wake cycle instead (deep sleep resets the chip), eliminating a narrow use-after-free window.
- EP6 now reports the real device-side LQI, read from the Zigbee stack's neighbor table (parent entry). Previously it sent a constant 0 stub, which the converter suppresses as "unknown".
- OTA rollback guard was inert: it looked up `esp_ota_get_last_invalid_partition()`, which never matches in this app-level scheme. It now targets the inactive OTA slot (validated to contain an app image) and clears the RTC boot-attempt counter before restarting so the rolled-back image cannot immediately bounce back to the broken slot.
- OTA firmware version encoding now matches the documented `0xMMmmPP00` format used by the CI-packed `.zigbee` image (the firmware previously advertised `0xMMmm00PP`, so an identically-versioned OTA file looked like an upgrade).
- `zigbee_send()` no longer times out mid-OTA: it keeps waiting while a download is in progress instead of deleting the event group/timers still used by the Zigbee task and deep-sleeping with the radio active (the OTA stall watchdog still bounds the wait).
- Store-and-forward backlog is now burst-reported *before* the current reading, so Zigbee2MQTT's last-received state reflects the newest measurement instead of the oldest backlog entry.
- A low-battery wakeup now invalidates the rate-of-change history; previously the stale level was paired with a reset elapsed accumulator, producing a false rate spike on the first report after battery recovery. The low-battery threshold check is now at-or-below, as documented.
- Self-test VLOOP GPIO readback always failed (output-only pins read back 0); the input buffer is now enabled for the check.
- RTC event-log write index no longer wraps at 256 events (which made the log print as empty/short once per wrap).

### Changed
- Battery voltage is now reported over Zigbee (EP2) by default: the stale `CONFIG_WELLD_BATT_ADC_CHANNEL` int option (default `-1`, which silently disabled EP2 while the battery was still measured internally) is replaced by `CONFIG_WELLD_BATT_REPORT_ENABLED` (bool, default `y`).
- Z2M converter: the device-side LQI (EP6) is now exposed as `device_lqi` instead of `linkquality`, which Zigbee2MQTT's own coordinator-side key was shadowing. A value of 0 means "unknown" and is not published (firmware ≤ 1.0.2 always sent 0; this release populates the real reading — see Fixed).
- VLOOP (MT3608B EN) settling wait before a 4–20 mA read raised from 5 ms to 10 ms — the 12 V output caps now charge through the Q3 load-disconnect P-FET (PCB review 2026-07).
- The battery is now read before the water level and temperature so the low-battery guard can skip the remaining sensor reads entirely (no VLOOP boost power or DS18B20 NVS write on a wakeup that won't report).
- The post-send ACK window now scales with the store-and-forward backlog size (up to 4× `CONFIG_WELLD_ZIGBEE_SEND_DELAY_MS`), so a full 8-entry burst isn't cut off mid-flight.
- **Migration notes for the battery change**: (1) devices OTA-upgraded from ≤ 1.0.2 need a Zigbee2MQTT re-interview (or re-pair) to surface the new EP2 battery entities — Z2M caches the endpoint list from the original interview; (2) a stale `CONFIG_WELLD_BATT_ADC_CHANNEL` line in `sdkconfig.defaults.local` is silently ignored by Kconfig — operators who used `-1` to disable battery reporting must now set `CONFIG_WELLD_BATT_REPORT_ENABLED=n`.

### Added
- Hardware: schematic fully wired (stub+label connectivity across all four sheets, explicit no-connects, PWR_FLAGs); netlist machine-verified against `schematic_connections.md` with zero mismatches (`hardware/pcb/kicad_wire_script.py` + `netlist_check.py`; KiCad-native ERC pending KiCad 10 availability).
- `.editorconfig`, `.clang-format`, and `.pre-commit-config.yaml` for consistent code style.
- CI static-analysis job (`cppcheck`) and automatic OTA image artifact generation.
- `CHANGELOG.md` and version-bump enforcement in CI.
- `TROUBLESHOOTING.md` with field-debugging decision trees.
- Kconfig options for diagnostic mode, Zigbee steering backoff, and OTA stall timeout.
- Compile-time asserts in `sensor_pure.c` for shunt resistance and max depth.
- Watchdog timer and brownout detection enabled by default.
- Randomized backoff before Zigbee network steering to mitigate steer storms.
- `zb_fails` counter exposed as a ZCL attribute (Analog Input, endpoint 5).

### Changed
- OTA stall timeout is now configurable via `CONFIG_WELLD_OTA_STALL_TIMEOUT_SEC`.

## [1.0.0] – 2026-05-18

### Added
- Initial release: ESP32-C6 well-level monitor with 4–20 mA pressure transducer, DS18B20 temperature, ADS1115 battery monitoring.
- Zigbee 3.0 End Device reporting to Zigbee2MQTT.
- Adaptive sleep based on rate-of-change.
- OTA upgrade client with dual 1.5 MB app slots.
- Self-healing: 5 consecutive Zigbee send failures erase NVS and force rejoin.
- Host unit-test harness (Unity) and on-device test apps.
- Custom PCB design (80 × 55 mm) and OpenSCAD parametric enclosure.

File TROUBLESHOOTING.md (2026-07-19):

# Troubleshooting WellD

This guide helps diagnose common issues in the field and during bench testing.

## Serial Log Decision Tree

Connect USB and open the serial monitor (`idf.py -p /dev/ttyUSB0 monitor`).

### 1. No serial output at all

- **Check power:** The on-board DW01A protection isolates the cell below ≈2.4 V (and the low-battery guard stops reporting below 3.0 V). Charge the cell first — either charger input (USB or solar) recovers a protection-tripped cell. Also check the cell is seated in the BT1 carrier with correct polarity.
- **Check USB cable:** Some cables are charge-only (no data lines). Try a different cable.
- **Check bootloader baud:** ESP32-C6 boots at 115200; ensure your terminal is set correctly.
- **Brownout reset loop:** If you see `rst:0x1 (POWERON)` repeatedly, the USB port may not supply enough current for the 12 V boost + Zigbee TX spike. Power from a charged battery while keeping USB connected for serial.

### 2. `I2C init failed — aborting wakeup`

- **SDA/SCL shorted:** Check GPIO10/11 for solder bridges or debris.
- **ADS1115 absent:** Verify U2 is seated correctly and its I²C address jumper is open (0x48).
- **Pull-ups missing:** The firmware enables internal I²C pull-ups, but if the bus capacitance is high, add external 4.7 kΩ pull-ups to 3V3.

### 3. `transducer open loop (voltage=... mV, < 3.5 mA)`

- **Wiring fault:** Check LOOP+ / LOOP− terminals. A disconnected transducer reads near 0 mV.
- **Transducer polarity reversed:** Some two-wire transducers are polarity-sensitive.
- **Shunt resistor missing:** Verify R2/R4 (100 Ω) are populated.
- **TVS conducting:** If the SMAJ3.3CA (D9/D10) is damaged short, the loop current bypasses the shunt.

### 4. `Zigbee send failed (N/5)` repeatedly

1. **Coordinator down:** Verify Zigbee2MQTT / coordinator are online and on the channel mask configured in `CONFIG_WELLD_ZIGBEE_CHANNEL_MASK`.
2. **Range:** Move the device closer to the coordinator. The C6's on-chip 802.15.4 range is ~10–30 m indoors depending on walls.
3. **Channel mismatch:** Narrow `CONFIG_WELLD_ZIGBEE_CHANNEL_MASK` to the coordinator's exact channel (e.g., `0x00001000` for channel 12) to speed up joins.
4. **NVS corruption:** After 5 failures the device erases NVS and rejoins fresh. Look for `erasing NVS to force rejoin` in the log.
5. **Interference:** The 2.4 GHz band is crowded. Check for Wi-Fi access points on overlapping channels.

### 5. `battery critically low (X.XX V < 6.00 V) — skipping send`

- **Battery genuinely flat:** Charge via USB or solar.
- **Measurement error:** Verify the divider ratio in Kconfig matches R7/R8 (100 kΩ / 100 kΩ, ratio 200).

### 6. OTA issues

- **OTA image rejected:** Ensure `--manufacturer-code 0x1234` and `--image-type 0x0001` match the hardcoded values in `components/zigbee/zigbee.c`. Do not use `0xFFFF` wildcards.
- **OTA stalled:** Check that the `.zigbee` file is in `/opt/zigbee2mqtt/data/ota/` and that `ota: true` is set in the converter. The stall timeout is `CONFIG_WELLD_OTA_STALL_TIMEOUT_SEC` (default 240 s).
- **Version not increasing:** `ota_image_create.py` requires monotonically increasing `--file-version`. Bump `PROJECT_VER` in `CMakeLists.txt`.

## Reading the RTC Event Log

On every cold boot, the firmware prints the last 16 events from RTC memory:

```
I (main): RTC event log (last 5 entries):
I (main):   [0] t=1234s  BOOT
I (main):   [1] t=1250s  SENSOR_OK
I (main):   [2] t=1255s  ZB_FAIL
I (main):   [3] t=1560s  BOOT
I (main):   [4] t=1575s  LOW_BATT_SKIP
```

This is invaluable for diagnosing devices that failed in the field and are later retrieved. The `t=` value is seconds since the most recent cold boot (deep-sleep wakeups do not reset this counter).

| Event code | Meaning |
|---|---|
| `BOOT` | Cold boot or deep-sleep wakeup |
| `SENSOR_OK` | All sensor reads succeeded |
| `ZB_SENT` | Zigbee report acknowledged by coordinator |
| `ZB_FAIL` | Zigbee send failed or timed out |
| `LOW_BATT_SKIP` | Battery below threshold; send skipped |
| `NVS_WIPE` | 5 consecutive failures triggered NVS erase + rejoin |
| `OTA_START` | OTA download began |
| `OTA_COMPLETE` | OTA image validated; reboot imminent |
| `OTA_ABORT` | OTA aborted by stack or stall timeout |

## Diagnostic Mode (Bench Testing)

Enable `CONFIG_WELLD_DIAGNOSTIC_MODE_ENABLED=y` (via `idf.py menuconfig` → WellD Configuration). In this mode:

- The device stays awake for `CONFIG_WELLD_DIAGNOSTIC_STAY_AWAKE_SEC` (default 60 s) after each sensor read.
- Verbose INFO-level logs continue during the awake window.
- Deep sleep is still entered after the window expires, so the device does not run indefinitely.

Use this to verify sensor readings, Zigbee join behavior, and OTA query/response without recompiling between tests.

## Power Measurements

Target deep-sleep current: **< 50 µA** (typical ~20 µA with all GPIOs isolated).

If your measurement is higher:

1. **GPIO leakage:** Ensure VLOOP (GPIO5), BATT_DIV_EN (GPIO15), and CHARGER_CE (GPIO4) are all driven LOW before `esp_deep_sleep()`. The firmware does this automatically in `enter_deep_sleep()`.
2. **I²C pull-ups:** Internal pull-ups are enabled on SDA/SCL. If external pull-ups are also present, the combined resistance may leak current. Remove one set.
3. **ADS1115 power-down:** The ADS1115 enters power-down after each single-shot conversion. If DRDY is stuck low, the device may not sleep. Check GPIO12.

## Quick Checks Checklist

- [ ] Cell voltage > 3.0 V (measure across the BT1 carrier tabs — minimum safe discharge; DW01A protection trips at ≈2.4 V)
- [ ] Solar charging LED (if populated) is off or on as expected
- [ ] `idf.py monitor` shows `BOOT` → `SENSOR_OK` → `ZB_SENT` within ~10 s
- [ ] Zigbee2MQTT logs show `Device 'WellD-v1' joined` on first pairing
- [ ] MQTT payload contains `water_level`, `battery_voltage`, `temperature`
- [ ] OTA `.zigbee` file is picked up by Z2M (`z2m/OTA` log shows query response)

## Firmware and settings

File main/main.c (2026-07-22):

#include "freertos/FreeRTOS.h"
#include "freertos/task.h"
#include "esp_sleep.h"
#include "esp_attr.h"
#include "esp_log.h"
#include "esp_timer.h"
#include "esp_system.h"
#include "esp_ota_ops.h"
#include "esp_app_desc.h"
#include "nvs_flash.h"
#include "nvs.h"
#include "driver/gpio.h"
#include "sensor.h"
#include "zigbee.h"
#include "welld_core.h"
#include "sdkconfig.h"
#include "welld_nvs.h"
#include <math.h>
#include <string.h>
#include <stdint.h>

static const char *TAG = "main";

#define FAIL_THRESHOLD  5           /* NVS erase + rejoin after this many failures */


/* OTA rollback: count consecutive boots without a successful Zigbee send.
 * If the new OTA image is broken (crashes before send), we roll back to
 * the previous partition after 3 failed boot attempts.
 *
 * The counter is armed only while the running image is UNPROVEN: NVS key
 * WELLD_NVS_KEY_IMG_OK stores the version string of the last image that
 * completed a successful send. An image that has EVER sent successfully is
 * never rolled back — otherwise a routine coordinator outage (3 wakeups
 * without an ACK) would flip a healthy image back to the old slot, which
 * would then re-OTA ~1.5 MB over the radio. Storing the version string
 * (rather than a bool) self-invalidates the marker when a new image boots:
 * a fresh OTA image sees a mismatching string and is unproven until its own
 * first successful send. */
#define BOOT_ATTEMPTS_MAGIC  0x574C4403UL
#define BOOT_ATTEMPTS_LIMIT  3

RTC_DATA_ATTR static struct {
    uint32_t magic;
    uint8_t  count;   /* increments each boot, cleared on ZB_SENT */
} s_boot_attempts;

/* True when the proven-image marker in NVS matches the running image's
 * version string. Requires NVS to be initialised. */
static bool image_is_proven(void)
{
    nvs_handle_t h;
    char stored[sizeof(((esp_app_desc_t *)0)->version)];
    size_t len = sizeof(stored);
    bool proven = false;
    if (nvs_open(WELLD_NVS_NAMESPACE, NVS_READONLY, &h) == ESP_OK) {
        if (nvs_get_str(h, WELLD_NVS_KEY_IMG_OK, stored, &len) == ESP_OK) {
            proven = (strcmp(stored, esp_app_get_description()->version) == 0);
        }
        nvs_close(h);
    }
    return proven;
}

/* Stamp the running image's version string as the proven marker.
 * Called only from the post-send success path, which can never coincide
 * with the low-battery no-NVS-writes rule (the guard skips the send
 * entirely). Write-on-change: skipped when the stored string already
 * matches, so this costs one NVS commit per new image, not per wakeup. */
static void image_mark_proven(void)
{
    if (image_is_proven()) {
        return;
    }
    nvs_handle_t h;
    if (nvs_open(WELLD_NVS_NAMESPACE, NVS_READWRITE, &h) == ESP_OK) {
        const char *ver = esp_app_get_description()->version;
        esp_err_t err = nvs_set_str(h, WELLD_NVS_KEY_IMG_OK, ver);
        if (err == ESP_OK) {
            err = nvs_commit(h);
        }
        if (err == ESP_OK) {
            ESP_LOGI(TAG, "image v%s marked proven — OTA rollback disarmed", ver);
        } else {
            ESP_LOGW(TAG, "proven-image marker write: %s", esp_err_to_name(err));
        }
        nvs_close(h);
    }
}

static void boot_attempts_init(void)
{
    if (s_boot_attempts.magic != BOOT_ATTEMPTS_MAGIC) {
        memset(&s_boot_attempts, 0, sizeof(s_boot_attempts));
        s_boot_attempts.magic = BOOT_ATTEMPTS_MAGIC;
    }
    if (image_is_proven()) {
        /* This image has already sent successfully — rollback stays
         * disarmed. Pin the counter to 0 so accumulated coordinator
         * outages can never roll back a known-good image. */
        s_boot_attempts.count = 0;
        return;
    }
    s_boot_attempts.count++;
    if (s_boot_attempts.count >= BOOT_ATTEMPTS_LIMIT) {
        ESP_LOGW(TAG, "boot attempt %d/%d — rolling back to previous firmware",
                 s_boot_attempts.count, BOOT_ATTEMPTS_LIMIT);
        /* The previous image lives in the inactive OTA slot. We cannot use
         * esp_ota_get_last_invalid_partition() here: nothing ever marks the
         * old slot ESP_OTA_IMG_INVALID in this app-level rollback scheme, so
         * that call always returns NULL and rollback would never fire.
         * esp_ota_get_partition_description() gates against an empty slot
         * (first flash, no OTA yet): it fails on erased flash. */
        const esp_partition_t *run  = esp_ota_get_running_partition();
        const esp_partition_t *prev = esp_ota_get_next_update_partition(NULL);
        esp_app_desc_t prev_desc;
        if (prev && prev != run &&
            esp_ota_get_partition_description(prev, &prev_desc) == ESP_OK) {
            esp_err_t err = esp_ota_set_boot_partition(prev);
            if (err == ESP_OK) {
                ESP_LOGI(TAG, "OTA rollback → %s (v%s)", prev->label, prev_desc.version);
                /* Clear the counter before restarting: it lives in RTC memory
                 * and survives esp_restart(). Left at the limit, the rolled-
                 * back image would immediately bounce back to the broken
                 * slot on its own first boot. */
                s_boot_attempts.count = 0;
                esp_restart();
            } else {
                ESP_LOGE(TAG, "rollback failed: %s", esp_err_to_name(err));
            }
        } else {
            ESP_LOGW(TAG, "no valid previous partition to roll back to");
        }
        s_boot_attempts.count = 0;
    }
}

static void boot_attempts_clear(void)
{
    s_boot_attempts.count = 0;
}

/* A wakeup that never attempts a send (low-battery guard) must not count
 * towards rollback — the image had no chance to prove itself, and 3
 * consecutive low-battery skips would otherwise roll back an unproven-but-
 * working image. RTC-memory only; safe under the low-battery
 * no-NVS-writes rule. */
static void boot_attempts_uncount(void)
{
    if (s_boot_attempts.count > 0) {
        s_boot_attempts.count--;
    }
}

/* Factory reset: hold GPIO23 LOW at boot to erase NVS and force rejoin.
 * Internal pull-up keeps it HIGH by default; short to GND for reset. */
static bool factory_reset_check(void)
{
#ifdef CONFIG_WELLD_FACTORY_RESET_GPIO
    gpio_config_t cfg = {
        .pin_bit_mask = 1ULL << CONFIG_WELLD_FACTORY_RESET_GPIO,
        .mode         = GPIO_MODE_INPUT,
        .pull_up_en   = GPIO_PULLUP_ENABLE,
        .pull_down_en = GPIO_PULLDOWN_DISABLE,
        .intr_type    = GPIO_INTR_DISABLE,
    };
    gpio_config(&cfg);
    vTaskDelay(pdMS_TO_TICKS(10));  /* let pull-up settle */
    if (!gpio_get_level(CONFIG_WELLD_FACTORY_RESET_GPIO)) {
        ESP_LOGW(TAG, "factory reset GPIO held LOW — erasing NVS");
        ESP_ERROR_CHECK(nvs_flash_erase());
        ESP_ERROR_CHECK(nvs_flash_init());
        ESP_LOGI(TAG, "NVS erased; rebooting for clean join");
        esp_restart();
        return true;  /* never reached */
    }
#endif
    return false;
}

/* Power-profiling: time spent in each phase of the wake cycle (us).
 * Logged before deep sleep to help optimize battery life. */
static struct {
    int64_t t_i2c_init;
    int64_t t_sensors;
    int64_t t_zigbee;
    int64_t t_total;
} s_profile;

/* Bump this constant whenever the struct layout below changes.
 * A mismatch on wakeup (e.g. after an OTA that reorders fields) zeroes the
 * struct and treats the boot as cold, preventing stale data from producing a
 * spurious rate-of-change spike. Encode as 'W','E','L','D' + version byte. */
#define HISTORY_MAGIC 0x574C4401UL

/* RTC slow memory: preserved across deep sleep, zeroed on cold boot.
 *
 * Tracks the last valid water level and the cumulative time elapsed since that
 * reading (sleep duration + active phase of each intermediate wakeup) so the
 * rate-of-change calculation uses actual elapsed time rather than just the
 * programmed sleep interval. */
RTC_DATA_ATTR static struct {
    uint32_t magic;
    bool     valid;
    float    last_level_m;
    uint32_t elapsed_since_last_valid_sec;
    uint32_t pending_sleep_sec;
    uint32_t last_active_sec;   /* active-phase duration of the previous wakeup */
} s_history;

/* Store-and-forward buffer: readings saved when Zigbee send fails.
 * On the next successful send, the backlog is burst-reported so the
 * coordinator receives the full history (preserving rate accuracy).
 * Preserved across deep sleep, zeroed on cold boot. */
/* Magic bumped 0x574C4404 → 0x574C4406 when the dead sleep_sec[] field was
 * removed (RTC layout change; 0x574C4405 is taken by the RTC event log). */
#define STORE_MAGIC      0x574C4406UL
#define STORE_ENTRIES    8

RTC_DATA_ATTR static struct {
    uint32_t magic;
    uint8_t  count;
    float    level_m[STORE_ENTRIES];
    float    battery_v[STORE_ENTRIES];
    float    temp_c[STORE_ENTRIES];
} s_store;

static void store_push(float level_m, float battery_v, float temp_c)
{
    if (s_store.count >= STORE_ENTRIES) {
        /* shift oldest out */
        for (int i = 0; i < STORE_ENTRIES - 1; i++) {
            s_store.level_m[i]   = s_store.level_m[i + 1];
            s_store.battery_v[i] = s_store.battery_v[i + 1];
            s_store.temp_c[i]    = s_store.temp_c[i + 1];
        }
        s_store.count = STORE_ENTRIES - 1;
    }
    int idx = s_store.count++;
    s_store.level_m[idx]   = level_m;
    s_store.battery_v[idx] = battery_v;
    s_store.temp_c[idx]    = temp_c;
}

static void store_clear(void)
{
    s_store.count = 0;
}

/* RTC event log — small ring buffer of structured events for field debugging.
 * Preserved across deep sleep, zeroed on cold boot. Each entry is a 32-bit
 * seconds-since-boot timestamp and an 8-bit event code. */
/* Magic bumped 0x574C4402 → 0x574C4405 when head grew uint8_t → uint32_t
 * (a uint8_t head wrapped after 256 events, making rtc_log_print() report
 * an empty/short log once per wrap). */
#define RTC_LOG_MAGIC    0x574C4405UL
#define RTC_LOG_ENTRIES  16

typedef enum {
    RTC_EVT_BOOT            = 0x01,
    RTC_EVT_SENSOR_OK       = 0x02,
    RTC_EVT_ZB_SENT         = 0x03,
    RTC_EVT_ZB_FAIL         = 0x04,
    RTC_EVT_LOW_BATT_SKIP   = 0x05,
    RTC_EVT_NVS_WIPE        = 0x06,
    RTC_EVT_OTA_START       = 0x07,
    RTC_EVT_OTA_COMPLETE    = 0x08,
    RTC_EVT_OTA_ABORT       = 0x09,
    RTC_EVT_FACTORY_RESET   = 0x0B,
    RTC_EVT_BROWNOUT        = 0x0C,
    RTC_EVT_WATCHDOG        = 0x0D,
} rtc_event_t;

RTC_DATA_ATTR static struct {
    uint32_t magic;
    uint32_t head;   /* total events ever logged; index = head % RTC_LOG_ENTRIES */
    uint32_t ts[RTC_LOG_ENTRIES];
    uint8_t  ev[RTC_LOG_ENTRIES];
} s_rtc_log;

static void rtc_log_init(void)
{
    if (s_rtc_log.magic != RTC_LOG_MAGIC) {
        memset(&s_rtc_log, 0, sizeof(s_rtc_log));
        s_rtc_log.magic = RTC_LOG_MAGIC;
    }
}

static void rtc_log_event(rtc_event_t ev)
{
    uint32_t now_sec = (uint32_t)(esp_timer_get_time() / 1000000LL);
    uint32_t idx = s_rtc_log.head % RTC_LOG_ENTRIES;
    s_rtc_log.ts[idx] = now_sec;
    s_rtc_log.ev[idx] = (uint8_t)ev;
    s_rtc_log.head++;
}

static void rtc_log_print(void)
{
    if (s_rtc_log.head == 0) return;
    uint32_t count = (s_rtc_log.head < RTC_LOG_ENTRIES) ? s_rtc_log.head : RTC_LOG_ENTRIES;
    uint32_t start = (s_rtc_log.head >= RTC_LOG_ENTRIES) ? s_rtc_log.head % RTC_LOG_ENTRIES : 0;
    ESP_LOGI(TAG, "RTC event log (last %u entries):", (unsigned)count);
    for (uint32_t i = 0; i < count; i++) {
        uint32_t idx = (start + i) % RTC_LOG_ENTRIES;
        const char *name = "unknown";
        switch (s_rtc_log.ev[idx]) {
            case RTC_EVT_BOOT:          name = "BOOT";          break;
            case RTC_EVT_SENSOR_OK:     name = "SENSOR_OK";     break;
            case RTC_EVT_ZB_SENT:       name = "ZB_SENT";       break;
            case RTC_EVT_ZB_FAIL:       name = "ZB_FAIL";       break;
            case RTC_EVT_LOW_BATT_SKIP: name = "LOW_BATT_SKIP"; break;
            case RTC_EVT_NVS_WIPE:      name = "NVS_WIPE";      break;
            case RTC_EVT_OTA_START:     name = "OTA_START";     break;
            case RTC_EVT_OTA_COMPLETE:  name = "OTA_COMPLETE";  break;
            case RTC_EVT_OTA_ABORT:     name = "OTA_ABORT";     break;
            case RTC_EVT_FACTORY_RESET: name = "FACTORY_RESET"; break;
            case RTC_EVT_BROWNOUT:      name = "BROWNOUT";      break;
            case RTC_EVT_WATCHDOG:      name = "WATCHDOG";      break;
        }
        ESP_LOGI(TAG, "  [%u] t=%lus  %s", (unsigned)i, (unsigned long)s_rtc_log.ts[idx], name);
    }
}

/* NVS wear-leveling: cache the last-written value so we skip redundant
 * commits. Flash endurance is ~100k cycles; at 288 wakeups/day this
 * extends NVS life from ~1 year to effectively unlimited. */
static uint32_t s_cached_fail_count = UINT32_MAX;

static uint32_t read_fail_count(void)
{
    nvs_handle_t h;
    uint32_t count = 0;
    if (nvs_open(WELLD_NVS_NAMESPACE, NVS_READONLY, &h) == ESP_OK) {
        nvs_get_u32(h, WELLD_NVS_KEY_FAILS, &count);
        nvs_close(h);
    }
    s_cached_fail_count = count;
    return count;
}

static void write_fail_count(uint32_t count)
{
    if (count == s_cached_fail_count) {
        return;  /* no change → skip NVS write entirely */
    }
    nvs_handle_t h;
    if (nvs_open(WELLD_NVS_NAMESPACE, NVS_READWRITE, &h) == ESP_OK) {
        esp_err_t _err = nvs_set_u32(h, WELLD_NVS_KEY_FAILS, count);
        if (_err != ESP_OK)
            ESP_LOGW(TAG, "fail counter write: %s", esp_err_to_name(_err));
        _err = nvs_commit(h);
        if (_err != ESP_OK)
            ESP_LOGW(TAG, "fail counter commit: %s", esp_err_to_name(_err));
        nvs_close(h);
        s_cached_fail_count = count;
    }
}

/* Power down all peripheral GPIOs, isolate them for deep sleep, and enter
 * deep sleep for the requested duration. Called from every exit path in
 * app_main() so no wake cycle leaks power through partially-driven outputs.
 *
 * Sequence:
 *  1. sensor_pre_sleep_cleanup() — removes ADS1115 DRDY ISR (prevents a
 *     spurious GPIO22 edge from waking the CPU during sleep entry) and
 *     deletes the I2C master bus (prevents port 0 staying claimed across
 *     wakeups).
 *  2. Drive power-control outputs LOW: GPIO5 (VLOOP), GPIO15 (BATT_DIV_EN).
 *     Both are already LOW after sensor reads; driven LOW again here as a
 *     belt-and-suspenders guard before isolation.
 *  3. esp_sleep_config_gpio_isolate() — disconnects all GPIO pads from the
 *     GPIO matrix so outputs hold their last state but draw no dynamic
 *     current.  The power-control outputs are already LOW before this call
 *     so they remain LOW in isolation. */
static void enter_deep_sleep(uint32_t sleep_sec)
{
    sensor_pre_sleep_cleanup();
    gpio_set_level(CONFIG_WELLD_VLOOP_GPIO, 0);
    gpio_set_level(CONFIG_WELLD_BATT_DIV_EN_GPIO, 0);
    esp_sleep_config_gpio_isolate();
    esp_deep_sleep((uint64_t)sleep_sec * 1000000ULL);
}
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

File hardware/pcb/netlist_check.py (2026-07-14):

#!/usr/bin/env python3
"""WellD schematic netlist verifier (senior-review "netlist-vs-doc diff").

Re-extracts pin->net connectivity from the *written* .kicad_sch files by pure
geometry — pin endpoints (recomputed via the symbol transforms), wire segments,
label anchors (local / global / hierarchical), sheet pins and root-level joins
on welld.kicad_sch — and diffs the resulting partition against the intended
netlist table (NETS / NC_PINS in kicad_wire_script.py, which is derived
net-by-net from schematic_connections.md).

The extraction path shares only the low-level s-expression/transform helpers
with the generator; connectivity itself is rebuilt from the file geometry
(wires + point-on-segment label association + union-find), so a transform,
collision, or label-placement bug in the generator would surface here as a
merged/split/misnamed net.

Checks performed:
  1. every symbol pin is either in exactly one extracted net or carries an
     explicit (no_connect) marker;
  2. the extracted partition of pins into nets equals the intended partition
     (globals merged by name, hierarchical nets merged through the actual
     sheet-pin + root-label geometry of welld.kicad_sch — not by name);
  3. each extracted net carries exactly the intended label name(s);
  4. no stray labels or no_connect markers exist beyond the table.

Exit code 0 = zero mismatches.
"""

import os
import re
import sys

HERE = os.path.dirname(os.path.abspath(__file__))
sys.path.insert(0, HERE)

from kicad_wire_script import (  # noqa: E402
    GLOBAL_NETS, NC_PINS, NETS, SHEETS, TOP,
    Sheet, get_at, get_str, root_span, scan_children, seg_contains, balanced,
)


class UF:
    def __init__(self):
        self.p = {}

    def find(self, x):
        self.p.setdefault(x, x)
        while self.p[x] != x:
            self.p[x] = self.p[self.p[x]]
            x = self.p[x]
        return x

    def union(self, a, b):
        self.p[self.find(a)] = self.find(b)


def parse_graph(path):
    """Return (wires, labels, ncs) from a sheet file. labels: (kind, name, x, y).
    Also sheet blocks for the top file: (name, pins=[(pname, x, y)])."""
    with open(path) as f:
        text = f.read()
    if not balanced(text):
        raise SystemExit(f"{path}: unbalanced s-expressions")
    rs, re_ = root_span(text)
    wires, labels, ncs, sheets = [], [], [], []
    for tag, s, e in scan_children(text, rs, re_ - 1):
        chunk = text[s:e]
        if tag == "wire":
            pts = re.findall(r"\(xy\s+([-\d.]+)\s+([-\d.]+)\)", chunk)
            a = (float(pts[0][0]), float(pts[0][1]))
            b = (float(pts[1][0]), float(pts[1][1]))
            wires.append((a, b))
        elif tag in ("label", "global_label", "hierarchical_label"):
            m = re.match(r'\(%s\s+"((?:[^"\\]|\\.)*)"' % tag, chunk)
            at = get_at(chunk)
            labels.append((tag, m.group(1), at[0], at[1]))
        elif tag == "no_connect":
            at = get_at(chunk)
            ncs.append((at[0], at[1]))
        elif tag == "sheet":
            m = re.search(r'\(property\s+"Sheetname"\s+"((?:[^"\\]|\\.)*)"', chunk)
            crs, cre = root_span(chunk)
            pins = []
            for t2, s2, e2 in scan_children(chunk, crs, cre - 1):
                if t2 != "pin":
                    continue
                sub = chunk[s2:e2]
                pm = re.match(r'\(pin\s+"((?:[^"\\]|\\.)*)"', sub)
                at = get_at(sub)
                pins.append((pm.group(1), at[0], at[1]))
            sheets.append((m.group(1), pins))
    return wires, labels, ncs, sheets


def key(sheet, pt):
    return (sheet, round(pt[0], 3), round(pt[1], 3))


def main():
    uf = UF()
    pin_nodes = {}     # (sheet, "REF.PIN") -> node key
    nc_markers = {}    # sheet -> set of points
    labels_all = []    # (sheet, kind, name, node)

    for name in SHEETS:
        sh = Sheet(name)
        sh.resolve_pins()
        wires, labels, ncs, _ = parse_graph(sh.path)

        # wires connect their endpoints; endpoint-on-segment connects too
        pts = []
        for a, b in wires:
            uf.union(key(name, a), key(name, b))
            pts.extend([a, b])
        for kind, lname, x, y in labels:
            pts.append((x, y))
        for pid, info in sh.pins.items():
            pts.append((info["x"], info["y"]))
        # point-on-segment attachment (KiCad: wire endings and label anchors
        # or pin ends that lie on a wire are connected to it)
        for p in pts:
            for a, b in wires:
                if seg_contains(p, a, b):
                    uf.union(key(name, p), key(name, a))
        # coincident points connect implicitly via identical keys

        for pid, info in sh.pins.items():
            pin_nodes[(name, pid)] = key(name, (info["x"], info["y"]))
        nc_markers[name] = {key(name, p) for p in ncs}

        for kind, lname, x, y in labels:
            node = key(name, (x, y))
            labels_all.append((name, kind, lname, node))
            if kind == "global_label":
                uf.union(node, ("GLOBAL", lname))
            elif kind == "hierarchical_label":
                uf.union(node, ("HIER", name, lname))
            else:  # KiCad: local labels connect by name within one sheet
                uf.union(node, ("LOCAL", name, lname))

    # ---- top sheet: sheet pins + root wires/labels merge hierarchical nets
    top_path = os.path.join(HERE, f"{TOP}.kicad_sch")
    wires, labels, ncs, sheets = parse_graph(top_path)
    pts = []
    for a, b in wires:
        uf.union(key(TOP, a), key(TOP, b))
        pts.extend([a, b])
    for kind, lname, x, y in labels:
        pts.append((x, y))
    for sname, pins in sheets:
        for pname, x, y in pins:
            pts.append((x, y))
    for p in pts:
        for a, b in wires:
            if seg_contains(p, a, b):
                uf.union(key(TOP, p), key(TOP, a))
    for kind, lname, x, y in labels:
        node = key(TOP, (x, y))
        if kind == "global_label":
            uf.union(node, ("GLOBAL", lname))
        elif kind == "label":  # root-level local labels connect by name
            uf.union(node, ("LOCAL", TOP, lname))
    for sname, pins in sheets:
        for pname, x, y in pins:
            uf.union(key(TOP, (x, y)), ("HIER", sname, pname))

    # ---- extracted partition: root -> set of (sheet, pin)
    extracted = {}
    for (sheet, pid), node in pin_nodes.items():
        extracted.setdefault(uf.find(node), set()).add((sheet, pid))
    # net names attached to each root
    root_names = {}
    for sheet, kind, lname, node in labels_all:
        root_names.setdefault(uf.find(node), set()).add(lname)
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

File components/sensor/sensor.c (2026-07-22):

#include "sensor.h"
#include "driver/i2c_master.h"
#include "driver/gpio.h"
#include "onewire_bus.h"
#include "ds18b20.h"
#include "esp_log.h"
#include "freertos/FreeRTOS.h"
#include "freertos/task.h"
#include "freertos/semphr.h"
#include "sdkconfig.h"
#include "nvs_flash.h"
#include "nvs.h"
#include "welld_nvs.h"
#include <limits.h>

static const char *TAG = "sensor";

/* INT32_MIN is used as a sentinel meaning "not yet loaded from NVS".
   Avoids an NVS read on every call after the first wakeup. */
static int s_offset_cm = INT32_MIN;

/* I²C bus and device handles — initialised by sensor_i2c_init(). */
static i2c_master_bus_handle_t  s_i2c_bus = NULL;
static i2c_master_dev_handle_t  s_ads_dev = NULL;

/* Binary semaphore released by the ADS1115 DRDY falling-edge ISR.
 * Created in ads1115_drdy_init(); NULL means DRDY GPIO is not configured. */
static SemaphoreHandle_t s_ads_drdy_sem = NULL;

/* ISR handler: DRDY (GPIO22) fell — conversion complete. */
static void IRAM_ATTR ads1115_drdy_isr(void *arg)
{
    BaseType_t woken = pdFALSE;
    xSemaphoreGiveFromISR(s_ads_drdy_sem, &woken);
    if (woken) {
        portYIELD_FROM_ISR();
    }
}

/* Configure power-control GPIO outputs and drive them to their safe-idle state.
 * GPIO5 (VLOOP) and GPIO15 (BATT_DIV_EN) are driven LOW (peripherals off).
 * The chargers (TP4056, CN3791) are autonomous — no charger-enable GPIO. */
static void power_gpio_init(void) {
    const int pins[] = {
        CONFIG_WELLD_VLOOP_GPIO,
        CONFIG_WELLD_BATT_DIV_EN_GPIO,
    };
    gpio_config_t cfg = {
        .mode         = GPIO_MODE_OUTPUT,
        .pull_up_en   = GPIO_PULLUP_DISABLE,
        .pull_down_en = GPIO_PULLDOWN_DISABLE,
        .intr_type    = GPIO_INTR_DISABLE,
    };
    for (int i = 0; i < (int)(sizeof(pins)/sizeof(pins[0])); i++) {
        cfg.pin_bit_mask = 1ULL << pins[i];
        gpio_config(&cfg);
        gpio_set_level(pins[i], 0);
    }
}

/* ADS1115 comparator / DRDY registers */
#define ADS1115_REG_LO_THRESH   0x02
#define ADS1115_REG_HI_THRESH   0x03

/* Configure the ADS1115 ALERT/DRDY pin as a conversion-ready signal and
 * install a falling-edge ISR on GPIO CONFIG_WELLD_ADS1115_DRDY_GPIO.
 *
 * Per the ADS1115 datasheet §9.4.4: writing Lo_thresh = 0x8000 and
 * Hi_thresh = 0x7FFF overrides the comparator and makes ALERT/DRDY pulse
 * low for one conversion period when a single-shot conversion completes.
 *
 * The GPIO is open-drain so the internal pull-up must be enabled. */
static esp_err_t ads1115_drdy_init(void)
{
    /* Write Lo_thresh = 0x8000 — MSB = 1 enables DRDY mode */
    uint8_t lo_buf[3] = { ADS1115_REG_LO_THRESH, 0x80, 0x00 };
    esp_err_t ret = i2c_master_transmit(s_ads_dev, lo_buf, 3, 50);
    if (ret != ESP_OK) {
        ESP_LOGE(TAG, "ADS1115 Lo_thresh write failed: %s", esp_err_to_name(ret));
        return ret;
    }

    /* Write Hi_thresh = 0x7FFF — MSB = 0 (paired with Lo_thresh MSB = 1) */
    uint8_t hi_buf[3] = { ADS1115_REG_HI_THRESH, 0x7F, 0xFF };
    ret = i2c_master_transmit(s_ads_dev, hi_buf, 3, 50);
    if (ret != ESP_OK) {
        ESP_LOGE(TAG, "ADS1115 Hi_thresh write failed: %s", esp_err_to_name(ret));
        return ret;
    }

    /* Create the binary semaphore before installing the ISR. */
    SemaphoreHandle_t sem = xSemaphoreCreateBinary();
    if (!sem) {
        ESP_LOGE(TAG, "ADS1115 DRDY semaphore alloc failed");
        return ESP_ERR_NO_MEM;
    }

    /* Configure GPIO as input with internal pull-up (open-drain output). */
    gpio_config_t drdy_cfg = {
        .pin_bit_mask = 1ULL << CONFIG_WELLD_ADS1115_DRDY_GPIO,
        .mode         = GPIO_MODE_INPUT,
        .pull_up_en   = GPIO_PULLUP_ENABLE,
        .pull_down_en = GPIO_PULLDOWN_DISABLE,
        .intr_type    = GPIO_INTR_NEGEDGE,
    };
    ret = gpio_config(&drdy_cfg);
    if (ret != ESP_OK) {
        ESP_LOGE(TAG, "ADS1115 DRDY GPIO config failed: %s", esp_err_to_name(ret));
        vSemaphoreDelete(sem);
        return ret;
    }

    /* Install the GPIO ISR service if not already running. Ignore
     * ESP_ERR_INVALID_STATE — it just means another component started it. */
    ret = gpio_install_isr_service(0);
    if (ret != ESP_OK && ret != ESP_ERR_INVALID_STATE) {
        ESP_LOGE(TAG, "gpio_install_isr_service: %s", esp_err_to_name(ret));
        vSemaphoreDelete(sem);
        return ret;
    }

    ret = gpio_isr_handler_add(CONFIG_WELLD_ADS1115_DRDY_GPIO, ads1115_drdy_isr, NULL);
    if (ret != ESP_OK) {
        ESP_LOGE(TAG, "ADS1115 DRDY ISR add failed: %s", esp_err_to_name(ret));
        vSemaphoreDelete(sem);
        return ret;
    }

    s_ads_drdy_sem = sem;

    ESP_LOGI(TAG, "ADS1115 DRDY interrupt configured on GPIO%d",
             CONFIG_WELLD_ADS1115_DRDY_GPIO);
    return ESP_OK;
}

/* I2C bus recovery: if SDA is stuck LOW, clock out 9 pulses on SCL
 * (GPIO open-drain mode) to release any peripheral holding the bus. */
static void i2c_bus_recover(void)
{
    int sda = CONFIG_WELLD_I2C_SDA_GPIO;
    int scl = CONFIG_WELLD_I2C_SCL_GPIO;

    gpio_config_t cfg = {
        .mode         = GPIO_MODE_OUTPUT_OD,
        .pull_up_en   = GPIO_PULLUP_ENABLE,
        .pull_down_en = GPIO_PULLDOWN_DISABLE,
        .intr_type    = GPIO_INTR_DISABLE,
    };

    /* Configure SDA as input to sample its level */
    cfg.pin_bit_mask = 1ULL << sda;
    gpio_config(&cfg);
    cfg.pin_bit_mask = 1ULL << scl;
    gpio_config(&cfg);

    gpio_set_level(scl, 1);
    gpio_set_level(sda, 1);
    vTaskDelay(pdMS_TO_TICKS(1));

    if (gpio_get_level(sda) == 0) {
        ESP_LOGW(TAG, "SDA stuck LOW — performing I2C bus recovery");
        for (int i = 0; i < 9; i++) {
            gpio_set_level(scl, 0);
            vTaskDelay(pdMS_TO_TICKS(1));
            gpio_set_level(scl, 1);
            vTaskDelay(pdMS_TO_TICKS(1));
            if (gpio_get_level(sda)) {
                ESP_LOGI(TAG, "SDA released after %d clock pulses", i + 1);
                break;
            }
        }
        /* Send STOP condition: SDA LOW → SCL HIGH → SDA HIGH */
        gpio_set_level(sda, 0);
        vTaskDelay(pdMS_TO_TICKS(1));
        gpio_set_level(scl, 1);
        vTaskDelay(pdMS_TO_TICKS(1));
        gpio_set_level(sda, 1);
        vTaskDelay(pdMS_TO_TICKS(1));
    }
}
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

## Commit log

2026-05-09 Initial ESP-IDF project scaffold for ESP32-C6 well monitor
    Boot cycle: read 4-20 mA pressure transducer via ADC → connect WiFi →
    publish water level to MQTT broker → deep sleep 5 min. RTC memory caches
    the last AP channel/BSSID for faster reconnect after sleep.
    [main.c, sensor.c]
2026-05-09 Fix mqtt managed component and partition overflow
    - Switch mqtt REQUIRES to espressif__mqtt (moved to component registry in IDF 6)
    - Add main/idf_component.yml with espressif/mqtt ^1.0.0 dependency
    - Add partitions.csv giving factory app 1.9 MB (was overflowing 1 MB default)
    - Add sdkconfig.defaults to enable custom partition table
    - Ignore managed_components/ and lock file in .gitignore
    [partitions.csv]
2026-05-09 cleanup: fix wifi resource leak, MQTT fail-fast, remove noise
    - main.c: always call wifi_disconnect() so resources are freed even when
    connection fails (was only called on success)
    - mqtt_pub.c: set FAIL_BIT on MQTT_EVENT_ERROR so publish returns
    immediately on broker error instead of waiting the full 10-second timeout
    - idf_component.yml: drop boilerplate comments and bump IDF floor to 5.0.0
    (adc_oneshot / curve-fitting APIs require IDF 5)
    - sensor.h: collapse 4-line docstring to one line
    - sensor.c: remove redundant comment (the #if macro name already says it)
    https://claude.ai/code/session_0167TEXmJLzBaNRM5ucJCePA
    [main.c, sensor.c]
2026-05-09 feat: add Zigbee End Device with Analog Input cluster, WiFi/MQTT fallback
    New components/zigbee/ component registers as a HA End Device and reports
    water level (float, metres) via ZCL Analog Input cluster 0x000C attribute
    present_value (0x0055) to the coordinator (0x0000).
    Boot flow: try Zigbee first (25 s timeout); fall back to WiFi → MQTT only
    if Zigbee steering fails or times out. The Zigbee stack persists network
    state (PAN ID, channel, short address) in NVS automatically, so subsequent
    wakeups rejoin in a few seconds rather than doing a full scan.
    - components/zigbee/zigbee.c — zb_task spins up the stack in a FreeRTOS
    task; esp_zb_app_signal_handler drives the BDB commissionin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
    [main.c]
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2026-05-09 feat: battery monitoring, DS18B20 temperature sensor, configurable Zigbee, full README
    - sensor: add DS18B20 1-Wire temperature reading (GPIO4, returns -127 on error)
    - sensor: add optional battery voltage monitoring via ADC divider
    - zigbee: add endpoint 3 (Temperature Measurement cluster 0x0402) for DS18B20
    - zigbee: configurable channel mask and post-send delay via Kconfig
    - zigbee: use ESP_ZB_ED_AGING_TIMEOUT_256MIN for sleep margin
    - kconfig: add DS18B20_GPIO, BATT_ADC_CHANNEL, BATT_DIVIDER_RATIO, ZIGBEE_CHANNEL_MASK, ZIGBEE_SEND_DELAY_MS
    - sensor: idf_component.yml with espressif/onewire_bus and espressif/ds18b20 deps
    - z2m: welld.js converter with fz.temperature for ep3, custom handle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
    [main.c, sensor.c]
2026-05-10 feat: open-loop detection, DS18B20 plausibility check, NVS fail counter, unit tests
    - sensor: extract sensor_level_from_mv(); returns -1 if loop current < 3500 µA
    (transducer disconnected or open loop)
    - sensor: discard DS18B20 readings outside rated range (-55 to 125 °C)
    - main: track consecutive Zigbee failures in NVS; after 5 failures erase NVS
    to force a fresh Zigbee join (clears corrupted network state)
    - test/sensor: Unity test project for sensor_level_from_mv() covering open
    loop, 4 mA zero point, midscale, full scale, and overcurrent clamp
    [main.c, sensor.c]
2026-05-10 feat: OTA updates, battery %, level offset calibration, NVS offset storage
    OTA (Zigbee cluster 0x0019):
    - partitions.csv: dual OTA slots (2×1.5 MB) for ESP32-C6 4 MB flash
    - sdkconfig.defaults: enable custom partition table
    - zigbee.c: OTA upgrade client cluster on EP1; zb_action_handler writes
    firmware chunks to flash via esp_ota_write, reboots on STATUS_APPLY
    - zigbee.c: zb_timeout_alarm reschedules itself during OTA; zb_finish_alarm
    stays awake during OTA so the loop is not killed mid-download
    - zigbee.c: REQUIRES += app_update nvs
    - welld.js: ota: true
    Battery percentage:
    - welld.js: ep2 handler computes battery % from voltage using
    configurable battery_full_mv / battery_empty_mv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
    [partitions.csv]
2026-05-10 feat: OTA updates, battery %, level offset calibration, NVS offset storage; fix OTA failure path
    - partitions.csv: dual OTA slots (2x1.5 MB) + otadata for ESP32-C6 4 MB flash
    - zigbee.c: OTA write/finalise failure now sets FAIL_BIT and stops the loop
    immediately instead of waiting for the next 25 s timeout alarm
    - zigbee.c: zb_timeout_alarm reschedules during OTA; zb_finish_alarm stays
    awake during OTA so the loop is not killed mid-download
    - zigbee.c: REQUIRES += app_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
    [sensor.c]
2026-05-10 fix: security and optimization improvements from code review
    - OTA: replace 0xFFFF wildcard manufacturer/type with specific values
    (OTA_MANUFACTURER_CODE=0x1234, OTA_IMAGE_TYPE=0x0001) to prevent
    arbitrary firmware being pushed by rogue OTA servers
    - OTA: stop Zigbee loop immediately on write or finalise failure instead
    of waiting up to TOTAL_TIMEOUT_MS for the timeout alarm to fire
    - OTA: increase max_data_size 64→128 to halve OTA download time
    - Zigbee: increase zb_task stack 8192→10240 words for OTA headroom
    - Zigbee: add comments explaining the two-alarm design (zb_finish_alarm
    and zb_timeout_alarm) and their interaction with s_ota_in_progress
    - sensor: clamp NVS offset to ±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
    [main.c, sensor.c]
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2026-05-10 docs: add thorough inline comments to all three source files
    - zigbee.c: document the event-group lifecycle (SENT/FAIL/STOPPED bits),
    volatile rationale for s_ota_in_progress, OTA state machine flow,
    BDB commissioning sequence, endpoint layout, OTA cluster config fields,
    send_reports attribute-set-before-report pattern, zigbee_send contract
    - sensor.c: document 4-20 mA formula and 3.5 mA open-loop threshold,
    INT32_MIN sentinel, ADC averaging rationale, curve-fitting vs linear
    fallback, offset-applied-after-pure-calc separation, DS18B20 discovery
    loop, BATT_DIVIDER_RATIO encoding
    - main.c: document the wakeup cycle order (sensors before radio), NVS
    erase recovery, fail counter w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
    [main.c, sensor.c]
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2026-05-11 fix: clamp offset in sensor_set_offset_cm, not just on read
    The bounds check existed only in sensor_get_offset_cm, so a caller
    passing INT_MAX would write a wild value to NVS. Clamping in the setter
    ensures NVS is always within ±600 cm regardless of the call site.
    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
    [sensor.c]
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2026-05-14 Fix all sensor/zigbee component API renames for 1.x releases
    sensor.c:
    - ds18b20_new_device → ds18b20_new_device_from_enumeration
    - onewire_del_bus → onewire_bus_del (both occurrences)
    - ds18b20_trigger_temperature_conversion(device) →
    ds18b20_trigger_temperature_conversion_for_all(bus)
    sensor/idf_component.yml:
    - onewire_bus/ds18b20: ^0.1.0 → >=1.0.0 (components only ever had 1.x releases)
    zigbee/idf_component.yml:
    - esp-zigbee-lib/esp-zboss-lib: ^1.5.0 → ^1.6.0 (code uses 1.6.x API;
    prevent accidentally getting 1.5.x which still had the old API)
    [sensor.c]
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2026-05-14 test: extract pure helpers and expand unit-test coverage
    - new welld_core component holds testable helpers extracted from main
    (fail-counter state machine) and zigbee (temp encoding, battery skip,
    ZCL string packing); main and zigbee now call into them
    - sensor.c grows pure helpers for battery divider math and temperature
    range validation; sensor_offset_cache_reset lets tests verify the
    NVS round-trip without rebooting
    - test/sensor adds NVS offset round-trip + clamping, dead-band/threshold
    boundaries, battery and temperature helper coverage
    - new test/welld_core app exercises the extracted helpers
    - zigbee2mqtt converter logic moved into lib/welld_convert.js with a
    node:test sui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
    [main.c, sensor.c]
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2026-05-15 feat: adaptive sleep + level rate-of-change reporting
    Two related features built on the same RTC-memory history:
    1. **Level rate of change.** The device remembers its last valid water
    level and the cumulative elapsed time across any intervening invalid
    wakeups (in RTC slow memory, preserved across deep sleep, zeroed on
    cold boot). Each cycle it computes a signed cm/h rate and reports it
    on a new Zigbee endpoint EP4 as water_level_rate. Distinguishes "well
    recovering" from "well being drawn down" — the single most useful
    well diagnostic. Skipped silently on the first valid wakeup (no
    baseline yet) and during open-loop cycles.
    2. **Adaptive sleep duration.** When CONFI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
    [main.c]
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2026-05-15 docs: fix three errors in wiring diagram
    - DS18B20 pull-up: the 4.7 kΩ was sharing the same x-column as the
    GPIO4 turn, making it look like the resistor was in series with GPIO4.
    Moved pull-up to a distinct x position so it is clearly a separate
    branch from +3.3V to the DATA line, with GPIO4 connecting directly.
    - Transducer (−) wire was drawn in GND colour (black). That node sits at
    0.4–2.0 V — not ground — so it is now blue (signal colour).
    - Removed dangling 3V3 and GND stubs on the board left side that
    connected to nothing. Power symbols (+3.3V / GND) are used throughout
    per standard schematic convention; a note at the bottom explains this.
    https://claude.ai/code/se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
    [gen_wiring_diagram.py]
2026-05-15 docs: redesign wiring diagram for legibility
    Completely rewrite gen_wiring_diagram.py to address text-over-trace
    overlap. Key changes:
    - Expand canvas to 22×14 inches
    - ann() helper places italic grey annotations above wire paths (never on them)
    - resistor_v/h() labels beside/above body, not inside the tiny rectangle
    - Larger fonts (9–10.5 pt vs 7–8 pt)
    - Darker, more professional colour palette
    - Correct pull-up topology: GPIO4 goes direct to DATA, separate 4.7 kΩ
    branch from junction dot to +3.3V
    - GND_R board pin explicitly routed to DS18B20 GND junction
    - Colour key legend in bottom-right corner
    - Footer explains GND/VCC symbol convention
    https://claude.ai/code/session_01SkQgoMC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
    [gen_wiring_diagram.py]
2026-05-15 docs: use actual ESP32-C6-DevKitC-1 pinout in wiring diagram
    Replace the generic board rectangle with a true DevKitC-1 layout:
    - All 16 left (J1) and 15 right (J3) header pins labeled
    - Used pins (GPIO0, GPIO1, GPIO4, 3V3, GND) highlighted in colour;
    unused pins rendered in grey so they don't distract
    - USB connector stub drawn at board bottom edge
    - ESP32-C6 module silkscreen shown inside board body
    - GPIO4 wire now exits the correct left-side pin and routes over
    the board top (realistic prototype wire path) to reach DS18B20
    - Pull-up junction dot sits on the GPIO4/DATA wire, not floating
    - DS18B20 GND routed from right-header GND pin around box edge
    https://claude.ai/code/session_01Sk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
    [gen_wiring_diagram.py]
2026-05-15 docs: fix DS18B20 VCC/GND routing and GPIO0 wire overlap
    Five verified bugs corrected:
    1. DS18B20 VCC wire was hidden — it ran through the box interior
    (wire zo=2 under box zo=3). Now: external left-side stub, +3.3V
    rail symbol at stub end, no wire inside the box.
    2. DS18B20 GND wire entered box from the right and was hidden.
    Now: GND earth symbol at the left-side GND stub.
    3. GPIO0 wire went straight down from junction, overlapping the
    shunt wire on the same x column AND passing through the 100 Ω
    resistor body. Now: exits junction rightward, turns at x=9.4,
    no overlap with any shunt element.
    4. Right board GND pin was highlighted but the routing was complex
    and i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
    [gen_wiring_diagram.py]
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2026-05-16 docs: restore 10-30V loop supply; add buck converter + 24V shared rail (#26)
    Transducer requires 10-30V DC (per sensor spec sheet), so 3.3V and 5V
    are incompatible. Changes:
    - Restore loop supply box labelled '10-30 V DC'; output wire now exits
    box BOTTOM and transducer RIGHT WALL so no wire ever enters either
    box interior
    - Add buck converter box (24V → 5V) above DS18B20; 5V output routed
    left then down to board J3 5V pin (now marked used)
    - Add shared 24V DC bus rail above the GPIO4 over-board wire, joining
    loop supply and buck converter — one external PSU powers everything,
    eliminating the USB power bank auto-shutoff problem
    - Canvas height 16 → 17 to give the bus rail cle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
    [gen_wiring_diagram.py]
2026-05-16 Fix all EE audit findings (S1/S2/F1/F2/R1-R5/M1-M5)
    Safety (S1, S2): cap WELLD_SENSOR_SHUNT_MILLIOHMS at 155000 mΩ
    (155 Ω × 20 mA = 3.1 V, top of ADC linear range) and
    WELLD_BATT_DIVIDER_RATIO minimum at 136 (1.36:1 keeps 4.2 V Li-ion
    inside the 3.6 V ADC abs-max). Both had ranges that allowed values
    that would damage the GPIO pin.
    Functional (F1): preserve calibrated sensor offset across the NVS
    full-wipe triggered by 5 consecutive Zigbee failures. Previously the
    offset was read, logged, then silently discarded. Now sensor_offset_
    cache_reset() + sensor_set_offset_cm() re-saves it immediately after
    nvs_flash_init().
    Functional (F2): add HISTORY_MAGIC to the RTC_DATA_ATTR struct.
    A mism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
    [main.c, sensor.c]
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2026-05-16 Add gh0stee.com branding, ASSEMBLY.md, and cable-gland renders
    - welld_case.scad: debossed two-line branding (WellD + gh0stee.com),
    fix sma_z and label_cx forward-reference bugs so `use <>` works
    without undef warnings
    - ASSEMBLY.md: full 13-section build guide covering SMD assembly,
    M16 cable gland spec/selection, heat-set inserts, sensor wiring,
    sealing, and Zigbee commissioning
    - Renders: case_assembly_branded, case_lid_branded (branding visible
    at grazing angle), case_glands_front (5 glands + orange sensor
    cables), case_glands_back (SMA bulkhead hole + solar gland)
    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
    [welld_case.scad]
2026-05-16 Add Gerber fabrication package and generate_gerbers.py
    generate_gerbers.py: self-contained Python 3 script (stdlib only) that
    emits a complete fab package from the embedded placement data. No
    KiCad binary or pcbnew module required.
    gerbers/:
    welld-F_Cu.gbr 237 pad flashes (SMD + THT front annular rings)
    welld-B_Cu.gbr THT back annular rings
    welld-F_Mask.gbr solder-mask openings, front (pad + 0.1mm clearance)
    welld-B_Mask.gbr solder-mask openings, back
    welld-F_Paste.gbr 193 stencil openings (SMD only, no-paste pads excluded)
    welld-F_SilkS.gbr reference-designator positions
    welld-Edge_Cuts.gbr 80×55mm board outline
    welld-PTH.drl 32 plated holes (Pho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
    [welld-B_Cu.gbr, welld-B_Mask.gbr, welld-Edge_Cuts.gbr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]
2026-05-16 Add concrete well-lid underside mounting to enclosure and assembly guide
    welld_case.scad:
    - concrete_mount=true adds four M6 corner wings to the lid
    (22×22mm tabs, 6.6mm clearance hole, 12.5mm nut counterbore 6mm deep)
    - Bolt pattern: 107mm × 82mm centre-to-centre (fits standard well lids)
    - drill_template() module: 0.3mm-thick 1:1 printable anchor drill guide
    with 2mm holes marking the four anchor positions; 129×104mm outer frame
    - SHOW_DRILL_TEMPLATE flag to export template as separate STL
    - Inline comments doc the mounting orientation (lid face to concrete,
    base hanging down, SMA antenna facing open air column)
    ASSEMBLY.md:
    - Renumbered section 13 → concrete lid mounting (8 st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
    [welld_case.scad]
2026-05-16 hw rev 2: VLOOP boost, ADS1115, MAX17048, charger interlock, battery divider gate
    Implements all hardware improvement recommendations for the custom PCB:
    - U8 TPS61023DCKR: 12 V synchronous boost converter (VBAT→VLOOP), GPIO5-gated,
    <1 µA Iq when disabled; powers 2-wire 4–20 mA transmitters without a bench supply
    - U9 ADS1115IDGST: 16-bit I²C ADC (addr 0x48, ±2.048 V PGA) replaces ESP32 ADC
    for depth and battery channels — drops non-linearity from ±5 % to 0.01 %
    - U10 MAX17048G+T10: coulomb-counting fuel gauge (addr 0x36, ALRT→GPIO14)
    gives accurate SoC % instead of raw voltage estimation
    - Q1 2N7002: TP4056 CE interlock (GPIO4) — firmware disables USB charging
    when so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
    [bom.csv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]
2026-05-16 config: Rev 2 Kconfig options, fix stubs/examples, Z2M NaN guard, docs
    - main/Kconfig.projbuild: add "Rev 2 Hardware I/O" menu with I2C SDA/SCL,
    VLOOP, charger CE, solar detect, battery divider, MAX17048 ALRT GPIOs
    - sensor/Kconfig: document ±600 cm offset clamp in help text
    - zigbee/CMakeLists.txt: fix OTA version comment (0x00MMmmPP → 0xMMmmPP00)
    - test/host/stub_sdkconfig/sdkconfig.h: add CONFIG_WELLD_SENSOR_OFFSET_CM
    and Rev 2 GPIO stubs to prevent host build breaks
    - sdkconfig.defaults.local.example: add all Rev 2 GPIO options and adaptive
    sleep options with commented examples
    - zigbee2mqtt/welld.js: guard null/NaN presentValue in converter functions
    (prevents HA receiving Na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
    [bom.csv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]
2026-05-16 fw: ADS1115 + MAX17048 I2C drivers, GPIO power control, bug fixes
    - sensor.c: implement sensor_i2c_init() — initialises shared I2C bus
    (GPIO10 SDA / GPIO11 SCL) and registers ADS1115 (0x48) + MAX17048 (0x36)
    - sensor.c: add ads1115_read_mv() — single-shot 16-bit read, ±2.048V PGA,
    AIN0 (4-20mA shunt) or AIN2 (battery divider)
    - sensor.c: sensor_read_level() now gates VLOOP (GPIO5 HIGH 5ms soft-start)
    and reads AIN0 instead of internal ESP32 ADC
    - sensor.c: sensor_read_battery_v() prefers MAX17048 VCELL register;
    falls back to ADS1115 AIN2 via gated battery divider (GPIO15)
    - sensor.c: add sensor_read_battery_vcell_v() and sensor_read_battery_soc()
    for MAX17048 fuel gauge (VCEL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
    [main.c, sensor.c]
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2026-05-16 security: fix all audit findings (M1, M2, L1-L4, I1-I3)
    M1 sensor.c: cast ADS1115 raw bytes through uint16_t before int16_t to
    avoid implementation-defined behaviour on values > 32767 in C99.
    M2 welld_convert.js: guard battery percentage against division by zero
    when battery_full_mv == battery_empty_mv; return undefined.
    L1 zigbee.c: return ESP_FAIL from OTA handler when no update partition
    is found, signalling the stack instead of silently breaking.
    L2 zigbee.c: log a warning at the welld_pack_zcl_string call site when
    the app version string is truncated to fit the ZCL 16-char limit.
    L3 zigbee.c: add portMEMORY_BARRIER() after sensor-value writes in
    zigbee_send(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
    [sensor.c]
2026-05-16 fix: esp_timer REQUIRES in zigbee, esp_sleep_config_gpio_isolate rename
    ESP-IDF v5.x strict component checking requires esp_timer to be listed
    in zigbee/CMakeLists.txt REQUIRES since zigbee.c includes esp_timer.h.
    esp_sleep_gpio_isolate() was renamed to esp_sleep_config_gpio_isolate()
    in ESP-IDF v5.x; update both call sites in main.c.
    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
    [main.c]
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2026-05-17 hardware: fix concrete mount wing attachment and set grey-blue colour
    mount_wing_tab: add 5 mm overlap into the lid corner so each wing is
    solidly fused when unioned, eliminating the floating-tab appearance.
    Wings are now in the lid() union() block instead of appended after the
    difference(), so CGAL sees a single merged solid.
    Add CASE_COLOR = [0.47, 0.58, 0.68] (grey-blue / ~RAL 5014) applied
    via color() at every top-level render call. Switch CLI renders from
    --render (CGAL, ignores color()) to preview mode so the colour is
    respected. Regenerate all 15 PNGs.
    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
    [welld_case.scad]
2026-05-17 hardware: fix mounting geometry bugs; regenerate renders
    Wall mounting tabs (tab_w 12→8 mm, tab_offset 8→4 mm): tabs were
    bleeding 5.4 mm below the base floor and 2.4 mm above the closed lid.
    Both tabs now sit fully within the 17.1 mm shell height (Z 0.6–8.6 mm
    and 8.6–16.6 mm).
    Concrete mount wings: add wing_t = 8 mm independent of lid_t = 3 mm.
    The previous design used lid_t for the wing thickness so the M6 nut
    counterbore (mount_cbore_h = 6 mm) punched 3 mm through the lid,
    leaving zero material. wing_t = 8 mm gives 2 mm of material at the
    concrete face with the counterbore on the interior (accessible) face.
    Regenerate all 15 renders.
    https://claude.ai/code/session_018ZxeCz2XE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
    [welld_case.scad]
2026-05-17 fix(case): TPU gasket, lid-lip geometry, 3× M16 glands, M3 counterbore, M12 prog gland
    Geometry fixes:
    - Lid lip formula corrected: lip_x/y = wall + lip_clearance (0.3 mm), lip_ow/od =
    pcb_w/d - 2×lip_clearance so the lip actually fits inside the 80×55 mm base interior
    - Suppress inner lip when concrete_mount=true — lip would press against concrete ceiling
    when lid is flipped; gasket sealing is used instead
    - m3_cbore_h: 3.5 → 2.5 mm (3.5 > lid_t=3 caused 0.5 mm breakthrough into exterior)
    Cable gland fixes:
    - Bottom wall: 5× M16 → 3× M16 (5×20.5 mm in 80 mm was geometrically impossible, holes
    overlapped; 3× gives 26.7 mm centres with 6.2 mm material between holes)
    - Prog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
    [welld_case.scad, welld_gasket.stl]
2026-05-17 Bring PCB schematic/layout in sync with the design docs
    The KiCad generator was a revision behind the design notes and BOM:
    the 12 V boost (U8), external ADC (U9), fuel gauge (U10), charger
    interlock (Q1/Q2), boost inductor (L1), solar TVS (D8) and their
    passives were documented but absent from welld.kicad_sch/.kicad_pcb.
    Add them to generate_kicad.py, with TPS61023/ADS1115/MAX17048 symbols,
    and regenerate.
    Fix schematic/layout bugs: duplicate ESP32-C6 pin number, missing
    GPIO14, stale DW01A symbol (now S-8261A), JST PH footprint on J1
    (now JST XH), ADS1115 SOIC-8 footprint (now MSOP-10/VSSOP-10, the
    correct 10-pin package), and two off-board component placements.
    Add the missing TP4056 CE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
    [bom.csv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]
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2026-05-18 PCB analog/protection/interlock fixes + three new agents
    Analog front-end:
    - C3, C5: 100nF → 1µF to lower RC filter corner from 15.9kHz to 1.6kHz
    - Add FB1 (BLM18KG601SN1D ferrite) + C23/C24 (ADS1115 VDD bypass) to isolate
    the 16-bit ADC supply from TPS61023 switching noise and 2.4GHz radio
    Transient protection:
    - Add D9/D10 (SMAJ5.0CA, bidirectional, 400W) at J4/J5 SIG terminals before
    the shunt resistors — IEC 61000-4-5 surge protection for well-head cables
    - Add D11 (SMAJ13A, 13V standoff, 400W) on VLOOP rail between U8 and field
    terminals to clamp cable back-EMF and lightning-induced transients
    Charger interlock:
    - Fix GPIO6 polarity throughout: CN3791 CHRG is active-LOW (wa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
    [bom.csv, welld.kicad_pcb, welld.kicad_sch]
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2026-05-18 firmware: fix low-batt protection, I2C error handling, OTA abort, ADS1115 polling
    - Remove ADC-channel guard from low-battery skip-send path so MAX17048-only
    builds still protect the cell from brown-out during Zigbee TX.
    - Check sensor_i2c_init() return value and abort wakeup on failure instead
    of continuing with a broken bus.
    - Add missing ESP_ZB_ZCL_OTA_UPGRADE_STATUS_ABORT handler to clear
    s_ota_in_progress and stop the Zigbee loop.
    - Replace fixed ADS1115 delay with OS-bit polling via
    ads1115_wait_conversion_done(); adds named register constants.
    - Extract enter_deep_sleep() helper to eliminate duplicated GPIO-low +
    esp_sleep_config_gpio_isolate() + esp_deep_sleep() logic.
    - Ce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
    [main.c, sensor.c]
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
